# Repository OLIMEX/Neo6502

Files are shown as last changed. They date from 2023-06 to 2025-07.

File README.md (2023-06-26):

# Neo6502
Neo6502 Modern Retro Computer with W65C02S processor and RP2040 memory and peripherals emulator

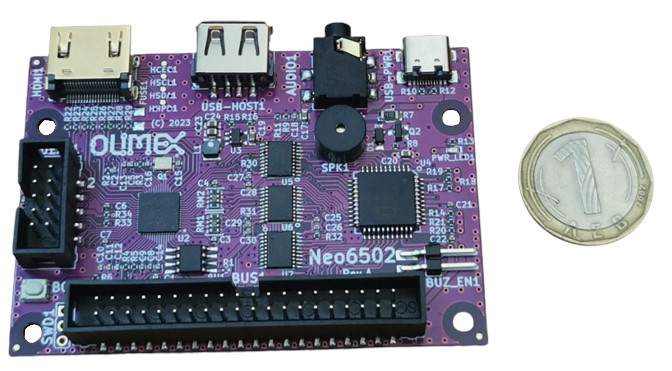
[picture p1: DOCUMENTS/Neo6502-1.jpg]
Neo6502-1


Neo6502 is small board with dimensions 80x55mm.

it consist of real W65C02S processor and RP2040 which emulates RAM memory, video, keyboard, SPI, I2C, UART, GPIOs, Sound

## Intro

W65C02S lives in The Matrix and thinks there is real RAM and other interfaces around it, but the truth is that all this is emulation of the real life. The RP2040 emulates the RAM memory, video, IO and even clock the W65C02S by PWM.

## Features

Neo6502 has these features:

* W65C02S processor
* RP2040 SOC with 2MB Flash
* DVI video on HDMI connector
* USB host for keyboard
* Audio 3.5mm output
* Speaker with enable jumper
* USB-C for power supply
* UEXT connector with I2C, UART and SPI
* 40 pin 6502 bus connector with all W65C02 signals
* Dimensions 80x55mm
* 4 mount holes

## Licenses

* Hardware is released under CERN Open Hardware Licence Version 2 - Strongly Reciprocal, all silkscreen credits to Olimex should remain;
* Software is released under GPL3 Licensee
* Documentation is released under CC BY-SA 3.0

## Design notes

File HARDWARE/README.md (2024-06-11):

Contains hardware design files for Olimex Neo6502

Board was designed with free Open Source CAD software - KiCAD, if you have trouble opening the design files use newest KiCAD version.

Folder "3D printed Case" contains STL files for multi material 3D printing of the encolosure.

STL files are designed with Fusion 360

Notable hardware revision changes:

revision B1
======
1. Added diode 1N5819/S4 on FUSE1 pads to enable 5V on HDMI (diode is used to prevent HDMI powering the board). You can try this adjustmest if you have older revision (with nothing placed over FUSE1) and problems with monitor, remember diode has direction and cathode has to be towards the HDMI connector.

revision B
======

1. Changed values P-B-V-40-LF and P-B-V-10-LF;
2. R7 set to 47R/R1206;
3. Added SWITCH1 for the speaker and signals go to the UEXT in case somebody needs them;
4. Added Neo6502 logo;
5. R1 changed NA to 10K;
6. Added attributions names and e-mail at the bottom;
7. C15 and C16 now 18pF;
8. A lot of small adjustmets to reduce soldering problems and yield.

revision A
======

Initial release.

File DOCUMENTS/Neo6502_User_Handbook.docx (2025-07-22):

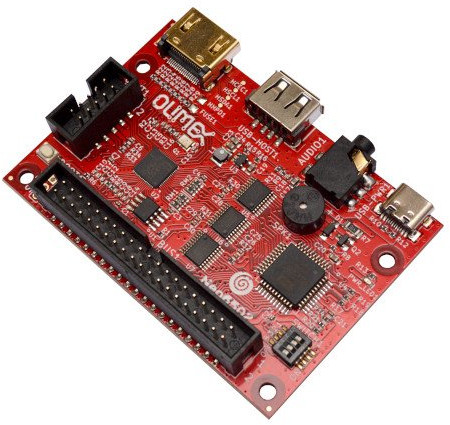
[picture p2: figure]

Neo6502 User Handbook

(Morpheus Firmware)

revision date: 20.07.2025

carefully cobbled together from various sources

slightly rearranged and moderately annotated

main sources:

- Paul Robson www.neo6502.com
- Tsvetan Usunov https://github.com/OLIMEX/Neo6502/blob/main/DOCUMENTS/Neo6502-user-manual.pdf

other sources are stated at the respective texts

all rights remain with the original authors

# 1) Introduction

The design goal of Neo6502 was to make a simple modern retro computer with 6502 processor.

A computer with a modern video interface like HDMI, USB keyboard, and USB flash drive as storage. HDMI output was chosen as everyone has a TV with HDMI input at home and USB keyboards are the mainstream device for input.

With the task to provide HDMI and USB interface we chose RP2040 which already has DVI bit bang project and USB host.

RP2040 also has enough RAM so we decided to use RP2040 to emulate also the RAM memory for 6502.

For the 6502 processor we chose W65C02 from WDC as they are still in mass production and can be purchased freely.

The Neo name was taken for two reasons, first it implies the modern design, then we liked the analogy with the movie The Matrix as W65C02 lives in a virtual world and thinks it has real memory, video, and keyboard but actually all this is virtual and emulated by the RP2040.

Neo6502 is Open Source Hardware, all CAD files, and firmware are available on github, so people can study and modify.

As the main components are a 65C02 and a Raspberry Pi Pico, the 65C02 runs the machine code (at about 6.3Mhz) and the Pico does pretty much everything else.

Most of this document describes its use for a seperate new Retrocomputer design, codenamed „Morpheus“. As such, references to files and example folders mostly apply to the contents of the Morpheus release zip file[^1].

There are other projects which use the board to emulate real machines; currently the Apple 2 and Oric are available, with Commodore 64 in development[^2].

There are other models of this board. Early adopters had a developer version which is almost identical, but Purple rather than Red, and which required a couple of wires to work properly.[^3]

There is also a 'portable' machine named the Neo6502pc, which has a LCD Screen, 4 UEXT sockets and a built in USB hub.

+ Important notice: If Neo6502 is used without a box be careful of placing it on a metal surface, also be careful of dropping metal objects on top of the PCB! This can lead to short-circuits and damage.

List of features:

- Real 65C02 Processor clocked at 6.25 Mhz executing every instruction as it was executed in early retro computers, no emulation for the processor, all timing is exact
- RP2040 with 2MB of SPI Flash, easy to load new firmware via drag and drop virtual drive
- "Clean" machine, 64k RAM available
- Storage USB Key (optionally can use SD Card)
- USB Mouse and Gamepad support
- Audio buzzer which you can enable/disable
- Audio 3.5mm connector for external audio amplifier
- Wifi support (requires additional inexpensive board)
- 6502 BUS connector with all signals
- UEXT interface to access a wide range of hardware add ons
- BASIC support for Serial, I2C and SPI hardware via UEXT Connector
- Fast structured BASIC with hardware support and inline assembler
- BASIC can be edited on screen, or using a text editor
- 320 x 240 256 colour display on HDMI/DVI with a palette
- 32k Graphics RAM for tiles and sprites
- 128 sprites up to 32x32 pixels
- Multiple tile maps (16x16 tiles, can be double sized)
- High speed drawing features
- Turtle Graphics
- Blitter for high speed graphics
- 4 channels of square wave or white noise sound
- Predefined set of sound effects.
- High Speed Integer/Floating point arithmetic
- Cross development support
- Accurate cross platform emulator for Windows/Mac/Linux, only requires SDL2
- Serial link to PC for Cross-Development
- Program in PASCAL using Mad Pascal compiler
- Program in 'C' using CC65 and LLVM
- All software and hardware is open source
- Documentation, samples, explainers and games, all open source
- Low cost purchase, sold for 30 Euros

#### Where can you buy a Neo6502?

Olimex (Europe and worldwide)

https://www.olimex.com/Products/Retro-Computers/Neo6502/open-source-hardware

The home of the Neo6502 is Plovdiv in Bulgaria, and all the hardware can be bought from Olimex, who deliver worldwide.

#### Authorised Resellers

#### Mouser (Worldwide)

https://eu.mouser.com/ProductDetail/Olimex-Ltd/Neo6502?qs=VJzv269c%252BPb5v1hcPBvA4w%3D%3D

Mouser stock Neo6502s for next day delivery.

#### The Pi Hut (UK)

https://thepihut.com/products/olimex-neo6502

For UK residents the Pi Hut is an option.

#### Agon Australia (Australia ... unsurprisingly)

https://www.tindie.com/products/agon/neo6502-rev-b-available-now/

Supporters of the truly dreadful Agon Light (note: this is not serious, it's a great piece of hardware) have come to their senses and have started stocking the Neo6502.

#### DigiKey (Worldwide)

https://www.digikey.nl/en/products/detail/olimex-ltd/NEO6502/22078296

Digikey stock Neo6502s for next day delivery

Missing suppliers who wish to be added contact me on Discord

# 2) Getting Started

Wire up the board. The board turns on as soon as power is supplied. It comes pre-flashed with an Apple 2 emulator and ProDos. For the emulator to run without major issue, leave all the dip switches in the ON position. F12 key is reset.[^4] For further information on ProDos, see: https://prodos8.com/

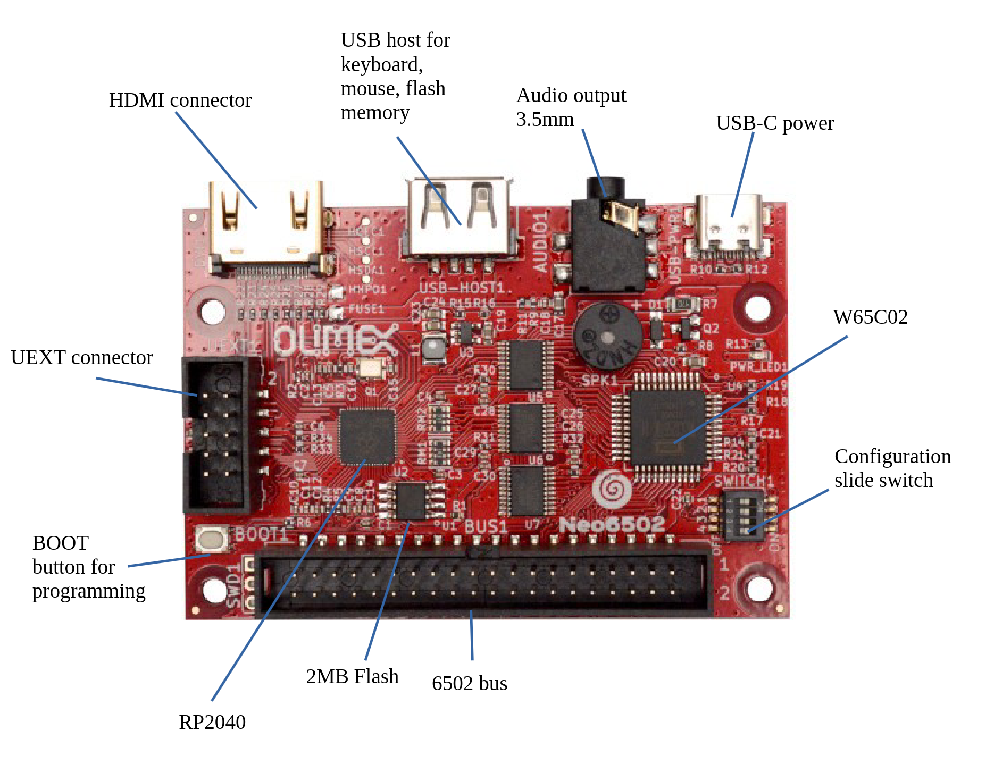
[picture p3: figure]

This next section helps you get the board up and running with the Morpheus firmware. If you want to use the Apple, Oric or C64 emulators, or any other firmware, the process is similar, but you use a different UF2 file.

#### Setting the DIP switches

There is a small configuration slide switch next to the long connector on one side of the board, marked "SWITCH1". Olimex supplies these as "all on" (as per the diagram above).

The first switch enables and disables the buzzer. Switches 2-4 connect UEXT lines to NMI, IRQ and Reset (see back side of the board) and it is strongly recommended that these are set to off.

#### USB Key

The USB key should be formatted to FAT32.

#### Wiring it up

1. Plug the HDMI Monitor into the HDMI connector using a standard HDMI cable.
2. Plug the USB hub, if you are using one, or the keyboard, into the USB host socket and plug the Gamepad, USB Key and Keyboard into the USB host
3. Plug the power cable into the USB C socket, and connect the other end to power.

As stated above, this should boot up the Apple 2 emulator, which should appear in the form of a menu of games, which you can select and run using the keyboard.

If not, try removing the USB host and just plugging the keyboard into the middle socket.

If this doesn't work, try reprogramming it with Morpheus (see below) and see what happens there.

#### Note for SD Card users

If you are using the SD card it should come with a short ribbon cable which plugs into the SDCard board and the UEXT socket on the Neo6502 board.

## Flashing the Morpheus Firmware

First you need to download the current release of the Morpheus software here:

https://github.com/paulscottrobson/neo6502-firmware

The releases are on the right of the screen. Clicking on it should show the releases page which has a link to "neo6502.zip"

Download and extract this file. You will see something like this, this is Linux, but it will be very similar on Windows or Macintosh.

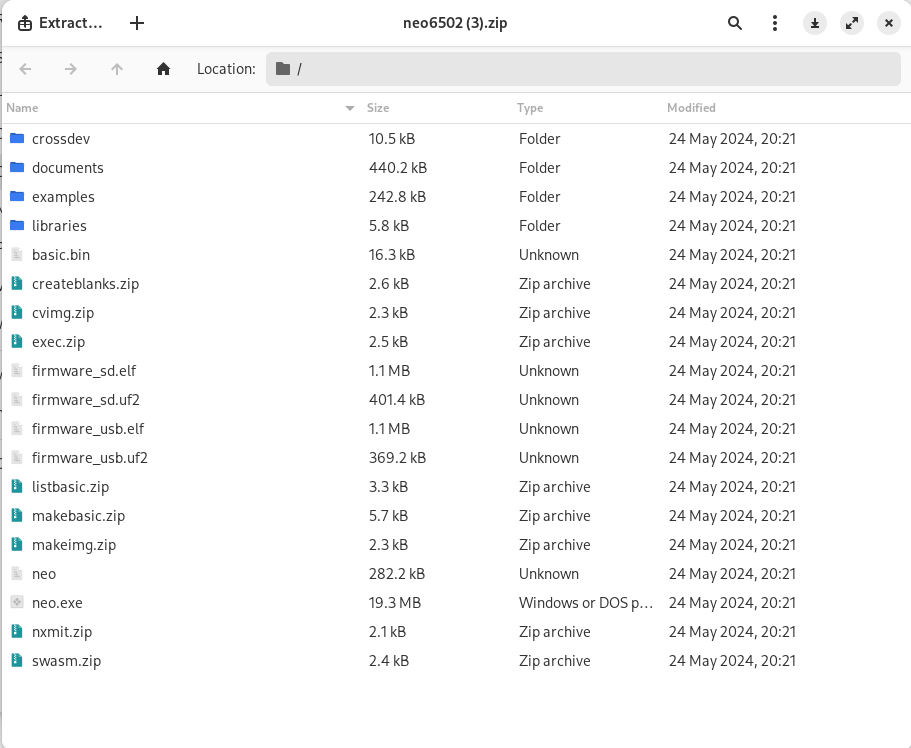
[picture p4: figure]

Initially you need one of the two files in the middle: "firmware_usb.uf2" or "firmware_sd.uf2". Most people will need the first one, the second one is if you use an SD Card for storage.

You can also copy the examples/basic files to your storage device (normally the USB key). It is recommended you create one file just for testing.

Flash the new firmware as follows:

1. Disconnect everything from the board.
2. You now need to put the board into "Upload" mode. This is a similar upload to any other Pi Pico device. Hold the boot button down (see the picture above) and connect the board to your PC via the USB-A port, then release the boot button. If you have already put the board in the case there is a hole to access the boot button which needs something thin and pointy (I use an old multimeter probe).

The board should now appear in the file system of your host computer. For example, on Linux/Gnome it is like shown below. Exactly what you see will depend on your operating system and desktop, but you should see "RPI-RP2" mounted as a drive.

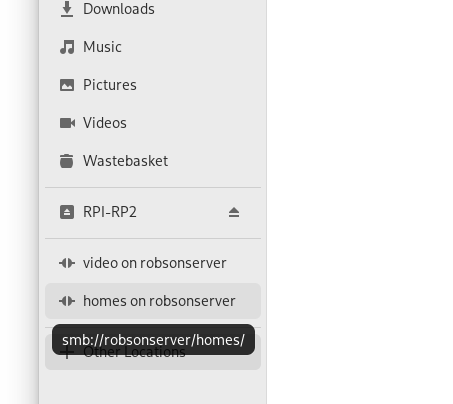
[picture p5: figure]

You now need to copy the uf2 file to this drive. This again depends on the system you are using, but drag-and-drop usually works fine.

Hopefully the board should reboot now. The machine should make it's boot sound (a low beep and a high beep - it sounds like a BBC Micro) listen here (https://www.youtube.com/watch?v=Nd9MzxIbuQI) . Disconnect the board from your PC and wire it as as discribed above. On boot it should display the Neo6502 logo, title, and Olimex title.

#### What does the boot screen mean

Below the logos, you should see:

##### Morpheus Version

The Morpheus title and version in Pink.[^5]

##### Storage Type

It should say "USB Storage" or "SD Card Storage" depending on your choice of firmware

##### USB Devices

Depending on what you connected, our USB devices should now be listed in a similar fashion to:

- No driver found for 04D9:0006
- USB Key found 0781:55a3
- Gamepad driver found 081f E401

In case not all devices are detected, this does not matter.

#### Check it works and doing a Catalogue

Below the USB list it should say "Welcome to NeoBasic" in green. You are now running a classic BASIC interpreter - so for example

print 22/7 [ENTER]

causes 3.142857 to be printed. If you type

cat

it should list all the files in the root directory of the USB key, albeit not in any particular order.

Try the following commands:

cls clears the screen

*cd (directory) change to directory

mon enters a machine code monitor

who displays the contributors list

[ESC] interrupts a BASIC program

[CTRL] + [LEFT ALT] + [RIGHT ALT (Gr)] resets the machine

Note that commands and filenames are not case-sensitive.

## Running a simple BASIC program

To get you started, and show you some of our neater features, we will write a very simple BASIC program, which many of you will have seen many times.

10 for i = 1 to 10

20 print "Hello, world !"

30 next

and type run to run it, like this:

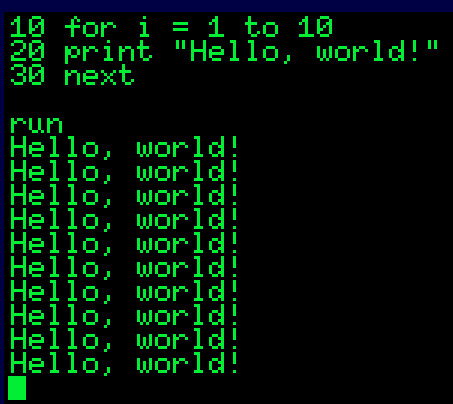
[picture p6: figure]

#### Editing, Saving, Loading and "Cat"ting

Morpheus comes with an on screen editor[^6]. You can move the arrow keys up and make the 10 at the end of line 10 to 20, press [ENTER] and run it again.

You can save your program with

save "hello.bas"

It is a convention that .bas is used for BASIC files, but it's not mandatory. You can reload it withload "hello.bas" and run it with run "hello.bas"

cat should show it stored in the directory. If you have lots of files already you can

cat "hell" which will show all files with hell in it.

## Where Next

So you now have a working Neo6502. Here are some places to explore.

#### Discord

There is an active discord where you can ask questions or whatever of the people involved in software and hardware, and ask for assistance.

There is a link to join it https://discord.gg/tTtarCcrzf

#### Facebook

There is a facebook group https://www.facebook.com/groups/745798620676673

#### Programming Languages available

C and Pascal development are currently working well (both LLVM and CC65) as well as Assembler and BASIC. Forth and a variant are currently under development. There is an early version of LLVM documentation and a more complete Pascal example on the wiki page[^7].

#### Other software

Other software is available, linked from the Wiki, now including a Tile map and Sprite editor, and a file manager, and some games.

#### Assembler, BASIC, C and Pascal examples

Under the "examples" folder are a variety of sample programs some of which are full programs, some demonstrate specific features of BASIC or the API. The .bsc files are text versions of the BASIC files.

#### The Youtube series

There is a 7 part youtube video series of about 30 minutes (https://www.youtube.com/watch?v=FbcAHRVTqpE&list=PLP0Pow806SUMAOoiHSks_xqrspu9pPwnN) which walks through programming a simple game in BASIC using cross development and external tools. Much of it is applicable to C and Pascal which uses the same API - many BASIC commands are simple wrappers round the API functions.

# 3) Software

## Starting programs at boot

On start, if there is a program called "autostart.bas" in the root directory of the storage medium, it will be run.

If this file does not exist, or the "A" key is held on power on, then this will be skipped.

This file can be created like any other BASIC file.

## Keyboard Locales

Locales are available for the following

- US (default)
- DE (Germany)
- FI (Finland)
- GB (Great Britain)
- IT (Italy)
- CH (Switzerland)
- SW (Sweden)

To create additional locale, base it on the files here (https://github.com/llvm-mos/llvm-mos-sdk/) and either create it as a pull request or send it to me personally.

The locale is set using the command: locale "abbr."

This can be included in the autostart.bas boot program, e.g.:

10 locale "GB"

Note: at present we only support ASCII characters 32-127

Example for an autostart.bas:

10 locale "GB" 'sets locale to Great Britain
20 fkey 10,chr$(12) 'maps CLS on F10
30 new 'clears autostart.bas from the BASIC interpreter

## Using MOS commands to access File functionality

The MOS interface is a way of accessing system functions such as delete, rename and so on, in one of three ways

- they can be typed in at the command line with an asterisk (e.g. *del myfile.txt)
- they can use the API function which takes a string in group 2
- they can use the BASIC command which takes a string (e.g. mos "del myfile.txt" )
- they can use the BASIC function which takes a string (e.g. print mos("del myfile.txt") )

Parameters can be delimited using spaces, single quotes or double quotes

The following commands are supported

- *. or cat , same as CAT, directory listing with mask
- *del (file) deletes a file
- *copy (file1) (file2) copies a file
- *file (file) checks a file exists
- *ren (file1) (file2) renames a file
- *md (directory) create directory
- *cd (directory) change to directory

These commands should remain unchanged but may be extended arbitrarily.

## BASIC Commands (Graphics)

The graphics commands are

- MOVE,
- PLOT (draws a pixel),
- LINE (draws a line)
- RECT (draws a rectangle)
- ELLIPSE (draws a circle or ellipse)
- IMAGE (draws a sprite or tile),
- TILEDRAW (draws a tilemap) and
- TEXT (draws text)

The keywords are followed by a sequence of modifiers and commands which do various things as listed below

Keyword | Notes
from x,y | Sets the origin position, can be repeated and optional.
to x,y | Draw the element at x,y or between the current position and x,y depending on the command. So you could have text "Hello" to 10,10 or rect 0,0 to 100,50
by x,y | Same as to but x and y are an offset from the current position
x,y | Set the current position without doing the action
ink c | Draw in solid colour c, to be placed directly after the graphics command
ink a,x | Draw by anding the colour with a, and xoring it with x.
solid | Fill in rectangles and ellipses. For images and text, forces black background.
frame | Just draw the outline of rectangles and ellipses
dim n | Set the scaling to n (for TEXT, IMAGE, TILEMAP only), so text "Hello" dim 2 to 10,10 to 10,100 will draw it twice double size. Tiles can only be 1 or 2 (when 2, tiles are drawn double size giving a 32x32 tile map)

These can be arbitrarily chained together so you can do (say) LINE 0,0 TO 100,10 TO 120,120 TO 0,0 to draw an outline triangle. You can also switch drawing type in mid command, though I probably wouldn't recommend it for clarity.
State is remember until you clear the screen so if you do INK 2 in a graphics command things will be done in colour 2 (green) until finished.
TEXT is followed by one parameter, which is the text to be printed, these too can be repeated

TEXT "Hello" TO 10,10 TEXT "Goodbye" DIM 2 TO 100,10

IMAGE is followed by two parameters, one specifies the image, the second the 'flip'. These can be repeated as for TEXT.
The image parameter is 0-127 for the first 128 tiles, 128-191 for the first 64 16x16 sprites and 192-255 for the first 64 32x32 sprites. The flip parameter, which is optional, is 0 (no flip) 1 (horizontal flip) 2 (vertical flip) 3 (both). An example would be

image 4 dim 2 to 10,10 image 192,3 dim 1 to 200,10

Note that images are $not$ sprites or tiles, they use the image to draw on the screen in the same way that LINE etc. do.

Colourcode | Colour
0 | Black/Transparent
1 | Red
2 | Green
3 | Yellow
4 | Blue
5 | Magenta
6 | Cyan
7 | White
8 | Black
9 | Dark Grey
10 | Dark Green
11 | Orange
12 | Dark Orange
13 | Brown
14 | Pink
15 | Light Grey

## Sprite Commands

Sprite commands closely resemble the graphics commands.

They begin with

- SPRITE {n} which sets the working sprite. Options include
  - IMAGE {n} which sets the image,
  - TO {x},{y} which sets the position,
  - FLIP {n} which sets the flip to a number (bit 0 is horizontal flip, bit 1 is vertical flip),
  - ANCHOR {n} which sets the anchor point and
  - BY {x},{y} which sets the position by offset.

With respect to the latter, this is the position from the TO and is used to do attached sprites e.g. you might write.

SPRITE 1 IMAGE 2 TO 200,200 SPRITE 2 IMAGE 3 BY 10,10

Which will draw Sprite 1 and 200,200 and sprite 2 offset at 210,210. It does not offset a sprite from its current position.

As with Graphics these are not all required. It only changes what you specify not all elements are required each time SPRITE 1 IMAGE 3 is fine.

SPRITE can also take the single command CLEAR ; this resets all sprites and removes them from the display

Sprite 127 is used for the turtle sprite, so if the turtle is turned on, then it will adjust its graphic, size to reflect the turtle position. If turtle graphics are not used, it can be used like any other.

Implementation notes

Up to 128 sprites are supported. However, sprite drawing is done by the Pico and is not hardware, so more sprites means the system will run slower.

Additionally, the sprites are currently done with XOR drawing, which causes effects when they overlap. This should not be relied on (it may be replaced by a clear/invalidate system at some point), but the actual implementation should not change.

This is an initial sprite implementation and is quite limited.

(The plan is to add a feature like the animation languages on STOS and AMOS which effectively run a background script on a sprite)

Sprite Support

=spritex(n) =spritey(n)

These return the x and y coordinates of the sprites draw position (currently the centre) respectively.

= hit(sprite#1,sprite#2,distance)

The hit function is designed to do sprite collision. It returns true if the pixel distance between the centre of sprite 1 and the centre of sprite 2 is less than or equal to the distance.

So if you wanted to move a sprite until it collided with another sprite, assuming both are 32x32, the collision distance would be 32 (the distance from the centre to the edge of both sprites added together), so you could write something like :

x = 0

repeat

x = x + 1: sprite 1 to x,40

until hit(1,2,32)

In my experience of this the distance needs to be checked experimentally, as it affects the 'feel' of the game ; sometimes you want near exact collision, sometimes it's about getting the correct feel. It also depends on the shape and size of the sprites, and how they move.

I think it's better than a simple box collision test, and more practical than a pixel based collision test which is very processor heavy.

## Turtle Graphics

The Neo6502 has a built in turtle graphics system. This uses sprite $7F as the turtle, which it will take over, so it cannot be used for other purposes.

The following commands are supported.

Command | Purpose
forward {n} | Move turtle forward n (pixel distance)
left {n} | Rotate turtle at current position
right {n}
penup | Does not draw as the turtle moves
pendown | Draw as the turtle moves in the current colour
pendown {n} | Draw as the turtle moves in colour {n}
turtle home | Reset turtle to home position, facing up the screen.
turtle hide | Hide the turtle
turtle show | Show the turtle
turtle fast | The turtle is deliberately slowed to give it an animated feel so you can see the drawing, this is because it's primary purpose is educational. This makes it go full speed.

There is an example in the crossdev folder which gives some idea on how to get started.

## Sound Commands

The Neo6502 has four sound channels, 0-3 which can generate a square wave or white noise sounds. The main sound command is called "sound" and has the following forms:

#### Sound clear

Resets the entire sound system, silences all channels, empties all queues

#### Sound {channel} clear

Resets a single channel ; silences it, and empties its queue

#### Sound {channel},{frequency},{time}[,{slide}]

Queues a note on the given channel of the given frequency (in Hz) and time (in centiseconds). These will be played in the background as other notes finish so you can 'queue up' an entire phrase and let it play by itself. The slide value adds that much to the frequency every centisecond allowing some additional effects (note, done in 50Hz ticks)

A mixture of the two syntaxes SOUND 0 CLEAR 440,200 is now supported. To use the white noise feature use the keyword "noise" instead of sound.

sfx plays sound effects. Sound effects are played immediately as they are usually in response to an event. It's format is: sfx {channel},{effect id}

ID | Sound
0 | positive
1 | negative
2 | error
3 | confirm
4 | reject
5 | sweep
6 | coin
7 | las70
8 | powerup
9 | victory
10 | defeat
11 | fanfare
12 | alarm 1
13 | alarm 2
14 | alarm 3
15 | ringtone 1
16 | ringtone 2
17 | ringtone 3
18 | danger
19 | expl100
20 | expl50
21 | expl20
22 | las30
23 | las10

## Using the BASIC Text Editor

The developers decided it would be better to have a proper editor. (It is possible to cross-develop in BASIC using the emulator or the serial port)

So type edit and press ENTER

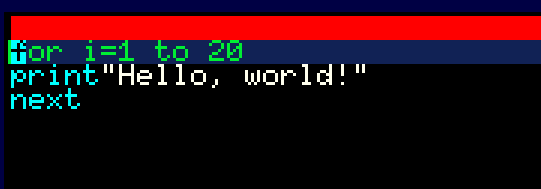
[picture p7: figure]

You can edit like on a word processor (Ctrl+P and Ctrl+Q insert/delete lines). This currently supports left, right, home, end, backspace and delete on the current line, enter, up, down, page up and page down to change lines.

Note the editor is slightly eccentric. It is not a text editor, what it is doing is editing the underlying program on the fly -- much the same as if you were typing lines in.

The editor uses its own line numbers, so is not compatible with their use in programs. Any program will be renumbered from 1 upwards in steps of 1 (except library routines).

You shouldn't be using line numbers anyway!

When you have finished press ESC to leave the editor and you can run your programm again. You can speed this up using the function keys e.g. from the BASIC command line (e.g. where you type stuff in)

fkey 1,"edit"+chr$(13)

This sets function key F1 on the keyboard to type edit and press ENTER (character code 13).

## Libraries

Libraries are part of the BASIC program, placed at the start. However, their line numbers are all set to zero. (So you cannot use GOTO or GOSUB in libraries, but you should only use them for porting old code).

NEW will not remove them, LIST does not show them (except LIST 0), You cannot edit them using the line editors.

However RUN does not skip them. This is so you can have initialisation code e.g.

{do initialisation code}

if false

proc myhw.dosomething(p1) ....

proc myhw.panic()

endif

To support this, there is a LIBRARY command. LIBRARY on its own undoes the library functionality. It renumbers the whole program from the start, starting from line number 1000.

Otherwise LIBRARY works like LIST. You can do LIBRARY {line} or LIBRARY {from},{to} and similar. Instead of listing this code, it causes them to "vanish" by setting their line numbers to zero.

They are also supported in the makebasic script. Adding the command library makes all code so far library code.

e.g.

python makebasic.zip mylib.bsc library mainprogram.bsc

## The Inline Assembler

The inline assembler works in a very similar way to that of the BBC Micro, except that it does not use the square brackets [ and ] to delimit assembler code. Assembler code is in normal BASIC programs.

A simple example shown below (and in the samples directory). It prints a row of 10 asterisks.

Most standard 65C02 syntax is supported, except currently you cannot use lsr a ; it has to be just lsr (and similarly for rol, asl, ror,inc and dec).

You can also pass A X Y as variables. So you could delete line 150 and run it with X = 12: sys start which would print 12 asterisks.

Line | Code | Notes
100 | mem = alloc(32) | Allocate 32 bytes of memory to store the program code.
110 | for i = 0 to 1 | We pass through the code twice because of forward referenced labels. This actually doesn't apply here.
120 | p = mem | P is the code pointer -- it is like $* = {xx} - it means put the code here
130 | o = i * 3 | Bit 0 is the pass (0 or 1) Bit 1 should display the code generated on pass 2 only, this is stored in 'O' for options.
140 | .start | Superfluous -- creates a label 'start' -- which contains the address here
150 | ldx #10 | Use X to count the starts
160 | .loop1 | Loop position. We can't use loop because it's a keyword
170 | lda #42 | ASCII code for asterisk
180 | jsr $fff1 | Monitor instruction to print a character
190 | dex | Classic 6502 loop
200 | bne loop1
210 | rts | Return to caller
220 | next | Do it twice and complete both passes
230 | sys mem | BASIC instruction to 'call 6502 code'. Could do sys start here.

### [ ] Operator

The [] operator is used like an array, but it is actually a syntactic equivalent of deek and doke, e.g. reading and writing 16 bytes. mem[x] means the 16 bit value in mem + x $* 2, so if mem = 813 then mem[2] = -1 writes a 16 bit word to 817 and 818, and print mem[2] reads it. The index can only be from 0..127

The purpose of this is to provide a clean readable interface to data in 65C02 and other programs running under assembly language ; often accessing elements in the 'array' as a structure.

## Further Programming

### Mad Pascal

By Tomasz Biela / Text by Wojciech Bocianski

Mad-Pascal (https://github.com/tebe6502/Mad-Pascal/releases) is a highly optimized and continuously developed cross-compiler for the Pascal language for the 6502 (https://en.wikipedia.org/wiki/MOS_Technology_6502) family of processors. Initially created for the Atari platform, it has since been adapted for several other target platforms, including neo6502.

Compilation to machine code is a two-step process. In the first step, the code is compiled to assembler source code compatible with the MADS (https://github.com/tebe6502/Mad-Assembler/releases) assembler, and then the code is assembled into an executable machine code file.

The following guide will help you set up a complete development environment, tailored for quick and convenient coding on the neo6502 on your PC. We will also write our first program together, compile it, and run it in an emulator.

#### Installing the Emulator

The first thing we will need is the latest version of the neo6502 emulator so that we can test our software on a development machine. Download it from the project's official GitHub: https://github.com/paulscottrobson/neo6502-firmware/releases

All we need for now is the emulator executable. It is located in the root directory of the downloaded archive and is simply named neo (neo.exe for Windows). Let's place it in an easily accessible directory. For the purposes of our guide, let it be the following directory:

Windows | Linux
d:/neo6502/neo.exe | ~/neo6502/neo

Note that the downloaded archive also contains a documents directory, which includes a detailed description of the API functions provided by the firmware of our device. It will certainly come in handy during our adventures with programming on the neo6502, so it's worth keeping it nearby.

#### Downloading and Compiling the Assembler and Mad-Pascal Compiler

I recommend always using the latest version of the MADS assembler and Mad-Pascal compiler, which we will compile from the sources in a moment. For this purpose, we will need the git (https://git-scm.com/downloads) tool and the free FreePascal (https://www.freepascal.org/) compiler. Both tools should be downloaded from the above links and installed.

Now, using git, we will download the latest versions of the assembler and compiler and then compile them.

#### Windows

Open a console (cmd), navigate to the directory where you want to install the compilers (in our example D:), and then execute the following commands:

git clone https://github.com/tebe6502/Mad-Assembler.git

cd Mad-Assembler

fpc -Mdelphi -vh -O3 mads.pas

cd ..

git clone https://github.com/tebe6502/Mad-Pascal.git

cd Mad-Pascal/src

fpc -Mdelphi -vh -O3 mp.pas

copy mp.exe ..

#### Linux

In the directory where you want to install the compilers (in our example in the home directory ~), enter the following console commands:

git clone https://github.com/tebe6502/Mad-Assembler.git

cd Mad-Assembler

fpc -Mdelphi -vh -O3 mads.pas

cd ..

git clone https://github.com/tebe6502/Mad-Pascal.git

cd Mad-Pascal/src

fpc -Mdelphi -vh -O3 mp.pas

cp mp ..

Be careful because the -O3 parameter is an uppercase "o", not a zero.

#### Writing Our First Program

Now let's write our first Pascal program and save it in the project directory as hello.pas:

program hello;

begin

Writeln('Hello neo6502!');

end.

Let's try to compile it manually:

Windows | Linux
D:\Mad-Pascal\mp.exe hello.pas -target:neo -code:5000 | ~\Mad-Pascal\mp hello.pas -target:neo -code:5000

The -code:5000 option will cause our program code to be compiled at address $5000 (20480). This is an example value; you can compile the code to any location, just remember not to overwrite areas used by the firmware (you can find the memory map in the emulator archive in the documents\basic.pdf directory). As a result of the compilation, an intermediate assembler file hello.a65 will be created in the project directory. In the next step, we will assemble this program into machine code, i.e., the target executable file.

Windows | Linux
D:\Mad-Assembler\mads.exe hello.a65 -x -i:D:\Mad-Pascal\base -o:hello.bin | ~\Mad-Assembler\mads hello.a65 -x -i:~\Mad-Pascal\base -o:hello.bin

The -x option causes potentially unused procedures to be removed during the assembly process, which is beneficial for us as the resulting file will be smaller. The path after the -i parameter indicates the directory with the base Mad-Pascal libraries, and the -o parameter allows you to specify the name of the output file, which should appear in the project directory after the assembly.

Let's try to run it in the emulator.

Windows | Linux
D:\neo6502\neo.exe hello.bin@5000 run@5000 | ~\neo6502\neo hello.bin@5000 run@5000

Hooray! We have successfully written our first program in Mad-Pascal for neo6502! Notice that in the emulator call, we need to specify the compilation and run address consistent with the one provided during the initial compilation.

Entering all these commands each time would be terribly inconvenient and time-consuming, so we will automate this process for our convenience and save time.

#### Preparing Batch Files for Source Compilation

In the directory of our first project, let's prepare a batch file that will do the hard work for us and carry out the process of compiling and running any Pascal file.

#### Windows

Let's create a batch file build.bat

@setlocal

@SET MPPATH=D:\Mad-Pascal

@SET MADSPATH=D:\Mad-Assembler

@SET NEOPATH=D:\neo6502

@SET ORG=5000

@SET NAME=%1

%MPPATH%\mp.exe %NAME%.pas -target:neo -code:%ORG%

@if %ERRORLEVEL% == 0 %MADSPATH%\mads.exe %NAME%.a65 -x -i:%MPPATH%\base -o:%NAME%.bin

@if %ERRORLEVEL% == 0 %NEOPATH%\neo.exe %NAME%.bin@%ORG% run@%ORG%

#### Linux

Let's create a batch file build.sh

#!/usr/bin/bash

MPPATH=~/Mad-Pascal

MADSPATH=~/Mad-Assembler

NEOPATH=~/neo6502

ORG=5000

NAME=${1}

$MPPATH/mp ${NAME}.pas -target:neo -code:${ORG} && \

$MADSPATH/mads ${NAME}.a65 -x -i:${MPPATH}/base -o:${NAME}.bin && \

$NEOPATH/neo ${NAME}.bin@${ORG} run@${ORG}

In the Linux system, the build.sh file must have execution rights:

chmod +x build.sh

Let's try to compile and run our first program using the batch file.

Windows | Linux
build.bat hello | ./build.sh hello

And if everything went well, you should see the compilation process in the console window, and then the emulator window with our first program running. If something went wrong, make sure you have the correct paths in the batch file.

Of course, you can modify and customize this batch file as you see fit, or write it completely differently. This is just an example that I hope will encourage you to experiment with Mad-Pascal.

#### Libraries for neo6502

The bare "naked" Mad-Pascal will allow us to write simple programs in text mode, but to fully exploit its capabilities on the neo6502, several additional libraries have been created. They help in communication with the device's firmware and provide full support for color graphics, sprites, tile maps, controllers, and all functions provided by the system's API.

These libraries are available to you without any additional steps as they are already part of the Mad-Pascal compiler distribution.

Library Name | Description
NEO6502 (https://bocianu.gitlab.io/neo-mplibs/neo6502.html) | Main API function library for Neo6502
NEO6502KEYS (https://bocianu.gitlab.io/neo-mplibs/neo6502keys.html) | Library for reading keyboard state using HID codes.
NEO6502MATH (https://bocianu.gitlab.io/neo-mplibs/neo6502math.html) | Library for accelerating mathematical calculations and some other operations
NEO6502UEXT (https://bocianu.gitlab.io/neo-mplibs/neo6502uext.html) | Input/output interface function library for UEXT

Link to full documentation: https://bocianu.gitlab.io/neo-mplibs/

To use these libraries, simply add their names in the uses clause.

program api;

uses neo6502, crt;

begin

ClrScr;

NeoBeep;

NeoCredits;

repeat until KeyPressed;

end.

#### Sample Programs

More sample programs utilizing specific neo6502 functions can be found in the Mad-Pascal directory in the Mad-Pascal\samples\neo6502\ subfolder. These are good examples to start with and to begin your adventure with this compiler.

And if you'd like to look at the source code of larger projects in Mad-Pascal, check out bocianu's GitLab (https://gitlab.com/bocianu), who has written several games and tools for the neo6502.

### CC65

There are two references on using CC65

Pete Gollan wrote the following, which has a sample project that can be used as a starter

https://github.com/PeteGollan/Neo6502-programs/tree/main/HelloNeo6502-CC65

Andy McCall wrote a walkthrough and example code on using a combination of LLVM-MOS and CC65 here, which is Linux / Mac centric but the basic ideas could be adapted for Windows.

https://github.com/andymccall/neo6502-development

There are some C examples in the release, but they are considerably more primitive.

### LLVM-Mos

With the new version of llvm-mos, which natively supports neo6502, you can compile your C source code (even written for the CC65 compiler) without modifying the code. Pay attention to the warnings; llvm-mos is much stricter than CC65.

Download here (https://github.com/llvm-mos/llvm-mos-sdk/): https://github.com/llvm-mos/llvm-mos-sdk/

Compile the source following the instruction inside the page

You will find useful files in the directory:

$(LLVM_MOS_SDK)/bin/mos-neo6502-clang

If you're starting from scratch, you can use the high-level functions for writing to the API mailbox. See the directory:

$(LLVM_MOS_SDK)/mos-platform/neo6502/include

Here's an example of the command to compile the code:

$(LLVM_MOS_SDK)/bin/mos-neo6502-clang main.c -o main.neo

If you use the -Os option, which allows you to have optimized code, remember that the variables with which you call the library should be of type "volatile." Don't make the same mistake as I did. If you use the LLVM_MOS high-level functions don't worry about this. And here's an example of the command to compile the optimized code:

$(LLVM_MOS_SDK)/bin/mos-neo6502-clang -Os main.c -o main.neo

If you're using VSCode to write the code, add the directory $(LLVM_MOS_SDK)/mos-platform/neo6502/include to the IncludePath variable.

In the directory, you can find an example of using the API mailbox functions:

$(LLVM_MOS_SDK)/examples/neo6502

### Assembler

Currently the best start point for assembler are the examples in the release directory.

Also, check the BASIC inline assembly examples.

Op-Codes:

https://www.pagetable.com/c64ref/6502/?cpu=65c02s&tab=0

CPU Spec-Sheet:

https://github.com/OLIMEX/Neo6502/blob/main/DOCUMENTS/w65c02s-NEW.pdf

### Tali Forth

By Scot Stevenson

https://github.com/SamCoVT/TaliForth2

https://www.olimex.com/Products/Retro-Computers/Neo6502/resources/taliforth.neo

Introduction

Tali Forth 2 is a subroutine threaded code (STC) implementation of an ANS-based Forth for the 65c02 8-bit MPU. The aim is to provide a modern Forth that is easy to get started with and can be ported to individial hardware projects, especially Single Board Computers (SBC), with little effort. It is free -- released in the public domain -- but with absolutely no warranty of any kind. Use at your own risk! (See COPYING.txt for details.) Tali Forth 2 is hosted at GitHub. You can find the most current version at https://github.com/SamCoVT/TaliForth2.

A little more detail please

Tali Forth 2 aims to be, roughly in order of priority:

- Easy to try. Download the source -- or even just the binary taliforth-py65mon.bin -- and run the emulator with py65mon -m 65c02 -r taliforth-py65mon.bin to get it running. This lets you experiment with a working 8-bit Forth for the 65c02 without any special configuration. This includes things like block wordset.
- Simple. The simple subroutine-threaded (STC) design and excessively commented source code give hobbyists the chance to study a working Forth at the lowest level. Separate documentation - including a manual with more than 100 pages - in the docs folder discusses specific topics and offers tutorials. The aim is to make it easy to port Tali Forth 2 to various 65c02 hardware projects.
- Specific. Many Forths available are "general" implementations with a small core adapted to the target processor. Tali Forth 2 was written as a "bare metal Forth" for the 65c02 8-bit MPU and that MPU only, with its strengths and limitations in mind.
- Standardized. Most Forths available for the 65c02 are based on ancient, outdated templates such as FIG Forth. Learning Forth with them is like trying to learn modern English by reading Chaucer. Tali Forth (mostly) follows the current ANS Standard, and ensures this by passing an enhanced test suite.

The functional reference for Tali is GNU Forth (Gforth, https://www.gnu.org/software/gforth/). Programs written for Tali should run on Gforth or have a very good reason not to. Also, may Gforth words were adapted for Tali, especially when they make the code simpler (like FIND-NAME or BOUNDS).

The first Tali Forth was my first Forth ever. It is hosted at https://github.com/scotws/TaliForth and is superceded by this version. The second version was strongly influenced by what I learned writing Liara Forth for the 65816. Liara and Tali 2 share large parts of their internal logic.

Seriously super lots more detail

See docs\manual.html for the Tali Forth manual, which covers the installation, setup, tutorials, and internal structure. The central discussion forum is http://forum.6502.org/viewtopic.php?f=9&t=2926 at 6502.org.

### Getting Started in Cross Development

There is a file in the release called crossdev.zip which contains a worked example of how to create both graphics and programs, with Windows and Linux support.

#### Command Line

The emulator has several options on the command line.

- "cold" boots BASIC in standard mode, avoiding the monitor
- "warm" boots BASIC in warm start mode, anything in memory will be retained.
- "exec" boots BASIC and runs the program in memory.

Program can be loaded into memory using the syntax <file>@<address in hex>. That address can be "page" which means the address BASIC expects to find the code in.

So to load and run a program use the following (adjusting for where you put the binaries) :

../bin/neo program.bas@page exec

Or in windows

..\bin\neo.exe program.bas@page exec

This performs the following 1. starts the emulator 1. loads the tokenised BASIC program to "page" (changes as BASIC grows) 1. sets it to run 'exec' mode, so it auto runs when it starts.

One can create an example BASIC program from a text equivalent (see the basic/code directory for many examples), this is done with the makebasic.zip program which requires Python 3

Something like

`python3 makebasic.zip source.txt -oprogram.bas

this converts the file "source.txt" which is a basic source file in text form, line numbers optional to a tokenised program which can be run as above.

## CP/M-65

By David Given

https://github.com/davidgiven/cpm65

https://github.com/davidgiven/cpm65/releases/download/dev/neo6502.zip

#### What?

This is a native port of Digital Research's seminal 1977 operating system CP/M to the 6502.

Unlike the original, it supports relocatable binaries, so allowing unmodified binaries to run on any system: this is necessary as 6502 systems tend to be much less standardised than 8080 and Z80 systems. (The systems above all load programs at different base addresses.)

Currently you can cross-assemble programs from a PC, as well as a working C toolchain with llvm-mos. For native development, there's a basic assembler, a couple of editors, a BASIC, and a byte-compiled Pascal subset and interpreter. You need about 20kB to run the assembler at all, and of course more memory the bigger the program.

No, it won't let you run 8080 programs on the 6502!

#### How?

You have two options:

- Download a binary release. (https://github.com/davidgiven/cpm65/releases/tag/dev) You can then copy this onto a disk for booting on a real machine, or use it in an emulator.
- or build it yourself.

#### neo6502 notes

- The neo6502 is a W65C02-based computer using emulated hardware implemented by a RP2040. This can be programmed with various different firmware packages, each emulating a different 6502-based microcomputer. This port is intended for the native firmware package for the neo6502, Morpheus (https://github.com/paulscottrobson/neo6502-firmware/wiki). (The other ports will work if you install the appropriate emulation firmware package.)
- It is ridiculously fast.
- To use, unzip the cpm65.zip file into the any directory of the USB stick or other storage card. Then enter *cd your_directory_name and then load "cpm65.neo" at the prompt. CP/M-65 will run.
- To run on the emulator, either load it as above, or boot it directly with neo CPM65.NEO@8000 run@8010. Remember that if you're running the emulator on Linux, the filesystem is CASE SENSITIVE so you need to spell CPM65.NEO using capital letters. (One CP/M-65 is running this is no longer a concern.)
- This port uses an emulated BDOS, meaning that it stores its files as FAT files on the neo6502's USB stick. Most well-behaved CP/M-65 programs will work, but anything which tries to access the raw filesystem won't; such as STAT or DINFO. Files for each drive and user are stored in separate subdirectories. All 16 drives are supported (in directories A to O).
- Drive B (i.e. /B/ on the storage device) contains some neo6502-specific utilitied. This are in no way complete, or documented.
- The console is 53x30. It has a SCREEN driver.

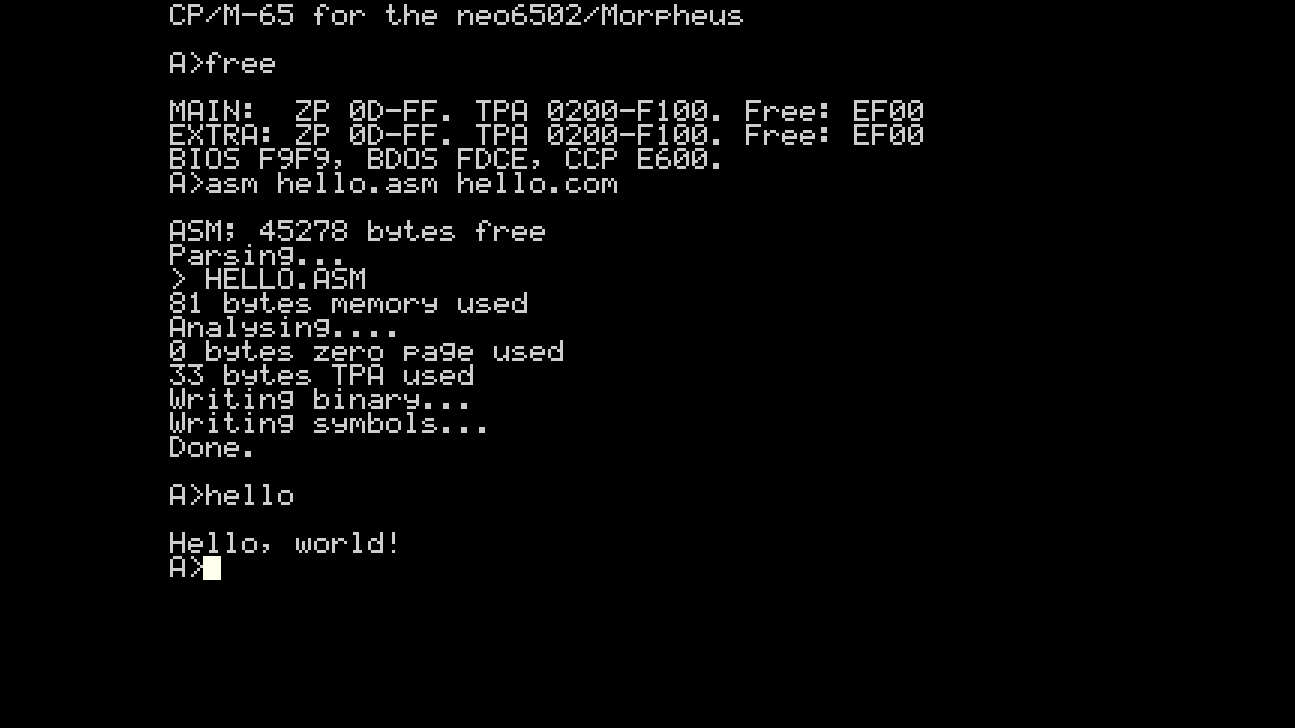
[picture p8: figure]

### Supported programs

Commands include DUMP, STAT, COPY, SUBMIT, ASM, QE and BEDIT plus some smaller utilities. I'd love more --- send me pull requests! The build system supports cc65 assembler and llvm-mos C programs. The native assembler can be used (in emulation) to cross compile programs for CP/M-65.

In the CCP, you get the usual DIR, ERA, REN, TYPE and USER. There is no SAVE as on the relocatable CP/M-65 system assembling images in memory is of questionable utility, but there's a new FREE command which shows memory usage.

You also get a port of Altirra BASIC, an open source Atari BASIC clone. This is called ATBASIC. See below for more details.

Pokey the Penguin loves to read your pull requests (https://github.com/davidgiven/cpm65/compare)!

### The assembler

The CP/M-65 assembler is extremely simple and very much customised to work for the CP/M-65 environment. It operates entirely in memory (so it should be fast) but it's written in C (so it's going to be big and slow). It's very very new and is likely to have lots of bugs. There is, at least, a port of the DUMP program to it which assembles, works, and is ready to play with.

Go read cpmfs/asm.txt (https://github.com/davidgiven/cpm65/blob/master/cpmfs/asm.txt) for the documentation.

### The BASIC

Altirra BASIC is an open source recreation of the BASIC used on the Atari 8-bit machines (on which CP/M-65 runs, coincidentally). It has been heavily modified by me to work on CP/M-65. Anything Atari-related has been removed, including graphics, sound, etc. In addition, I have extended the error reporting, added support for case-insensitive keywords (simply because Atari BASIC traditionally requires upper case but most CP/M-65 platforms don't have caps lock keys!), and fairly crudely added file I/O support. There is no screen editor. It is (should be) binary compatible with Atari BASIC, although programs using Atari features which aren't supported will of course not run.

It is currently rather fragile with a number of known (and, probably, unknown) bugs. Please file bug reports (https://github.com/davidgiven/cpm65/issues/new)!

Atari BASIC is rather different from Microsoft BASIC. Please consult the user manual (https://www.virtualdub.org/downloads/Altirra%20BASIC%20Reference%20Manual.pdf).

Important! Do not contact the author of Altirra BASIC for anything related to the CP/M-65 port! Any bugs are strictly my fault.

### The editors

BEdit is an incredibly simple line editor modelled after a basic interpreter (command entry, with LOAD, SAVE, LIST, line numbers etc). It's written in machine code and assembled with the CP/M-65 assembler; you can assemble it locally if you have a system with 30kB or more TPA. It'll run on all platforms.

Go read cpmfs/bedit.txt (https://github.com/davidgiven/cpm65/blob/master/cpmfs/bedit.txt) for the documentation.

QE is a much less simple vi-inspired screen editor, written in C. it's much more comfortable to use than BEDIT, but is about five times the size, and will only run on systems with a SCREEN driver, as noted above (you can also use the DEVICES command to see what devices your system supports).

DwarfStar is another screen editor. It has the same keybindings as WordStar, so those familiar with that will feel right at home. For a refresher, see the documentation (https://github.com/davidgiven/cpm65/blob/master/third_party/dwarfstar/ds.txt), which was written in DS itself and is also available within CP/M-65 on the systems that have DS.COM installed.

### The Pascal

Pascal-M is a Pascal subset intended for use on very small machines. It compiles to bytecode, M-code, which is then run with an interpreter. The compiler is itself written in Pascal-M and is capable of compiling itself (very slowly). There is a basic port to CP/M-65.

To use it, you need to use the interpreter, PINT, to run the compiler to compile your program into an OBP file. This is then translated into an OBB file by PLOAD (not written in Pascal!). You can then run the resulting OBB file with PINT. For example:

A> PINT PASC.OBB HELLO.PAS HELLO.OBP

A> PLOAD HELLO.OBP HELLO.OBB

A> PINT HELLO.OBB

The compiler will also generate a PROGRAM.ERR file containing a copy of any error messages that result from the compilation process.

Sadly, you need at least 36kB of free RAM to run the compiler, and also the disk images for various systems are full, so it's only included for a few platforms.

Pascal-M is considerably simplified from the full Pascal language, with support for only 16-bit integers, but it does support records, sets, enumerations, pointers, nested functions and procedures, etc. Performance isn't brilliant but it does work. CP/M-65 is very basic, consisting of support for text files using the traditional assign/reset/rewrite/close API. You can have as many open at once as you like but you can't seek inside a file. In addition, while new is supported, there is no dispose.

For more information on Pascal-M, see Hans Otten's website (http://pascal.hansotten.com/px-descendants/pascal-m/pascal-m-2k1/). However, do not report bugs on the CP/M-65 port to him --- file bug reports here (https://github.com/davidgiven/cpm65/issues/new) instead.

### Utilities

bin/cpmemu contains a basic CP/M-65 user mode emulator and debugger. It'll run programs on the host environment with an emulated disk, which is very useful for testing and development. To use:

./bin/cpmemu .obj/dump.com diskdefs

Add -d at the front of the command line to drop into the debugger --- use ? for basic help. It can only access 8.3-format all-lowercase filenames in the current directory, but you can also map drives. Use -h for help.

#### Who?

You may contact me at dg@cowlark.com, or visit my website at http://www.cowlark.com. There may or may not be anything interesting there. The CP/M-65 project was designed and written by me, David Given.

#### License

Everything here so far except the contents of the third_party directory is © 2022-2023 David Given, and is licensed under the two-clause BSD open source license. Please see LICENSE (https://github.com/davidgiven/cpm65/blob/master/LICENSE) for the full text. The tl;dr is: you can do what you like with it provided you don't claim you wrote it.

The exceptions are the contents of the third_party directory, which were written by other people and are not covered by this license. This directory as a whole contains GPL software, which means that if you redistribute the entire directory, you must conform to the terms of the GPL.

third_party/lib6502 contains a hacked copy of the lib6502 library, which is © 2005 Ian Plumarta and is available under the terms of the MIT license. See third_party/lib6502/COPYING.lib6502 for the full text.

third_party/tomsfonts contains a copy of the atari-small font, which is © 1999 Thomas A. Fine and is available under the terms of a minimal free license. See third_party/tomsfonts/LICENSE for the full text.

third_party/altirrabasic contains a hacked copy of Altirra Basic, which is © 2014 Avery Lee and is available under the terms of a minimal free license. See third_party/altirrabasic/LICENSE.md for the full text.

third_party/mads contains a copy of Mad Assembler, which is © 2018-2023 Tomasz Biela and is available under the terms of the MIT license. See third_party/mads/LICENSE for the full text.

third_party/pascal-m contains a extremely hacked up copy of the Pascal-M bytecode compiler and interpreter, which is © 1978-2021 Niklaus Wirth, Mark Rustad and Hans Otten and is available under the terms of the MIT license. See third_party/pascal-m/LICENSE for the full text.

third_party/dwarfstar contains DwarfStar, which is © 2024 by Ivo van Poorten and is available under the terms of the BSD 2-Clause License. See third_party/dwarfstar/LICENSE for the full text.

third_party/zmalloc contains a copy of zmalloc, which is © 2024 by Ivo van Poorten and is available under the terms of the 0BSD License. See third_party/zmalloc/LICENSE for the full text.

## List of Software for the Neo6502

(non-conclusive)

Eliza by Erland Nagel (https://github.com/erlendnagel/Neo6502-Eliza) An implementation of the 1960s faux psychiatrist program.

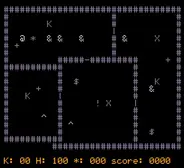
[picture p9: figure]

Dungeon Crawler by Chris Garrett (https://github.com/omiq/neo6502-c/) A classic dungeon crawler with ASCII graphics.

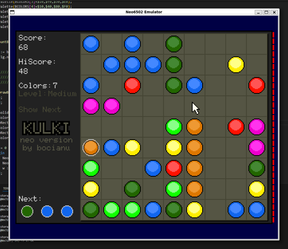
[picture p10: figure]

Kulki by Wojciech Bocianski (https://gitlab.com/bocianu/neo-kulki) Kulki is a puzzle game where you have to place marbles in a row

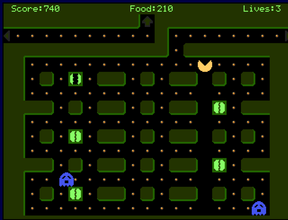
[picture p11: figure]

PacMad by Wojciech Bocianski (https://gitlab.com/bocianu/neo-pacmad) A scrolling Pacman game, in Pascal.

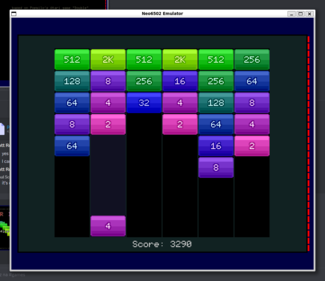
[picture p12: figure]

Power Bricks game by Wojciech Bocianski (https://gitlab.com/bocianu/neo-power-bricks) A 1024 puzzle game.
Robotron 2084 by Paul Robson (https://github.com/paulscottrobson/neo-robotron) A version of the Williams Arcade classic.

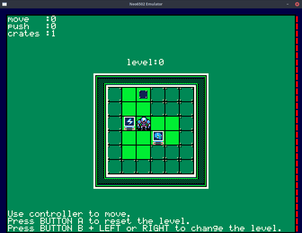
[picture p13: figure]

Sokoban by zbyti (https://github.com/zbyti/pikoban) The classic puzzle game

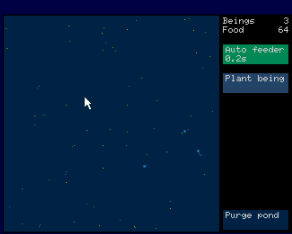
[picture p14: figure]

Swimo by Wojciech Bocianski (https://gitlab.com/bocianu/neo-swimo) A cellular automata type simulator.

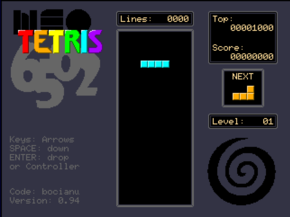
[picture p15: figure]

Tetris by Wojciech Bocianski (https://gitlab.com/bocianu/neo-tetris) Tetris :)
Solitaire Suite by Wojciech Bocianksi (https://gitlab.com/bocianu/neo-solsuite) A suite of Solitaire games

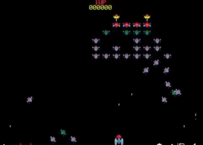
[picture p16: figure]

Neo 6502 BASIC Demo Games repository (Squash, Space Invaders, Galaxians, Frogger, Asteroids) (https://github.com/paulscottrobson/neo6502-games) Some versions of original classics written to test the capabilities of the machine. These are all in BASIC, except for Asteroids which is partially assembler.

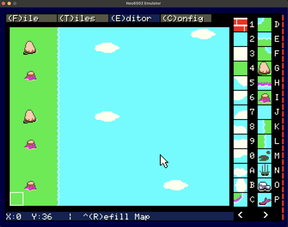
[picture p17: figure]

Mapper by Giovanni Pozzobon (https://github.com/giovannipozzobon/mapper) A tilemap editor which can output files in Neo6502's tile format.

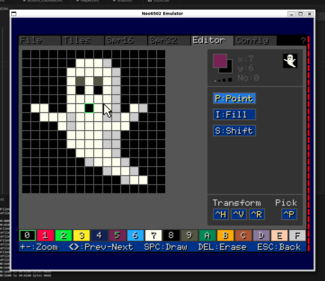
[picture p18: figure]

Spoon - neo6502 sprite editor by Wojciech Bocianski (https://gitlab.com/bocianu/neo-spoon) A sprite editor for use with Neo6502 games.

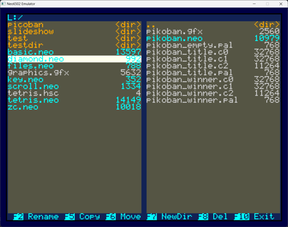
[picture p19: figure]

Zion Commander File Manager by Wojciech Bocianski (https://gitlab.com/bocianu/zion-commander) A file management by mouse click program.
Your software here

# 4) Hardware

## USB Hub issues

The Raspberry Pi PICO has a technical problem when used in conjunction with the tinyUSB library. Not all USB hubs work with it. If you want to use the Apple, Oric, or C64 emulators you may not need a USB hub, but "Morpheus" does for accessing a USB key to save data. Following some investigation, it was discovered that only certain chipsets worked, so Olimex produced a small USB hub using that chipset.

Buying this is well worth considering as it is not expensive (currently 8 Euros). If you have a USB hub, it may be worth trying. The Raspberry Pi hubs built into the keyboard appear to work correctly. But this cannot be guaranteed as the chips used may change.

This has been reported as a fault, investigated, and it seems at present it is not fixable. It is possible this hub may be integrated onto later versions of the board.

NB: It might also be beneficial to use a powered USB hub, as the Pi Pico does not supply that much power.

## HDMI display issues

The output is DVI through a HDMI connector. There is currently a discussion about whether it should be powered or not, currently it is not. It does not seem to work well with adaptors and some displays, notably LG.

Q: I have LG monitor and there is no picture on the HDMI. I did everything correctly. My board is hardware revision B. Is my board broken?

A: Try all steps again. If problem remains and if you have revision A or B board you might try to close FUSE pads to enable 5V on the HDMI connector. If you have B1 or newer revision FUSE should have a diode component already placed.

To perform the fix look under the HDMI connector, there are two pads that should be empty that have word "FUSE" nearby. Connect the pads together soldering a small wire between them or 0R resistor (the best idea is to solder diode 1N5819/S4 but it has direction so be careful, cathode should be towards HDMI connector, diode would prevent HDMI monitor powering the board). Testing with a wire is fine if you don't have such diode, but if it works in future you might want to buy such diode and solder there (just make sure about the direction).

#### NB: This seems to be fixed in Rev. B1, see Appendix.

### Red horizontal lines

Randomly appearing, often at boot or on key stroke. These seem to originate from the interaction between tinyUSB and picoDVI. When using SDCards via UEXT, the problem shouldn't be that bad.

For an in depth discussion, see:

https://github.com/paulscottrobson/neo6502-firmware/issues/115

## Peripheral Hardware

#### Optional Gamepad

Gamepads are easy to acquire. A copy of a Super Nintendo controller with a USB connector can be acquired from several sources. One of the issues with USB Game controllers is that there seems to be no standard (if you look at the Linux source there is a list of driver options for all sorts of keyboards). Currently we only support certain types of keyboards. Again, this is obtainable from Olimex and it will be the 'correct model'. The author has similar looking gamepads not acquired from Olimex, and they seem to work (it depends on the USB ID) but they may not. There is support for some other gamepads included.

It's not a requirement. The "Operating System" of Morpheus uses keyboard keys if no gamepad is present.

#### A-A USB cable or Programmer

To program the Pico, a USB A to USB A cable is required. It is also possible to use a Programmer and the 'openocd' software as developers for the Pico do. The Neo6502 usually comes programmed with an Apple 2 emulator and Morpheus is still updated for bug fixes and occasional enhancements. It is not required for day to day use of the machine.

#### Case

This is completely optional ; it is a small box which the Neo6502 board fits into, all the main sockets and connectors are exposed. For P&P reasons , if you want it, it probably makes sense to order it at the same time as the board. It is available in blue or red lettering.

#### UEXT Devices

Olimex produced UEXT modules which are listed here (https://www.olimex.com/Products/Modules/), for the same reasons if you want one in particular it is worth ordering it at the same time. The majority of these devices are economically priced. The Basic and API have simple commands for interfacing with SPI, I2C and Serial Devices.

#### Keyboard

A standard USB keyboard is used, these seem to work almost 100%.

#### USB Key

If you want to save programs then a USB key is required. For similar reasons to the USB Hub we believe, it requires a fast key. Initially I used "Amazon Cheapies" and none of them worked properly. I replaced this with a Sandisk USB 3.0 key which was about £10 and it works fine.

#### SD Card (as an option)

The system does support the use of SD Cards. This requires the Olimex UEXT SD Card adaptor.

#### Power Cable

Power is supplied through a USB C type cable of the type that are commonly available.

#### Sound Device

Sound is provided on board by a simple buzzer. This is perfectly okay for beeps and squawks, and fairly audible. It is possible to plug a sound device in which has a 3.5mm Jack plug.

## Getting Online

By Wojciech Bocianski

You can now get online, with the help of Olimex's ESP8266 based Wifi-board. This costs (at the time of writing) under 4 Euros.

At present we have a program repository, but now we have a solid Wifi connection we should see growth in this in the future.

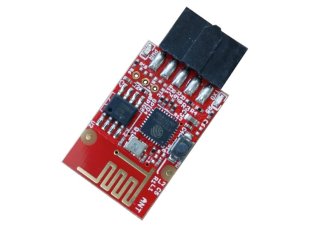
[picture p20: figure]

The board can be acquired from here and other Olimex suppliers (https://www.olimex.com/Products/IoT/ESP8266/MOD-WIFI-ESP8266/open-source-hardware)

(https://gitlab.com/bocianu/neo-networking)

### How to Connect Your Neo6502 to the Internet

https://gitlab.com/bocianu/neo-networking

#### 1. Configure Your Device Settings

Ensure that your device is in Station Mode (1).
In netconfig, navigate to "Advanced Wi-Fi Settings" and set the Wi-Fi mode to 1 - Station.
Alternatively, you can use netconsole and enter the following command:

AT+CWMODE=1

#### 2. Connect to a Local Network

In netconfig, select "Connect to Wi-Fi Network" -> "Show Available Networks" and wait for the scanning process to complete. From the displayed list, choose one of the networks and enter the password if required.

If your network is not visible, you can manually enter the network identifier (SSID) by selecting the appropriate option in the Connect menu.

At this point, you should have internet access. You can verify this by selecting "Show Current Connection Details" from the main menu.

#### 3. Adjust Additional Advanced Settings if Needed

If your network does not provide DHCP, you can manually set your IP address in "Advanced Wi-Fi Settings." You can also configure a custom DNS server here.

#### 4. Update Your Device Firmware

It is recommended to keep your device firmware updated. Once you have internet access, you can update your device using the "Over-the-Air" update feature. In netconfig, select "Get Over-the-Air Firmware Update" and wait about 30 seconds for your device to be automatically updated.

#### 5. I’m Online, What Can I Do Now?

Download the Prophet Client (https://gitlab.com/bocianu/neo-prophet) to gain access to a remote repository containing a wide range of software for your Neo6502.

Check out this website (https://www.makerhacks.com/neo6502-serial-wifi/) to discover what you can do with networking using Neo's built-in BASIC interpreter!

### How to access the Prophet Server

https://gitlab.com/bocianu/neo-prophet

Neo Prophet is a command-line interface (CLI) tool designed for interacting with the Prophet server (https://gitlab.com/bocianu/prophet-server). It allows you to browse, search, and download software available on the server. This tool is specifically tailored for use with the Neo6502 (https://www.neo6502.com/) computer.

#### Running the Program

To start the program, execute the prophet.neo file:

Upon starting, the program will automatically attempt to connect to the server. It will display a headline showing the version number and the current server address. If the connection fails, you will receive an error message and instructions on how to configure the server settings.

Currently, the only working public server is located at mimuma.pl:8998.

#### Commands

Within the Prophet cli command prompt, you can use the following commands:

- cat or c: Displays available software categories.
- list <name|all> or l <name|all>: Lists software in the specified category or all categories.
- search <key> or s <key>: Searches for software based on a keyword.
- info <app_id> or i <app_id>: Displays detailed information about a specified application.
- get <app_id> or g <app_id>: Downloads the specified application.
- config: Shows the current configuration settings.
- set server <address>: Sets the server address.
- set port <port number>: Sets the port number.
- set path <absolute path>: Sets the download path.
- connect: Connects to the server and displays server information.
- help: Displays help information and available commands.
- quit or q: Exits the application.

#### Example Usage

- To display software categories:

cat

- To list software in the "games" category:

list games

- To search for software by keyword:

search tetris

- To see detailed information about a package:

info tetris

- To download an application:

get tetris

- To set a new server address:

set server new.server.address

#### Notes

- Automatic Connection: Upon startup, the program will automatically attempt to connect to the server and display a headline with the version number and current server address. If the connection fails, an error message will be shown. Use the set commands to configure the server address, port number, or download path as needed.
- Debugging and Logs: Check for error messages in the terminal if you encounter any issues.
- Customization: Adjust settings and commands using the set commands within the application to fit your needs.

## Further Hardware Ideas

Check out the Makerhacks-Blog: https://www.makerhacks.com/tag/neo6502/

## Neo6502 Serial Interface

#### Introduction

Neo6502 supports a serial interface as a back door to the machine. It allows the direct injection of code and data into program or graphic memory and the arbitrary insertion of keys into the keyboard buffer.

The original method of doing this in the keyboard input did not work on some machines. This has now been moved out. It can be started either by typing a / RETURN at the command line, or programmatically (see API pdf).

So you could, for example, have a program loaded and run, and when you exit it switch back to 'upload' mode.

#### Connections

The easiest way to connect is via the UEXT port as per the Neo6502 manual, connecting the ground line to pin 2 and TXD and RXD to pins 3 and 4 (though at present the receive is not used). It currently operates at 460kbps which is pretty quick.

If anyone has problems please let me know and we can try a reduced speed version.

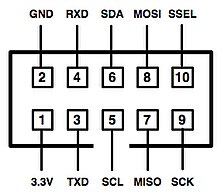
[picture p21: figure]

#### Software

The Python script nxmit.zip allows transmission of tokenised BASIC, arbitrary data and graphic data.

python nxmit.zip <port> <cmd list>

<port> is COM1 or /dev/ttyUSB0 or similar.

Commands supported are :

b:<file> loads <file> as BASIC

g:<file> loads <file> into Graphic Memory

f:<file>@<hex> Loads <file> into CPU Memory at address <hex>

k:<text> Push text into keyboard buffer. Use ! for return

A typical command would be python nxmit.zip /dev/ttyUSB0 B:mycode.bas G:mygraphics.gfx K:RUN!

Additionally it can be used as a library, which allows you to write Python scripts to do things automatically - if you unzip nxmit.zip it is one file called main.py, which can be renamed, or the original is in the repository.

### UEXT connector

UEXT connector stands for Universal EXTension connector and contains +3.3V, GND, I2C, SPI, UART signals.

There are different types of UEXT connectors, but layout is usually the same.

The original UEXT connector is 0.1” 2.54mm step boxed plastic connector. All signals are at 3.3V levels.

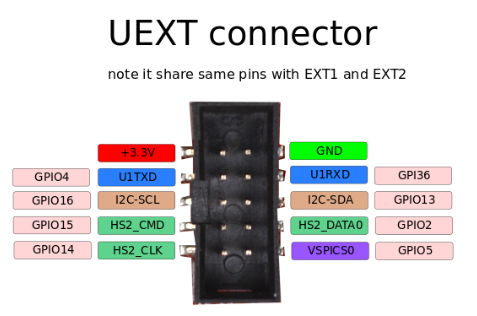
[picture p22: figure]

Olimex has developed number of MODULES (https://www.olimex.com/Products/Modules/) with this connector. There are temperature, humidity, pressure, magnetic field, light sensors. Modules with LCDs, LED matrix, relays, Bluetooth, ZigBee, WiFi, GSM, GPS, RFID, RTC, EKG, sensors and etc.

Neo6502 UEXT connector is wired to RP2040 GPIOs as follows:

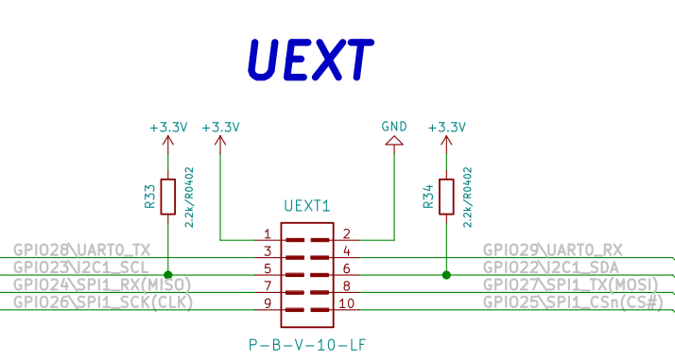
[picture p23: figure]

Slide configuration switch can enable/disable the buzzer, also can connect or disconnect RESB, NMIB and IRQB to RP2040 UEXT signals.

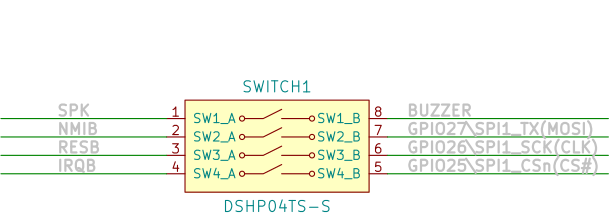
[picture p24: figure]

By default Neo6502 is shipped with all sections connected on the switch i.e. buzzer is enabled and all signals are wired to RP2040. This means you can’t use SPI on UEXT connector if you do not disconnect these signals.

## 6502 bus connector

All 6502 signals are available on BUS1 connector for attaching external hardware on it.

+5V, 3.3V, GND

D0-D7, A0-A15, PHI2, R/W, RESB, SOB, MLB, VPB, SYNC, NMIB, IRQB

Two SWD signals (SWDIO, SWCLK) for RP2040 debugging are also present, these should be left free (if not used for debugging), on the external 6502 peripheral boards.

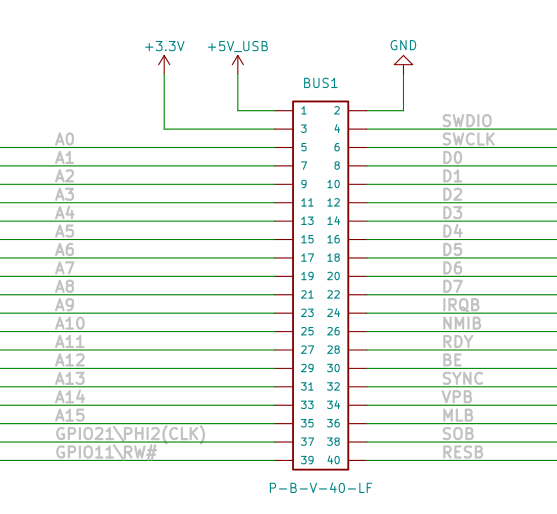
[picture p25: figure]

# 5) Appendix

## A) Neo6502 Messaging API

The Neo6502 API is a messaging system. There are no methods to access the hardware directly. Messages are passed via the block of memory from $FF00 to $FF0F, as specified in the "API Messaging Addresses" table on the following page.

The kernel include file documents/release/neo6502.inc specifies the beginning of this address range as the identifier ControlPort, along with the addresses of WaitMessage and SendMessage (described later), various related kernel jump vectors, and some helper functions.

The application include files examples/assembly/neo6502.asm.inc and examples/C/neo6502.h also specify the beginning of this address range as the identifier ControlPort. The assembly include also specifies ControlPort and the other controls as API_COMMAND, API_FUNCTION, API_ERROR, API_STATUS, and API_PARAMETERS. The C header also specifies ControlPort and the other controls as API_COMMAND_ADDR, API_FUNCTION_ADDR, API_ERROR_ADDR, API_STATUS_ADDR, and API_PARAMETERS_ADDR.

API Commands/Functions are grouped by functionality. For example, Group 1 are system-related, and Group 2 are console-I/O-related.

Command/Function Parameters are notated in this document as Params[0] through Params[7], or as a list or range (eg: Params[1,2], Params[0..7]). Note that these are referring to a mapping to memory locations. The numbers represent offsets from the Parameters base address $FF04. Ie: the actual bytes are not necessarily all distinct "parameters" in the conventional sense. Depending on the routine, a logical parameter may be an individual byte, one or more bits of a byte interpreted as a composite or bit-field, or multiple adjacent bytes interpreted as 16 or 32 bit values. For example, the list Params[0,1] would indicate a single logical parameter, comprised of the two adjacent bytes $FF04 and $FF05. The range Params[4..7] would indicate a single logical parameter, spanning consecutive bytes between $FF08 and $FF0B.

Note that strings referenced by Parameters are not ASCIIZ, but are length-prefixed.

The first byte represents the length of the string (not counting itself). The string begins at the second byte. Consequently, strings must be 255 bytes or less (not counting the length header).

### API Messaging Addresses

Address | Type | Notes
FF00 | Group | Group selector and status. Writing a non-zero value to this location triggers the routine specified in $FF01. The system will respond by setting the 'Error', 'Information', and 'Parameters' values appropriately. Upon completion, this memory location will be will cleared.
FF01 | Function | A command or function within the selected Group. For example, Group 1 Function 0 writes a value to the console; and Group 1 Function 1 reads the keyboard.
FF02 | Error | Return any error values, 0 = no error.
FF03:7 | Status | Set (1) if the ESCape key has been pressed. This is not automatically reset.
FF03:6 | unused
FF03:5 | unused
FF03:4 | unused
FF03:3 | unused
FF03:2 | unused
FF03:1 | unused
FF03:0 | unused
FF04.. | Parameters | This memory block is notated in this document as Params[0] through Params[7], or as a composite list or range (eg: Params[1,2], Params[0..7]). Some Functions require Parameters in these locations and some return values in these locations; yet others do neither.

### API Interfacing Protocol

Neo6502 application programmers should interact with the API per the following algorithm:

1. Wait for any pending command to complete. There is a subroutine WaitMessage which does this for the developer.
2. Setup the Function code at $FF01; and any Parameters across $FF04..$FF0B. To print a character for example, set $FF01 to $06 and set $FF04 to the character's ASCII value. To draw a line, set $FF01 to $02 and set $FF04..$FF0B as four 16-bit pixel coordinates:
3. Setup the command code at $FF00. This triggers the routine; so mind that the Function code and Parameters are setup sanely prior. On a technical point, both implementations process the message immediately on write.
4. Optionally, wait for completion. Most commands (eg: writing to the console) do not require waiting, as any subsequent command will wait/queue as per step 1. Query commands (e.g. reading from the keyboard queue), return a value in a parameter. Programs must wait until the control address $FF00 has been cleared before reading the result of a query.

There is a support function SendMessage, which in-lines the command and function. E.g.: this code from the Kernel:

jsr KSendMessage ; send message for command 2,1 (read keyboard)

.byte 2,1

jsr KWaitMessage ; wait to receive the result message

lda DParameters ; read result

The instructions above are equivalent to the following explicit steps:

lda #1

sta DFunction

lda #2

sta DCommand ; trigger API function 2,1 (read keyboard)

Loop:

lda DCommand ; load the result - non-zero until the routine's completion

bne Loop ; wait for API routine to complete

lda DParameters ; read result (a key-code)

### Mathematical Interface

The mathematical interface of the API functions largely as a helper system for the BASIC interpreted, but it is open to any developer who wishes to avail themselves of the functionality. It is strongly advised that function 32 of Group 4 (NumberToDecimal) is not used as this is extremely specific and as such is not documented.

The interface is used in a stack environment, but is designed so it could be used in either a stack environment or a fixed location environment. The Neo6502 BASIC stack is also 'split', so elements are not consecutive, though they can be.

Parameter 0 and 1 specify the address of the registers 1 and 2. Register 1 starts at this address, Register 2 starts at the next address. Parameter 2 specifies the step to the next register. Therefore they are interleaved by default at present.

So if Parameters 0 and 1 are 8100 and Parameter 2 is 4, the 5 byte registers are

- Register 1: 8100,8104,8108,810C,8110
- Register 2: 8101,8105,8109,810D,8111

Bytes 1-4 of the 'register' are the number, which can be either an integer (32 bit signed) or a standard 'C' float (e.g. the IEEE Single Precision Float format). Bit 0 is the type byte, and the relevant bit is bit 6, which is set to indicate bytes 1-4 are a float value, and is set on return.

Binary functions that use int and float combined (one is int and one is float) normally return a float.

### Console Codes

The following are console key codes. They can be printed in BASIC programs using chr$(n), and are also related to the character keys returned by inkey$(). The key() function uses physical key numbers. Some control codes do not have corresponding keyboard keys; and some console outputs are not yet implemented.

Backspace (8), Tab (9), Enter/CR (13), Escape (27), and the printable characters (32..127) are the standard ASCII set. Other typical control keys (eg: Home and arrows) are mapped into the 0..31 range.

#### Console Key Codes - Non-Printable

Code | Ctrl | Key | Function
1 | A | Left Arrow | Cursor Left
4 | D | Right Arrow | Cursor Right
5 | E | Insert | Insertion Mode
6 | F | Page Down | Cursor Page Down
7 | G | End | Cursor Line End
8 | H | Backspace | Delete Character Left
9 | I | Tab | Tab Character
10 | J | | Line Feed
12 | L | | Clear Screen
13 | M | Enter | Carriage Return (Accept Line)
18 | R | Page Up | Cursor Page Up
19 | S | Down | Cursor Down
20 | T | Home | Cursor Line Begin
22 | V | | Cursor Down (8 Lines)
23 | W | Up | Cursor Up
24 | X | | Cursor Color Inverse
26 | Z | Delete | Delete Character Right
27 | [ | Escape | Exit

#### Console Key Codes - Printable

Code | Type | Notes
20-7F | ASCII Set | Standard ASCII Characters
80-8F | | Set Foreground Color
90-9F | | Set Background Color
C0-FF | | User-definable Characters

### Graphics

#### Graphics Settings

Function 5,1 configures the global graphics system settings. Not all Parameters are relevant for all graphics commands; but all Parameters will be set by this command. So mind their values.

The actual color of each drawn pixel will be computed at runtime by AND'ing the existing pixel color with the value specified in Params[0], then XOR'ing the result with the value specified in Params[1].

The value in Params[2] is a flag which determines the paint fill mode for the Draw Rectangle and Draw Ellipse commands: reset (0) for outline, set (1) for solid fill.

The value in Params[3] is the draw extent (window) for the Draw Image command.

The value in Params[4] is a bit-field of flags for the Draw Image command, which determine if the image will be inverted (flipped) horizontally or vertically: bit-0 for horizontal, bit-1 for vertical, reset (0) for normal, set (1) for inverted.

For the "Draw Rectangle" and "Draw Ellipse" commands, the given order and position of the coordinates are not significant. To be precise, one is "a corner" and the other is "the opposite corner". For the "Draw Ellipse" command, these corners are referring to the bounding-box. The coordinates for an ellipse will lie outside of the ellipse itself.

#### Graphics Data

Graphics data files are conventionally named ending in the .gfx suffix; though this is not mandatory. The format is quite simple.

#### Graphics Data Format

Offset | Data | Notes
0 | 1 | Graphics Data Format ID
1 | Count | Number of 16x16 tiles in use
2 | Count | Number of 16x16 sprites in use
3 | Count | Number of 32x32 sprites in use
4..255 | | Reserved
256 | Raw | Sprites graphics data

The layout of sprites graphics data is all of the 16x16 tiles, followed by all the 16x16 sprites, followed by all the 32x32 sprites, all in their respective orders. As there is currently only about 20kB of Graphics Memory, these should be used somewhat sparingly.

Each byte specifies 2 pixels. The upper 4 bits represent the first pixel colour; and the lower 4 bits represent the second pixel colour. So tiles and 16x16 sprites occupy 16x16/2 bytes (128 bytes) each. Each 32x32 sprite occupies 32x32/2 bytes (512 bytes). Colour 0 is transparent for sprites (colour 9 should be used for a black pixel).

The release package includes Python scripts for creating graphics files, which allow you to design graphics using your preferred editing tools (eg: Gimp, Inkscape, Krita, etc). There is an example in the crossdev directory, which demonstrates how to get started importing graphics into the Neo6502.

### Sprites

The Neo6502 graphics system has one sprite layer (z-plane) in the conventional sense. Technically, there is no "sprite layer", per-se. The system uses palette manipulation to create, what is in practice, a pair of 4-bit bit-planes. The sprite graphics are in the upper nibble, the background is in the lower nibble, and the background is drawn only if the sprite graphic layer is zero. It's this top nibble which is read by Function 5,36 "Read Sprite Pixel".

Function 6,2 sets or updates a sprite. These parameters (eg: the X and Y coordinates) cannot be set independently. To retain/reuse the current value of a parameter for a subsequent call, set each of the associated byte(s) to $80 (eg: $80,$80,$80,$80 for coordinates).

The 'Sprite' Parameter Params[0] specifies the index of the sprite in the graphics system. Sprite 0 is the turtle sprite.

Params[1,2],Params[3,4] specifies the X and Y screen coordinates.

Bits 0-5 of the 'Image' Parameter Params[5] specify the index of a specific graphic within the sprites data. Bit 6 of the 'Image' Parameter specifies the sprite dimensions: reset (0) for 16x16, set (1) for 32x32. In practice, the index is the same as the sprite number ($80-$BF for 16x16 sprites, $C0-$FF for 32x32 sprites), but without bit-7 set.

The value in Params[6] specifies a bit-field of flags, which determines if the graphic will be inverted (flipped) horizontally or vertically: bit-0 for horizontal, bit-1 for vertical, reset (0) for normal, set (1) for inverted.

Params[7] specifies the anchor alignment.

#### Sprite Anchors

The table below shows the valid anchor alignments for a sprite. The anchor position is the origin of the relative coordinate given. That is, coordinates 0,0 of the sprite will coincide with one of the positions shown in the table below. The default anchor alignment is zero (middle-center).

7 | 8 | 9
4 | 0/5 | 6
1 | 2 | 3

To the right are two examples. Assume this is a 32x32 sprite. In the upper example, the anchor point is at 8, the top-center. Considering the origin at the bottom-left, this sprite is drawn at 16,32, the midpoint of the top of the square.

In the lower example, the anchor point is at 0; and this sprite is drawn at 16,16 (the middle of the square). The anchor point should be something like the centre point. So for a walking character, this might be anchor point 2 (the bottom-center).

### Sound

Function 8,4 queues a sound. Queued sounds are played sequentially, each after the previous has completed, such that sounds within a channel queue will not conflict, interrupt, or overlap.

Frequency is in units of Hertz. Duration is in units of 100ths of a second. Slide is a gradual linear change in frequency, in units of Hz per 100th of a second. Sound target type 0 is the beeper. Currently, the beeper is the only available sound target.

Queue Sound Parameters

FF04 | FF05 | FF06 | FF07 | FF08 | FF09 | FF0A | FF0B
Channel | Freq Low | Freq High | Length Low | Length High | Slide Low | Slide High | Target

Function 8,7 is an extended version of this ; function 8.4 still works, but 8,7 allows access to the extended multi channel sound functionality. Sound types are, at the time of writing, 0 (square wave) and 1 (random noise). There are four channels minimum, but the function 8,8 allows you to read the number of supported channels.

FF04 | FF05 | FF06 | FF07 | FF08 | FF09 | FF0A | FF0B | FF0C
Channel | Freq Low | Freq High | Length Low | Length High | Slide Low | Slide High | Sound Type | Sound Volume

#### Sound Effects

Function 8,5 plays a sound effect immediately. These will be synthesised to the best ability of the available hardware, so the actual sound may vary slightly.

ID | Sound
0 | positive
1 | negative
2 | error
3 | confirm
4 | reject
5 | sweep
6 | coin
7 | las70
8 | powerup
9 | victory
10 | defeat
11 | fanfare
12 | alarm 1
13 | alarm 2
14 | alarm 3
15 | ringtone 1
16 | ringtone 2
17 | ringtone 3
18 | danger
19 | expl100
20 | expl50
21 | expl20
22 | las30
23 | las10

### Filing system

The Neo6502 supports the FAT32 file system on a USB mass storage device or SD card. Only the first partition is supported, and filenames must be in the standard DOS 8.3 format.

There is a fairly standard set of functions for loading and saving files, manipulating files and directories, and performing random-access file operations.

#### File attributes

Files may have any combination of the following bits set.

Name | Value | Meaning
FIOATTR_DIR | 0x01 | This is a directory (may not be modified)
FIOATTR_SYSTEM | 0x02 | This is a system file and will be hidden from directory listings
FIOATTR_ARCHIVE | 0x04 | File is archived; automatically cleared when the file is modified
FIOATTR_READONLY | 0x08 | File is read only and may not be overwritten or modified
FIOATTR_HIDDEN | 0x10 | This will be hidden from directory listings

#### Error codes

Most of the functions in group 3 will return an error/status code to indicate whether the operation succeeded or not. This will be a value from the following enumeration.

Values here are grouped by their top four bits; applications will typically only need to check the group value unless they are interested in the specific error.

Group 0; miscellaneous

Name | Value | Meaning
FIOERROR_OK | 0x00 | Operation succeeded (not an error)
FIOERROR_UNKNOWN | 0x01 | Something went wrong, but we don't know what
FIOERROR_EOF | 0x02 | A read or directory enumeration operation reached the end of the file
FIOERROR_UNIMPLEMENTED | 0x03 | Operation is not implemented

Group 1: path errors

Name | Value | Meaning
FIOERROR_NO_FILE | 0x11 | Could not find the file
FIOERROR_NO_PATH | 0x12 | Could not find the path
FIOERROR_INVALID_DRIVE | 0x13 | The logical drive number is invalid
FIOERROR_INVALID_NAME | 0x14 | The path name format is invalid
FIOERROR_INVALID_PARAMETER | 0x15 | Given parameter is invalid

Group 2: access errors

Name | Value | Meaning
FIOERROR_DENIED | 0x21 | Access denied due to prohibited access or disk or directory full
FIOERROR_EXIST | 0x22 | Access denied due to prohibited access
FIOERROR_INVALID_OBJECT | 0x23 | The file/directory object is invalid
FIOERROR_WRITE_PROTECTED | 0x24 | The physical drive is write protected
FIOERROR_LOCKED | 0x25 | File is in use

Group 3: media errors

Name | Value | Meaning
FIOERROR_DISK_ERR | 0x31 | A hard error occurred in the low level disk I/O layer
FIOERROR_INT_ERR | 0x32 | Assertion failed
FIOERROR_NOT_READY | 0x33 | The physical drive cannot work
FIOERROR_NOT_ENABLED | 0x34 | The volume has no work area
FIOERROR_NO_FILESYSTEM | 0x35 | The filesystem is invalid

Group 4: internal errors

These indicate an internal error with the Morpheus firmware and should never happen.

Name | Value | Meaning
FIOERROR_MKFS_ABORTED | 0x41 | The f_mkfs() aborted due to any problem
FIOERROR_TIMEOUT | 0x42 | Could not get a grant to access the volume within defined period
FIOERROR_NOT_ENOUGH_CORE | 0x43 | LFN working buffer could not be allocated
FIOERROR_TOO_MANY_OPEN_FILES | 0x44 | fatfs has seen too many open files

## B) API Functions

The following tables are a comprehensive list of all supported API functions.

For the convenience of application programmers, the application include files examples/C/neo6502.h and examples/assembly/neo6502.asm.inc define macros for these groups, their functions, and common parameters (colors, musical notes, etc).

### Group 1 : System

Function 0 : DSP Reset

Resets the messaging system and component systems. Normally, should not be used.

Function 1 : Timer

Deposit the value (32-bits) of the 100Hz system timer into Parameters:0..3.

Function 2 : Key Status

Deposits the state of the specified keyboard key into Parameter:0.

State of keyboard modifiers (Shift/Ctrl/Alt/Meta) is returned in Parameter:1.

The key which to query is specified in Parameter:0.

Function 3 : Basic

Loads and allows the execution of BASIC via a indirect jump through address zero.

Function 4 : Credits

Print the Neo6502 project contributors (stored in flash memory).

Function 5 : Serial Status

Check the serial port to see if there is a data transmission.

Function 6 : Locale

Set the locale code specified in Parameters:0,1 as upper-case ASCII letters.

Parameter:0 takes the first letter and Parameter:1 takes the second letter.

For example: French (FR) would require Parametr 0 being $46 and Parameter 1 being $52

Function 7 : System Reset

System Reset. This is a full hardware reset. It resets the RP2040 using the Watchdog timer, and this also resets the 65C02.

Function 8 : MOS

Do a MOS command (a '* command') these are specified in the Wiki as they will be steadily expanded.

Function 10 : Write character to debug

Writes a single character to the debug port (the UART on the Pico, or stderr on the emulator). This allows maximum flexibility.

Function 11 : Return Version Information

Reads the current version Major.Minor.Patch into Parameters:0..2 These values are guaranteed to be in the range 0.255

### Group 2 : Console

Function 0 : Write Character

Console out (duplicate of Function 6 for backward compatibility).

Function 1 : Read Character

Read and remove a key press from the keyboard queue into Parameter:0. This is the ASCII value of the keystroke.

If there are no key presses in the queue, Parameter:0 will be zero.

Note that this Function is best for text input, but not for games. Function 7,1 is more optimal for games, as this only detects key presses, you cannot check whether the key is currently down or not.

Function 2 : Console Status

Check to see if the keyboard queue is empty. If it is, Parameter:0 will be $FF, otherwise it will be $00

Function 3 : Read Line

Input the current line below the cursor into Parameters:0,1 as a length-prefixed string; and move the cursor to the line below. Handles multiple-line input.

Function 4 : Define Hotkey

Define the function key F1..F10 specified in Parameter:0 as 1..10 to emit the length-prefixed string stored at the memory location specified in Parameters:2,3.

F11 and F12 cannot currently be defined.

Function 5 : Define Character

Define a font character specified in Parameter:0 within the range of 192..255.

Fill bits 0..5 (columns) of Parameters:1..7 (rows) with the character bitmap.

Function 6 : Write Character

Write the character specified in Parameter:0 to the console at the cursor position.

Refer to Section "Console Codes" for details.

Function 7 : Set Cursor Pos

Move the cursor to the screen character cell Parameter:0 (X), Parameter:1 (Y).

Function 8 : List Hotkeys

Display the current function key definitions.

Function 9 : Screen Size

Returns the console size in characters, in Parameter:0 (height) and Parameter:1 (width).

Function 10 : Insert Line

This is a support function which inserts a blank line in the console and should not be used.

Function 11 : Delete Line

This is a support function which deletes a line in the console and should not be used.

Function 12 : Clear Screen

Clears the screen.

Function 13 : Cursor Position

Returns the current screen character cell of the cursor in Parameter:0 (X), Parameter:1 (Y).

Function 14 : Clear Region

Erase all characters within the rectangular region specified in Parameters:0,1 (begin X,Y) and Parameters:2,3 (end X,Y).

Function 15 : Set Text Color

Sets the foreground colour to Parameter:0 and the background colour to Parameter:1.

Function 16 : Cursor Inverse

Toggles the cursor colour between normal and inverse (ie: swaps FG and BG colors). This should not be used.

Function 17 : Tab() implementation

Internal helper.

Function 18 : Read Ink/Paper Colours

Read the ink/paper colours into Param[0] and Param[1]

Function 19 : Show/Hide Cursor Reversing

Set the cursor visibility to Param[0]. This is reset by clearing the screen.

### Group 3 : File I/O

Function 1 : List Directory

Display the file listing of the present directory.

Function 2 : Load File

Load a file by name into memory. On input:

Parameters:0,1 points to the length-prefixed filename string;

Parameters:2,3 contains the location to write the data to. If the address is $FFFF, the file will instead be loaded into the graphics working memory, used for sprites, tiles, images.

On output:

Error location contains an error/status code.

Function 3 : Store File

Saves data in memory to a file. On input:

Parameters:0,1 points to the length-prefixed filename string;

Parameters:2,3 contains the location to read data from;

Parameters:4,5 specified the number of bytes to store.

On output:

Error location contains an error/status code.

Function 4 : File Open

Opens a file into a specific channel. On input:

Parameter:0 contains the file channel to open;

Parameters:1,2 points to the length-prefixed filename string;

Parameter:3 contains the open mode. See below.

Valid open modes are:

0 opens the file for read-only access;

1 opens the file for write-only access;

2 opens the file for read-write access;

3 creates the file if it doesn't already exist, truncates it if it does, and opens the file for read-write access.

Modes 0 to 2 will fail if the file does not already exist. If the channel is already open, the call fails. Opening the same file more than once on different channels has undefined behaviour, and is not recommended.

Function 5 : File Close

Closes a particular channel. On input:

Parameter:0 contains the file channel to close. If this is $FF this closes all open files.

Function 6 : File Seek

Seeks the file opened on a particular channel to a location. On input:

Parameter:0 contains the file channel to operate on;

Parameters:1..4 contains the file location.

You can seek beyond the end of a file to extend the file. However, whether the file size changes when the seek happens, or when you perform the write is undefined behavior.

Function 7 : File Tell

Returns the current seek location for the file opened on a particular channel. On input:

Parameter:0 contains the file channel to operate on.

On output:

Parameters:1..4 contains the seek location within the file.

Function 8 : File Read

Reads data from an opened file. On input:

Parameter:0 contains the file channel to operate on.

Parameters:1,2 points to the destination in memory,

or $FFFF to read into graphics memory.

Parameters:3,4 contains the amount of data to read.

On output:

Parameters:3,4 is updated to contain the amount of data actually read.

Data is read from the current seek position, which is advanced after the read.

Function 9 : File Write

Writes data to an opened file. On input:

Parameter:0 contains the file channel to operate on;

Parameters:1,2 points to the data in memory;

Parameters:3,4 contains the amount of data to write.

On output:

Parameters:3,4 is updated to contain the amount of data actually written.

Data is written to the current seek position, which is advanced after the write.

Function 10 : File Size

Returns the current size of an opened file. On input:

Parameter:0 contains the file channel to operate on.

On output:

Parameters:1..4 contains the size of the file.

This call should be used on open files, and takes into account any buffered data which has not yet been written to disk. Consequently, this may return a different size than Function 3,16 "File Stat".

Function 11 : File Set Size

Extends or truncates an opened file to a particular size. On input:

Parameter:0 contains the file channel to operate on;

Parameters:1..4 contains the new size of the file.

Function 12 : File Rename

Renames a file. On input:

Parameters:0,1 points to the length-prefixed string for the old name;

Parameters:2,3 points to the length-prefixed string for the new name.

Files may be renamed across directories.

Function 13 : File Delete

Deletes a file or directory. On input:

Parameters:0,1 points to the length-prefixed filename string.

Deleting a file which is open has undefined behaviour. Directories may

only be deleted if they are empty.

Function 14 : Create Directory

Creates a new directory. On input:

Parameters:0,1 points to the length-prefixed filename string.

Function 15 : Change Directory

Changes the current working directory. On input:

Parameters:0,1 points to the length-prefixed path string.

Function 16 : File Stat

Retrieves information about a file by name. On input:

Parameters:0,1 points to the length-prefixed filename string.

Parameters:0..3 contains the length of the file;

Parameter:4 contains the attributes bit-field of the file.

If the file is open for writing, this may not return the correct size due to buffered data not having been flushed to disk.

File attributes are a bitfield as follows: 0,0,0,Hidden, Read Only, Archive, System, Directory.

Function 17 : Open Directory

Opens a directory for enumeration. On input:

Parameters:0,1 points to the length-prefixed filename string.

Only one directory at a time may be opened. If a directory is already open when this call is made, it is automatically closed. However, an open directory may make it impossible to delete the directory; so closing the directory after use is good practice.

Function 18 : Read Directory

Reads an item from the currently open directory. On input:

Parameters:0,1 points to a length-prefixed buffer for returning the filename.

Parameters:0,1 is unchanged, but the buffer is updated to contain the

length-prefixed filename (without any leading path);

Parameters:2..5 contains the length of the file;

Parameter:6 contains the file attributes, as described by Function 3,16 "File Stat".

If there are no more items to read, this call fails and an error is flagged.

Function 19 : Close Directory

Closes any directory opened previously by Function 3,17 "Open Directory".

Function 20 : Copy File

Copies a file. On input:

Parameters:0,1 points to the length-prefixed old filename;

Parameters:2,3 points to the length-prefixed new filename.

Only single files may be copied, not directories.

Function 21 : Set file attributes

Sets the attributes for a file. On input:

Parameters:0,1 points to the length-prefixed filename;

Parameter:2 is the attribute bitfield. (See Stat File for details.)

The directory bit cannot be changed. Obviously.

Function 22 : Check End of File.

Returns the end of file status of an opened file. On input:

Parameter:0 contains the file channel to operate on.

On output:

Parameter:0 is non-zero if the file is at the end of the file.

This call should be used on open files and may return an error if the file is closed.

Function 23 : Get Current Working Directory.

Copies the current working directory into the String at address Parameters:0,1. which is of maximum length Parameters:2

Function 32 : List Filtered

Prints a filtered file listing of the current directory to the console. On input:

Parameters:0,1 points to the filename search string.

Files will only be shown if the name contains the search string (ie: a substring match).
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

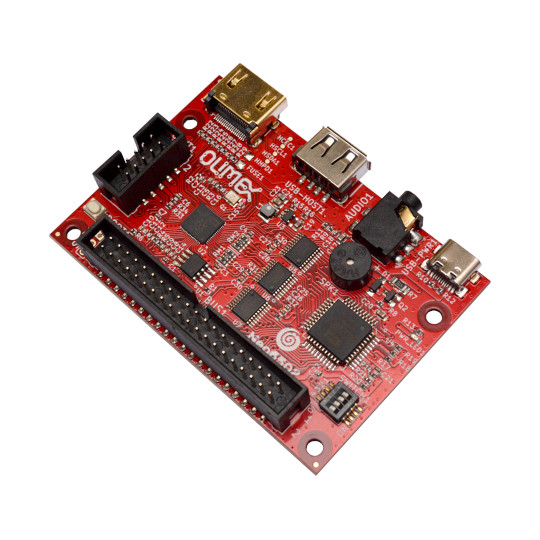
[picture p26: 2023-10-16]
DOCUMENTS/Neo6502-a.jpg

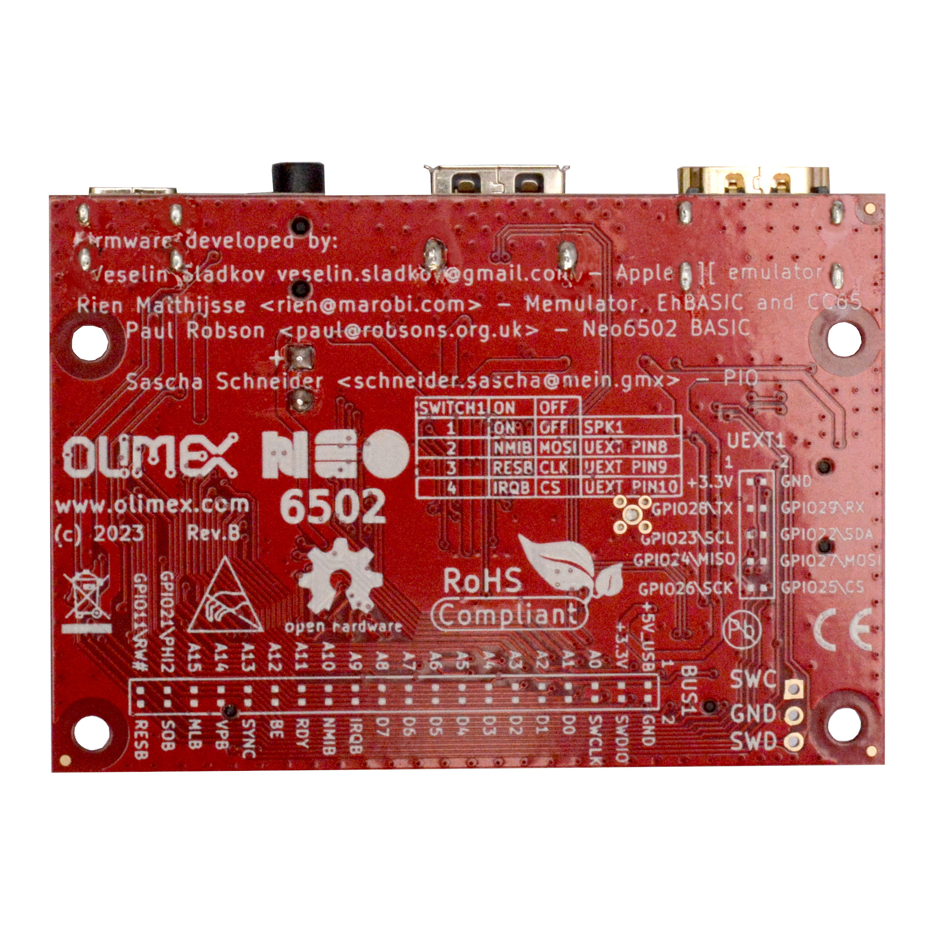
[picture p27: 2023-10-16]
DOCUMENTS/Neo6502-c.jpg

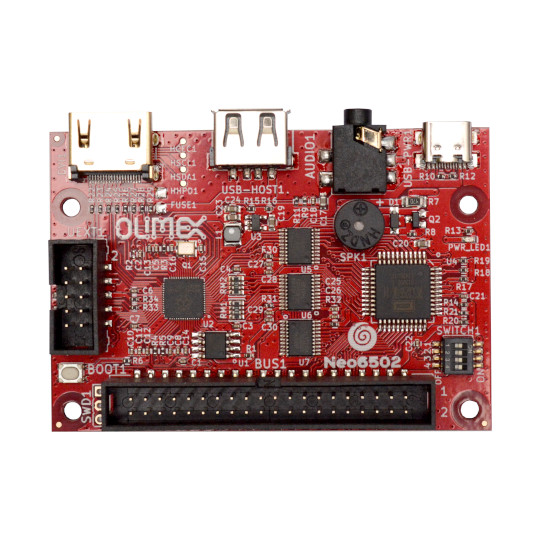
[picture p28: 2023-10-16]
DOCUMENTS/Neo6502-b.jpg

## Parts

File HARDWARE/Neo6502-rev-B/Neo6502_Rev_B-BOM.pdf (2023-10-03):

Neo6502_Rev_B_BOM | 08/30/2023
Qty | Designation | Package | Designator
2 | 100R/R0402 | R_0402_5MIL_DWS | R3,R6
2 | 27R/R0402 | R_0402_5MIL_DWS | R4,R5
1 | 47R/R1206 | R_1206_5MIL_DWS | R7
1 | 150R/R0402 | R_0402_5MIL_DWS | R9
9 | 270R/R0402 | R_0402_5MIL_DWS | R11,R22,R23,R24,R25,R26, R27,R28,R29
4 | 2.2k/R0402 | R_0402_5MIL_DWS | R8,R13,R33,R34
2 | 5.1k/1%/R0402 | R_0402_5MIL_DWS | R10,R12
10 | 10k/R0402 | R_0402_5MIL_DWS | R1,R14,R17,R18,R19,R20, R21,R30,R31,R32
1 | 49.9k/1%/R0402 | R_0402_5MIL_DWS | R16
1 | 220k/R0402 | R_0402_5MIL_DWS | R15
2 | RA1206_(4x0603)_4B8_330R | RA1206_(4X0603)_4B8_xx | RM1,RM2
2 | 27pF/50V/5%/C0G/C0402 | C_0402_5MIL_DWS | C15,C16
18 | 100nF/10V/20%/X5R/C0402 | C_0402_5MIL_DWS | C1,C2,C3,C4,C5,C6,C7,C8, C9,C10,C13,C14,C18,C21, C22,C26,C27,C29
5 | 2.2uF/6.3V/20%/X5R/C0402 | C_0402_5MIL_DWS | C11,C12,C25,C28,C30
5 | 22uF/6.3V/20%/X5R/C0603 | C_0603_5MIL_DWS | C17,C19,C20,C23,C24
1 | 1N4148W/SOD123 | SOD-123_1C-2A_KA | D1
1 | LED/RED/0603 | LED_0603_KA | PWR_LED1
1 | 2.2uH/NRS3015T2R2MNGH | CD32 | L1
1 | BC817-40(SOT23) | SOT23 | Q2
1 | Q12MHz/20pF/10ppm/4P/3.2x2.5mm | TSX-3.2x2.5mm_GND(3) | Q1
1 | ZD25Q16BTIGT(SOIC-8_208mils) | SO-8_208mil | U1
1 | RP2040(QFN-56_7x7mm_P0.4mm) | QFN56_7x7_Pitch_0.4mm | U2
1 | SY8089AAAC(SOT23-5) | SOT-23-5 | U3
3 | 74LVC245APW(TSSOP20) | TSSOP20_Pitch-0.65mm_6.6x4.5x1.2mm | U5,U6,U7
1 | W65C02S6TQTG-14(TQFP44) | TQFP44_NEO6502 | U4
1 | USB-A-SMT-6.3H | USB-A-SMT-6.3H_HOST_Female | USB-HOST1
1 | HDMI-SWM-19 | HDMI-SWM-19_Paste | DVI1
1 | P-B-V-40-LF | GBH-254-SMT-40 | BUS1
1 | P-B-V-10-LF | GBH-254-SMT-10 | UEXT1
1 | PJ-3.5-365-5P | SCJ325P00XG0B02G | AUDIO1
1 | USB-C-16P-F(A40-00119-A52-12) | USB2.0_TYPE-C(A40-00119-A52-12)_Paste | USB-PWR1
1 | Speaker_QMB-09B-03(1.5-5.0V_ 2.7kHz_F9.0mm*H5.5mm) | Speaker_QMB-09B-03_1-Plus_2-Minus | SPK1
1 | YTS-A016-X | YTS-A016-X | BOOT1
1 | DSHP04TS-S | DSHP04TS-S-1.27mm_Half_4_Slide | SWITCH1
1 | NA(FSMD035-1206) | FUSE-1206 | FUSE1
1 | NA(10k/R0402) | R_0402_5MIL_DWS | R2
1 | NA(HN1x3) | HN1x3 | SWD1

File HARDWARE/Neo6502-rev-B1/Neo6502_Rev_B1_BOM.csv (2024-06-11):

Id | Designator | Package | Quantity | Designation | Supplier and ref
1 | USB-PWR1 | USB2.0_TYPE-C(A40-00119-A52-12)_Paste | 1 | USB-C-16P-F(A40-00119-A52-12)
2 | NEO6502_NEW | Neo6502_Sign_Small_NEW2 | 1 | LOGO
3 | NEO_LOGO_SMALL* | Neo6502_Sign_Small | 1 | LOGO
4 | USB-HOST1 | USB-A-SMT-6.3H_HOST_Female | 1 | USB-A-SMT-6.3H
5 | DVI1 | HDMI-SWM-19_Paste | 1 | HDMI-SWM-19
6 | BUS1 | GBH-254-SMT-40 | 1 | P-B-V-40-LF
7 | UEXT1 | GBH-254-SMT-10 | 1 | P-B-V-10-LF
8 | Sign_RoHS | Sign_RoHS_1 | 1 | Sign_RoHS
9 | Sign_RecycleBin | Sign_RecycleBin_1 | 1 | Sign_RecycleBin
10 | Sign_PB-Free | Sign_PB-Free | 1 | Sign_PB-Free
11 | Sign_OSHW_8x8 | Sign_OSHW_8x8 | 1 | Sign_OSHW_8x8
12 | Sign_Antistatic | Sign_Antistatic | 1 | Sign_Antistatic
13 | Logo_OLIMEX_TB-Bottom,Logo_OLIMEX_TB-Top | Logo_OLIMEX_TB | 2 | Logo_OLIMEX_TB
14 | Sign_CE | CE_Sign | 1 | CE_Sign
15 | AUDIO1 | SCJ325P00XG0B02G | 1 | PJ-3.5-365-5P
16 | C22,C18,C1,C2,C3,C4,C5,C6,C7,C8,C9,C10,C13,C14,C21,C26,C27,C29 | C_0402_5MIL_DWS | 18 | 100nF/10V/20%/X5R/C0402
17 | FID2,FID3,FID5,FID6,FID4 | Fiducial1x3 | 5 | Fiducial
18 | MH1,MH2,MH3,MH4 | Mounting_Hole_Drill-3.3mm_Clerance-7mm | 4 | Mounting_Hole_NPTH
19 | PWR_LED1 | LED_0603_KA | 1 | LED/RED/0603
20 | R13,R33,R34,R8 | R_0402_5MIL_DWS | 4 | 2.2k/R0402
21 | R30,R1,R14,R17,R18,R19,R20,R21,R31,R32 | R_0402_5MIL_DWS | 10 | 10k/R0402
22 | R9 | R_0402_5MIL_DWS | 1 | 150R/R0402
23 | R11,R22,R23,R24,R25,R26,R27,R28,R29 | R_0402_5MIL_DWS | 9 | 270R/R0402
24 | C20,C17,C19,C23,C24 | C_0603_5MIL_DWS | 5 | 22uF/6.3V/20%/X5R/C0603
25 | D1 | SOD-123_1C-2A_KA | 1 | 1N4148W/SOD123
26 | Q2 | SOT23 | 1 | BC817-40(SOT23)
27 | BOOT1 | YTS-A016-X | 1 | YTS-A016-X
28 | C11,C12,C25,C28,C30 | C_0402_5MIL_DWS | 5 | 2.2uF/6.3V/20%/X5R/C0402
29 | C15,C16 | C_0402_5MIL_DWS | 2 | 18pF/50V/5%/C0G/C0402
30 | HCEC1,HHPD1,HSCL1,HSDA1 | TESTPAD_40-ROUND | 4 | TESTPAD
31 | FUSE1 | FUSE-1206 | 1 | 1N5819S4(SOD-123)
32 | L1 | CD32 | 1 | 2.2uH/1.5A/DCR=58mR/20%/3.00x3.00x1.50mm/CD32(NRS3015T2R2MNGH)
33 | Q1 | TSX-3.2x2.5mm_GND(3) | 1 | Q12MHz/20pF/10ppm/4P/3.2x2.5mm
34 | R2 | R_0402_5MIL_DWS | 1 | NA(10k/R0402)
35 | R3,R6 | R_0402_5MIL_DWS | 2 | 100R/R0402
36 | R4,R5 | R_0402_5MIL_DWS | 2 | 27R/R0402
37 | R10,R12 | R_0402_5MIL_DWS | 2 | 5.1k/1%/R0402
38 | R15 | R_0402_5MIL_DWS | 1 | 220k/R0402
39 | R16 | R_0402_5MIL_DWS | 1 | 49.9k/1%/R0402
40 | RM1,RM2 | RA1206_(4X0603)_4B8_xx | 2 | RA1206_(4x0603)_4B8_330R
41 | SWD1 | HN1x3 | 1 | NA(HN1x3)
42 | U1 | SO-8_208mil | 1 | ZD25Q16BTIGT(SOIC-8_208mils)
43 | U2 | QFN56_7x7_Pitch_0.4mm | 1 | RP2040(QFN-56_7x7mm_P0.4mm)
44 | U3 | SOT-23-5 | 1 | SY8089AAAC(SOT23-5)
45 | U5,U6,U7 | TSSOP20_Pitch-0.65mm_6.6x4.5x1.2mm | 3 | 74LVC245APW(TSSOP20)
46 | SPK1 | Speaker_QMB-09B-03_1-Plus_2-Minus | 1 | Speaker_QMB-09B-03(1.5-5.0V_2.7kHz_F9.0mm*H5.5mm)
47 | R7 | R_1206_5MIL_DWS | 1 | 47R/R1206
48 | FID1 | Fiducial1x3_Past | 1 | Fiducial
49 | U4 | TQFP44_NEO6502 | 1 | W65C02S6TQTG-14(TQFP44)
50 | SWITCH1 | DSHP04TS-S-1.27mm_Half_4_Slide | 1 | DSHP04TS-S

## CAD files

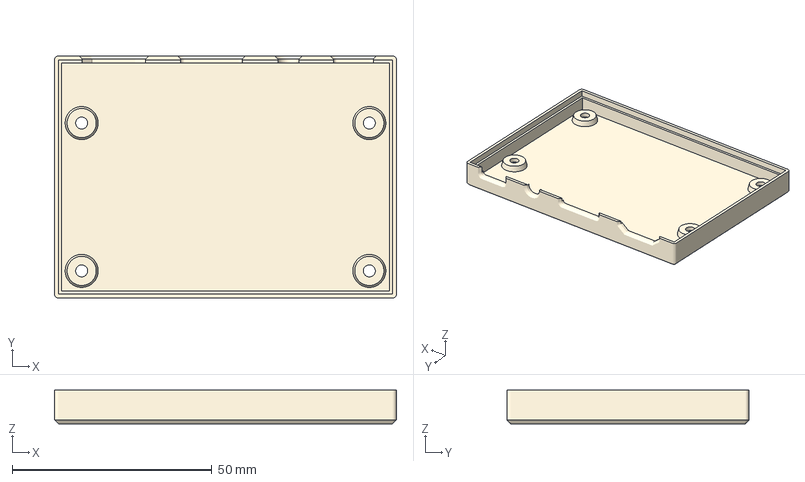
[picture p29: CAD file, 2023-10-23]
HARDWARE/3D printed Case/Neo6502_Rev_B v10-bottom.3mf
85.6 x 60.6 x 8.50 mm

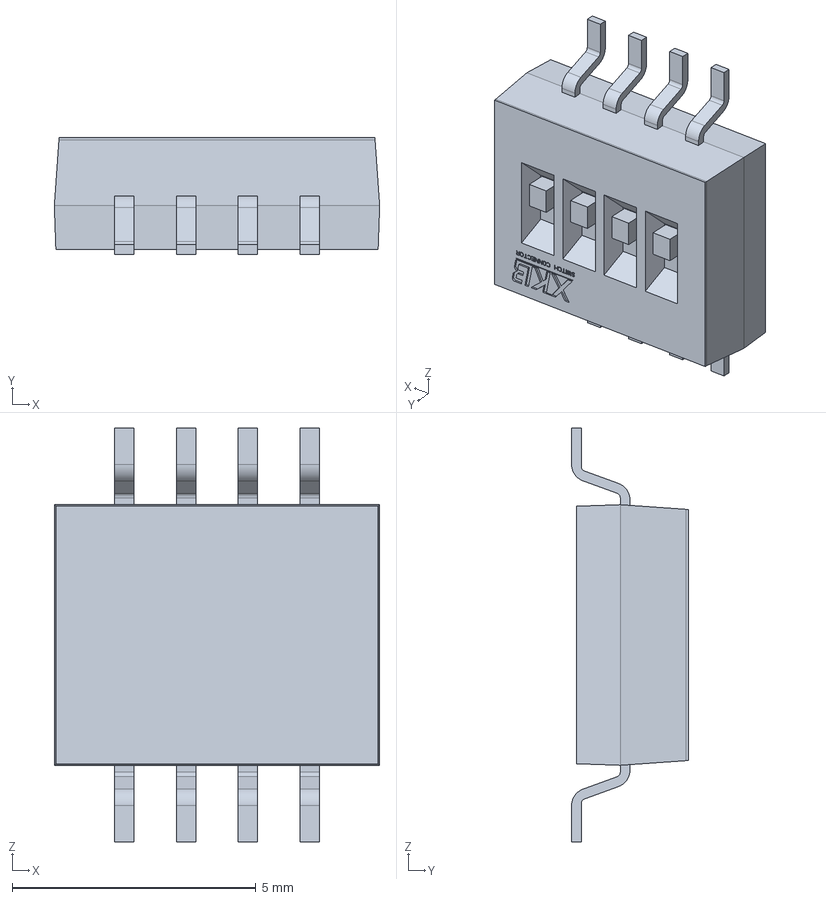
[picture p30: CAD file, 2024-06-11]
HARDWARE/Neo6502-rev-B1/3d/dshp04ts-s.stp
6.68 x 2.40 x 8.50 mm

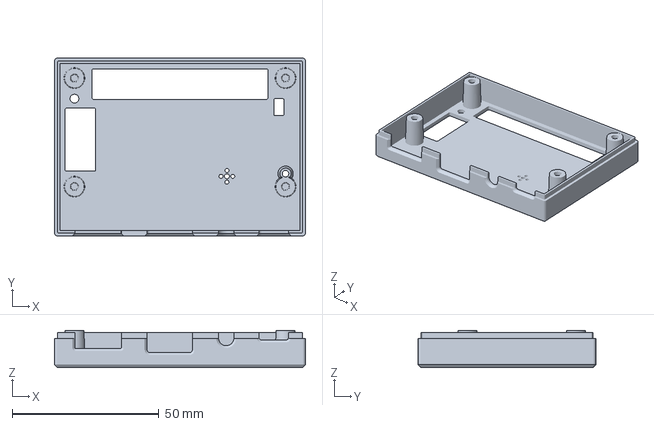
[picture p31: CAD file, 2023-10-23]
HARDWARE/3D printed Case/Neo6502_Rev_B v10-top-MMU.3mf
85.6 x 60.6 x 12.7 mm

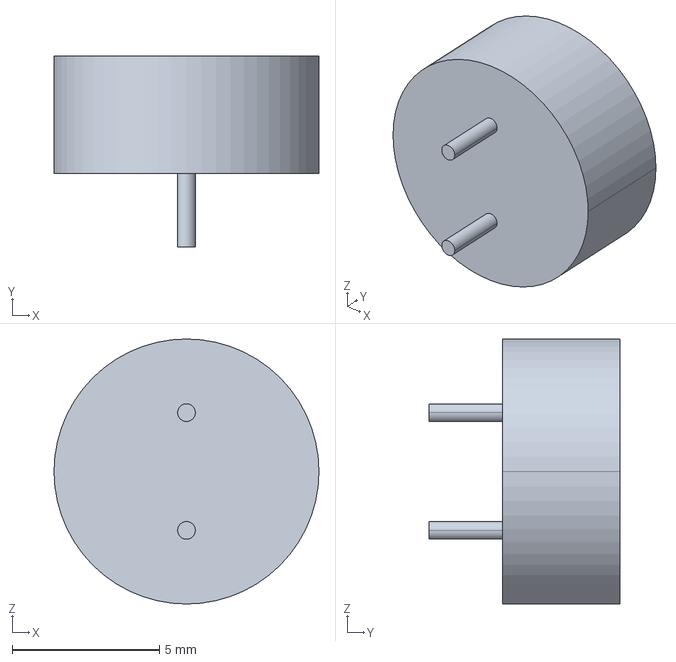
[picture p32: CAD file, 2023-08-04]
HARDWARE/Neo6502-rev-B1/3d/Speaker_QMB-09B-03(KSTG931APL-H2).STEP
9.00 x 6.50 x 9.00 mm

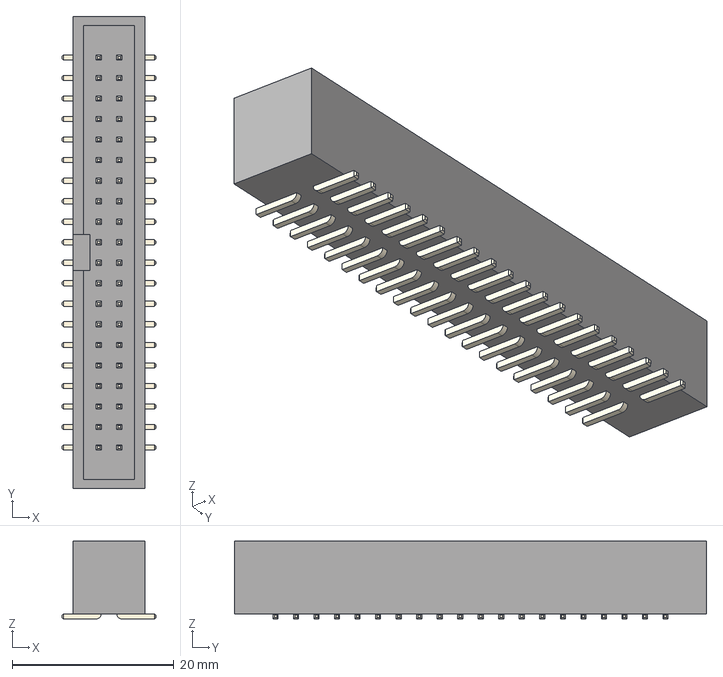
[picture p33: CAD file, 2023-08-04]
HARDWARE/Neo6502-rev-B1/3d/GBH254SMT-40(B-V-40-LF)(IDC-Header_2x20_P2.54mm_Vertical_SMD).step
11.6 x 58.4 x 9.64 mm

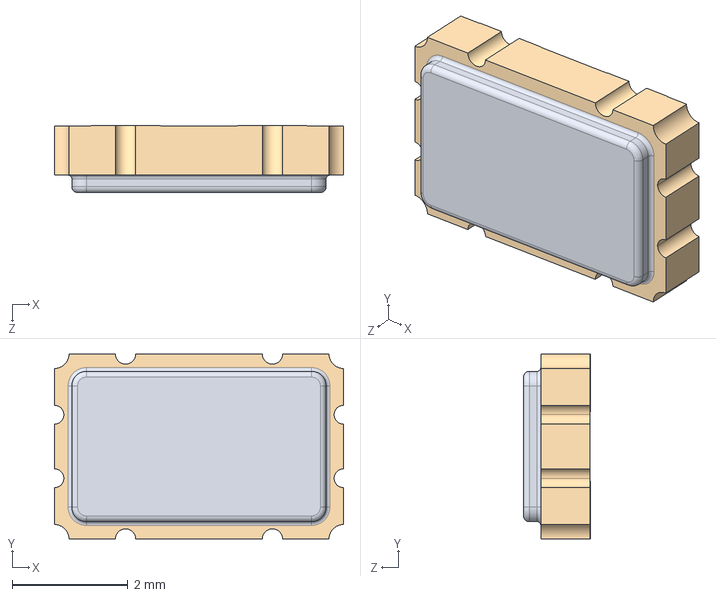
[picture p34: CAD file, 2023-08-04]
HARDWARE/Neo6502-rev-B1/3d/QSG5032.step
5.00 x 3.20 x 1.16 mm

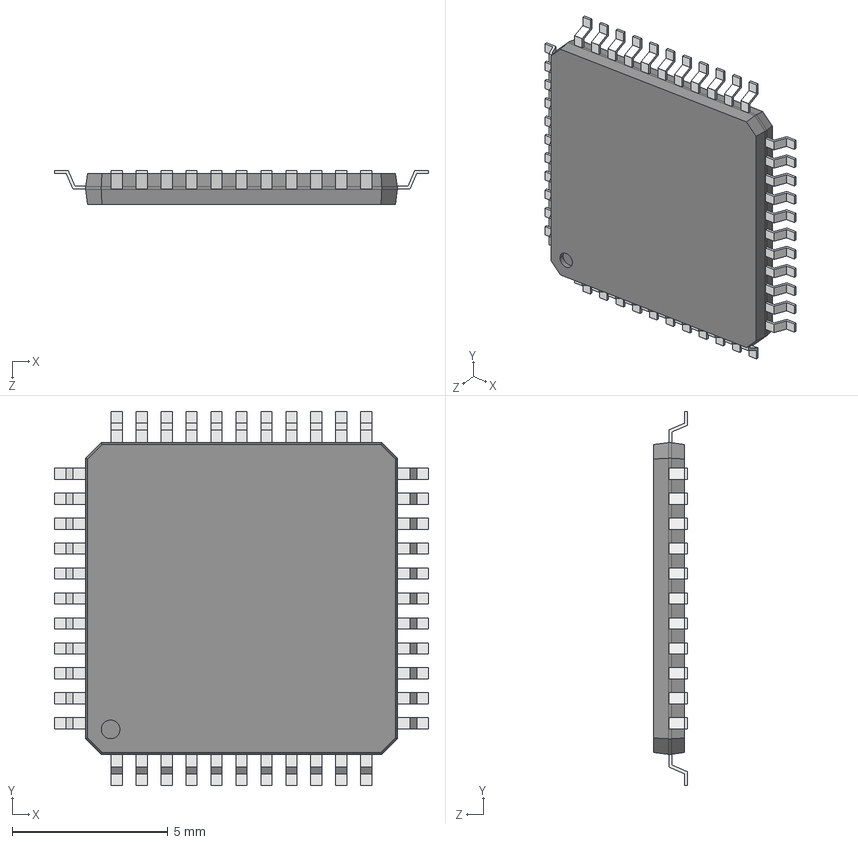
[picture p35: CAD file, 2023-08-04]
HARDWARE/Neo6502-rev-B1/3d/TQFP-44-10x10x1mm_Step-0.80mm.STEP
12.0 x 12.0 x 1.10 mm
pin001
pin021
pin022
pin020
pin019
pin018
pin017
pin024
pin023
pin007
pin003
pin015
pin014
pin013
pin012
pin011
pin010
pin009
pin008
pin006
pin005
pin004
pin002
pin016
pin027
pin037
pin025
pin026
pin036
pin035
pin034
pin033
pin032
pin031
pin030
pin029
pin028
pin038
pin044
pin043
pin042
pin041
pin040
pin039

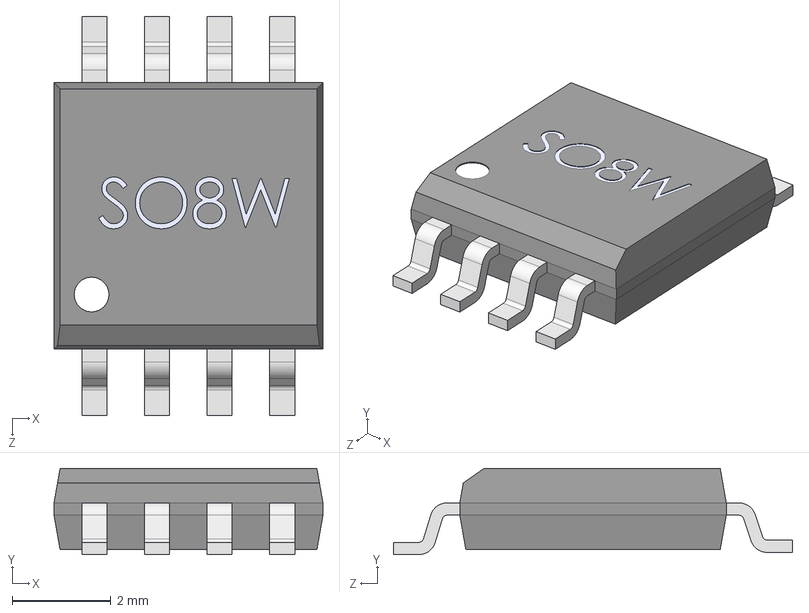
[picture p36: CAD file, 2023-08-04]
HARDWARE/Neo6502-rev-B1/3d/SO-8_208mil---SOIC8_Wide_5mmx5mm.step
5.46 x 1.75 x 8.10 mm

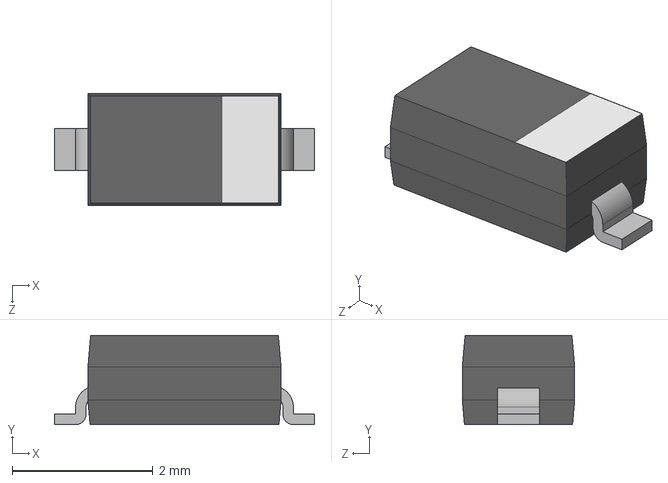
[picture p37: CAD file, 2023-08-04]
HARDWARE/Neo6502-rev-B1/3d/SOD123.step
3.70 x 1.27 x 1.60 mm

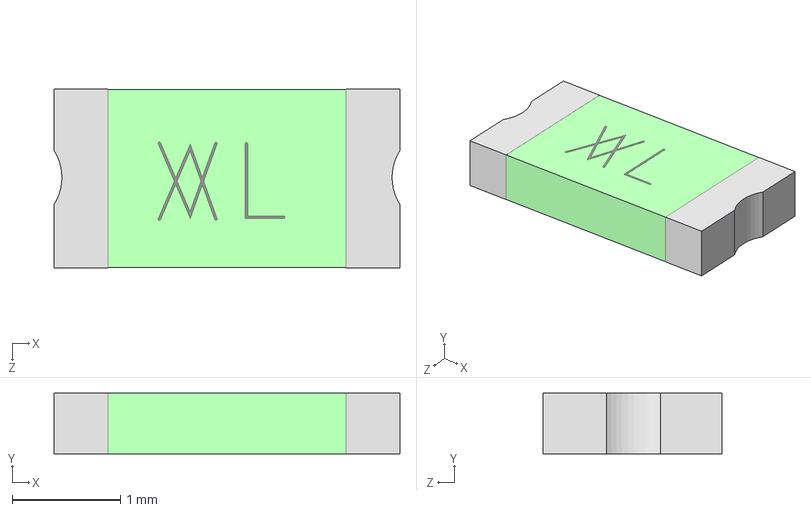
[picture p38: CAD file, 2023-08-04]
HARDWARE/Neo6502-rev-B1/3d/SMD075F.step
3.20 x 0.562 x 1.65 mm

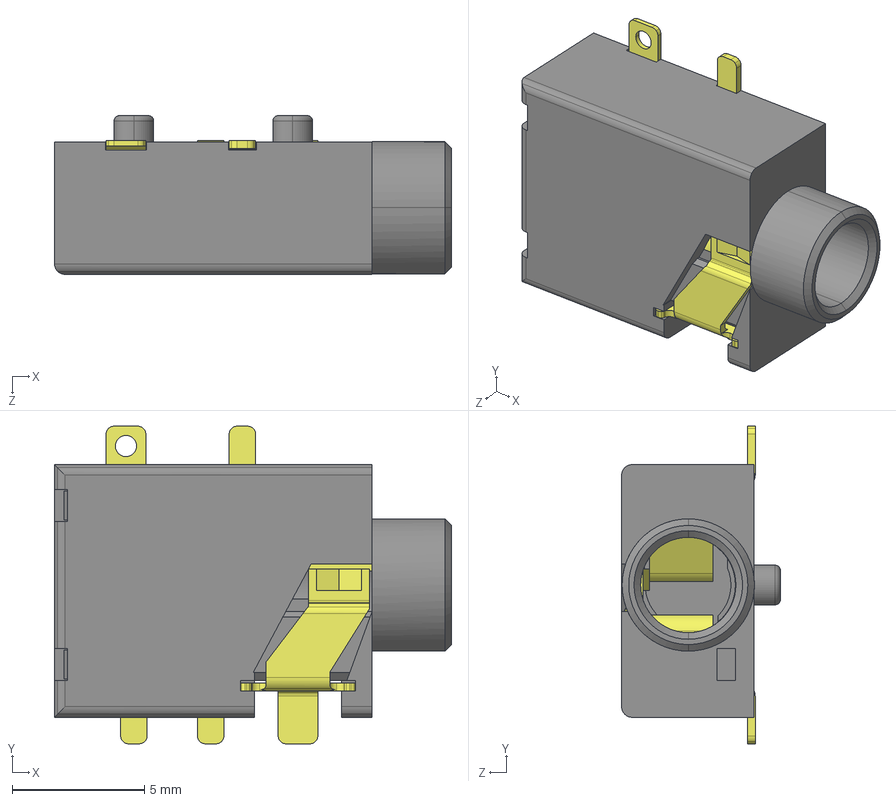
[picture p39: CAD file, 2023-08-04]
HARDWARE/Neo6502-rev-B1/3d/Audio_Jack-3.5mm---CUI_SJ1-3515-SMT-TR.step
15.0 x 12.0 x 6.00 mm

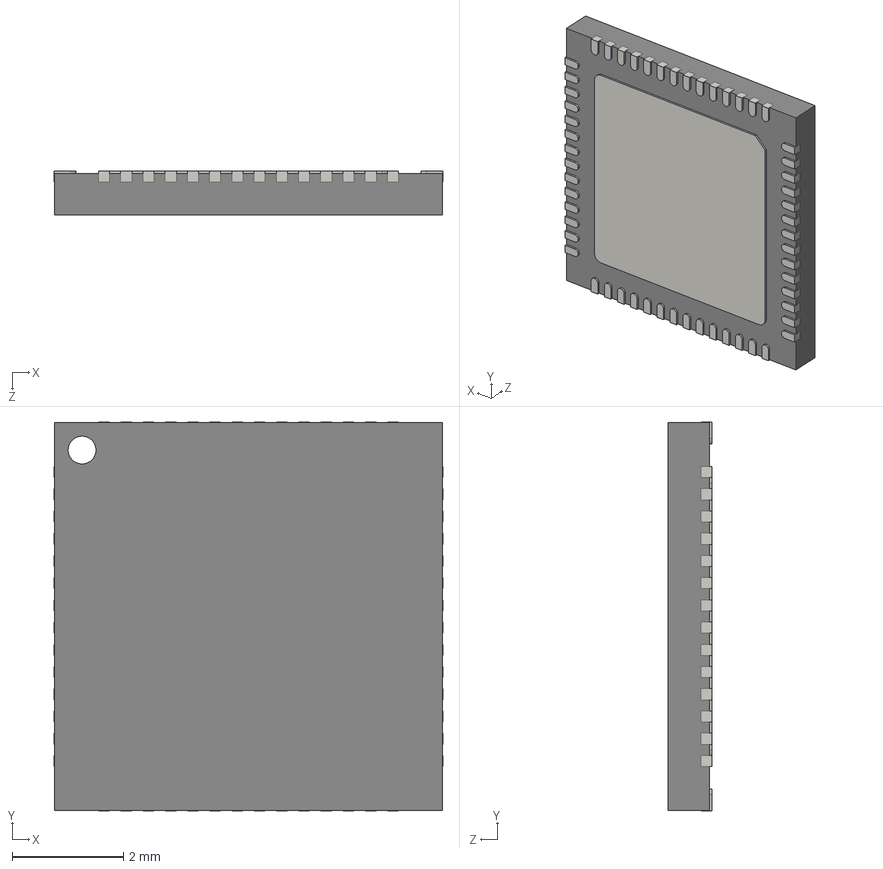
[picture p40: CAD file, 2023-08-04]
HARDWARE/Neo6502-rev-B1/3d/QFN56_0_4.step
7.00 x 7.00 x 0.8 mm

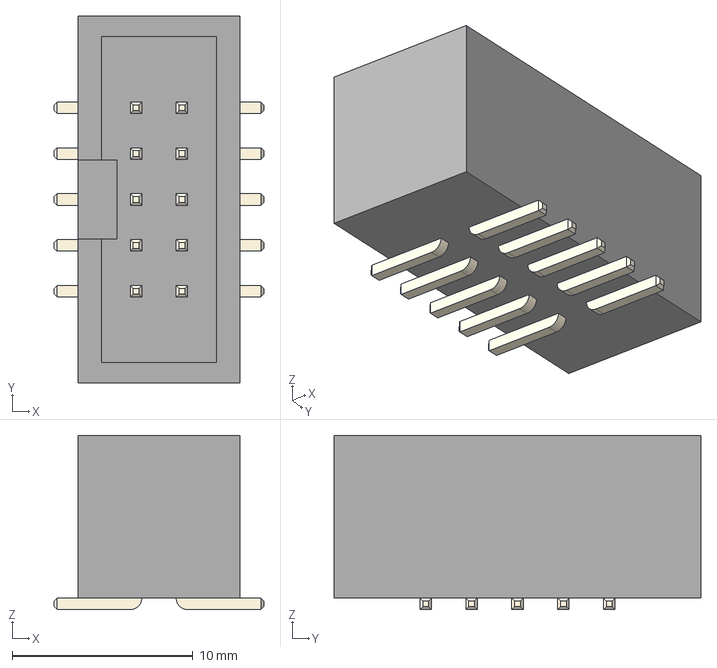
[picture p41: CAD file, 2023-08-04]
HARDWARE/Neo6502-rev-B1/3d/GBH254SMT-10(B-V-10-LF)(IDC-Header_2x05_P2.54mm_Vertical_SMD).step
11.6 x 20.3 x 9.64 mm

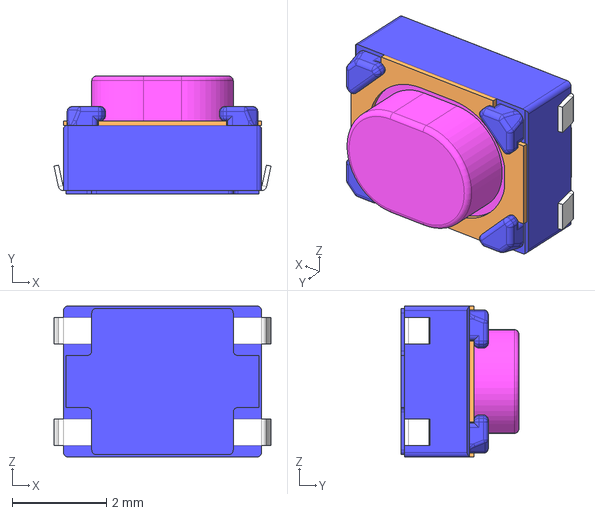
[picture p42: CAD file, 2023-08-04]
HARDWARE/Neo6502-rev-B1/3d/YTS-A016-X(SKRPABE010).stp
4.60 x 2.50 x 3.20 mm

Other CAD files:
HARDWARE/Neo6502-rev-B1/3d/USB-A-SMT-6.3H_HOST_Female(87583-2010RLF).STEP
HARDWARE/Neo6502-rev-B1/3d/USB-A-SMT-6.3H_HOST_Female(USB1046-GF-0190-L-B-A).STEP
HARDWARE/Neo6502-rev-B1/3d/SOT-23-5.step
HARDWARE/Neo6502-rev-B1/3d/HDMI_19POS_SMD_Wurth_Electronic-685119134923.stp
HARDWARE/3D printed Case/Neo6502_Rev_B v10-bottom.stl
HARDWARE/Neo6502-rev-B/3d/Audio_Jack-3.5mm---CUI_SJ1-3515-SMT-TR.step
HARDWARE/Neo6502-rev-B/3d/HDMI_19POS_SMD_Wurth_Electronic-685119134923.stp
HARDWARE/Neo6502-rev-B/3d/L-CD32_shielded.step
HARDWARE/Neo6502-rev-B/3d/QFN56_0_4.step
HARDWARE/Neo6502-rev-B/3d/QSG5032.step
HARDWARE/Neo6502-rev-B/3d/SMD075F.step
HARDWARE/Neo6502-rev-B/3d/SO-8_208mil---SOIC8_Wide_5mmx5mm.step
HARDWARE/Neo6502-rev-B/3d/SOD123.step
HARDWARE/Neo6502-rev-B/3d/SOT-23-5.step
HARDWARE/Neo6502-rev-B/3d/SOT-23.step
HARDWARE/Neo6502-rev-B/3d/Speaker_QMB-09B-03(KSTG931APL-H2).STEP
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

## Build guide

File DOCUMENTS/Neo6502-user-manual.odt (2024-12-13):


Neo6502

User Manual

Document revision 3.0, December 2024 | www.olimex.com

(http://www.olimex.com/)

# Introduction to Neo6502

The design goal of Neo6502 was to make simple modern retro computer with 6502 processor.

A computer with a modern video interface like HDMI, USB keyboard, and USB flash drive as storage. HDMI output was chosen as everyone has a TV with HDMI input at home and USB keyboards are the mainstream device for input.

With the task to provide HDMI and USB interface we choose RP2040 which already has DVI bit bang project and USB host.

RP2040 also has enough RAM so we decided to use RP2040 to emulate also the RAM memory for 6502.

For the 6502 processor we choose W65C02 from WDC as they are still in mass production and can be purchased freely.

The Neo name was taken for two reasons, first it implies the modern design, then we liked the analogy with the movie The Matrix as W65C02 lives in a virtual world and thinks it has real memory, video, and keyboard but actually all this is virtual and emulated by the RP2040.

Neo6502 is Open Source Hardware, all CAD files, and firmware are available, so people can study and modify.

The features of Neo6502 are:

- real W65C02 processor executing every instruction as it was executed in early retro computers, no emulation for the processor, all timing is exact;
- RP2040 with 2MB of SPI Flash, east to load new firmware via drag and drop virtual drive;
- HDMI output;
- USB host which can be used for programming and to connection to keyboard, mouse, USB flash etc;
- Audio buzzer which you can enable/disable;
- Audio 3.5mm connector for external audio amplifier;
- USB-C connector for power supply;
- 6502 BUS connector with all signals;
- UEXT connector with I2C, UART and SPI for connecting to external boards
- 4 position slide switch which allows buzzer enable and connection of RESB, NMIB and IRQB to UEXT GPIO signals if needed;
- RP2040 programming bootloader button;
- Four mounting holes 3.3mm diameter;
- Dimensions: (80 x 55)mm.

+ Important notice: If Neo6502 is used without a box be careful of placing it on a metal surface, also be careful of dropping metal objects on top of the PCB! This can lead to short-circuits and damage.

## Order codes for RP2040-PICO30 and accessories:

Neo6502 (https://www.olimex.com/Products/Retro-Computers/Neo6502/open-source-hardware) Industrial-grade modern retro computer

Box-Neo6502-B (https://www.olimex.com/Products/Retro-Computers/BOX-Neo6502-B/open-source-hardware) Plastic box with blue logo

Box-Neo6502-R (https://www.olimex.com/Products/Retro-Computers/BOX-Neo6502-R/open-source-hardware) Plastic box with red logo

USB-CABLE-AM-AM-1-8M (https://www.olimex.com/Products/Components/Cables/USB-CABLE-AM-AM-1-8M/) USB-A to A cable necessary for programming RP2040 firmware

CABLE-USB-A-C-1M (https://www.olimex.com/Products/Components/Cables/CABLE-USB-A-C-1M/) USB-C cable for power supply

CABLE-HDMI-50CM (https://www.olimex.com/Products/Components/Cables/CABLE-HDMI-50CM/) HDMI cable

USB-FLASH-8GB (https://www.olimex.com/Products/Components/Storage/USB-FLASH-8GB-THN-U202W0080E4/) USB flash drive (required for Apple emulator)

UEXT modules (https://www.olimex.com/Products/Modules/) UEXT expansion modules for Neo6502 UEXT connector

# HARDWARE

## Neo6502 schematics:

Neo6502 latest schematic at time of writing is available at GitHub – Neo6502_Rev_B1.pdf (https://github.com/OLIMEX/Neo6502/blob/main/HARDWARE/Neo6502-rev-B1/Neo6502_Rev_B1.pdf)

All schematics can be found in this repo:

https://github.com/OLIMEX/Neo6502/tree/main/HARDWARE

Hardware revision changes here:

https://github.com/OLIMEX/Neo6502/blob/main/HARDWARE/README.md

## Neo6502 layout:


USB host for keyboard, mouse, flash memory

HDMI connector

Audio output 3.5mm

USB-C power

W65C02

UEXT connector

Configuration slide switch

BOOT button for programming

6502 bus

2MB Flash

RP2040

## Neo6502 6502 bus connector:

All 6502 signals are available on BUS1 connector for attaching external hardware on it.

+5V, 3.3V, GND

D0-D7, A0-A15, PHI2, R/W, RESB, SOB, MLB, VPB, SYNC, NMIB, IRQB

Two SWD signals (SWDIO, SWCLK) for RP2040 debugging are also present, these should be left free (if not used for debugging), on the external 6502 peripheral boards.


## UEXT connector:

UEXT connector stands for Universal EXTension connector and contains +3.3V, GND, I2C, SPI, UART signals.

There are different types of UEXT connectors, but layout is usually the same.

The original UEXT connector is 0.1” 2.54mm step boxed plastic connector. All signals are at 3.3V levels.


Olimex has developed number of MODULES (https://www.olimex.com/Products/Modules/) with this connector. There are temperature, humidity, pressure, magnetic field, light sensors. Modules with LCDs, LED matrix, relays, Bluetooth, ZigBee, WiFi, GSM, GPS, RFID, RTC, EKG, sensors and etc.

Neo6502 UEXT connector is wired to RP2040 GPIOs as follows:


Slide configuration switch can enable/disable the buzzer, also can connect or disconnect RESB, NMIB and IRQB to RP2040 UEXT signals.


By default Neo6502 is shipped with all sections connected on the switch i.e. buzzer is enabled and all signals are wired to RP2040. This means you can’t use SPI on UEXT connector if you do not disconnect these signals.

# SOFTWARE:

Neo6502 is open flexible system as everything is virtual and depend on RP2040 firmware, this allow you to emulate old architectures like Apple ][ and Oric Atmos, or to make your own completely new architecture.

Veselin Sladkov (veselin.sladkov@gmail.com) did amazing work for Neo6502 and created Apple ][, Oric Atmos and Apple Iic emulation with Reload emulator (https://github.com/vsladkov/reload-emulator).

The reload emulator require some ROMs and disks which are hosted on olimex’s ftp (https://ftp.olimex.com/Neo6502/).

Rien Matthijsse (rien@marobi.com) made several versions of RP2040 emulator and Basic port working on Neo6502 in his GitHub repository (https://github.com/marobi).

Paul Robson (paul@robsons.org.uk ) made special version of Neo6502 Basic on GitHub (https://github.com/paulscottrobson/neo6502) and web browser emulator (http://www.robsons.org.uk/neo6502/neo.html).

## DEFAULT FIRMWARE

The board arrives programmed with Apple II emulator. To use the board you also need to prepare a USB flash drive with “Total Replay v5.1.hdv”. Download resources from here:

https://ftp.olimex.com/Neo6502/

If you don’t have a flash drive, maybe change the software to the NeoBasic.

## Programming RP2040

The RP2040 firmware is UF2 file. You can get pre-build firmware of reload emulator on olimex’s ftp.

We recommend you for Apple ][ to use:

https://ftp.olimex.com/Neo6502/apple2e-5.uf2

or older version:

https://ftp.olimex.com/Neo6502/old-uf2/apple2_800x600_400MHz.uf2

This firmware have latest PRODOS and several games on it ready to play.

For Oric Atmos we recommend you to use:

https://ftp.olimex.com/Neo6502/old-uf2/oric_960x540_372MHz.uf2

To program the .uf2 files you need USB A to A cable.

You disconnect the power supply UEB-C cable, then press the BOOT button and plug the USB-A cable to USB host connector. Your computer will show a new drive. Once this new drive shows copy the .uf2 file to it. Once the firmware is programmed the drive will disappear. This means the RP2040 now has the new firmware loaded.

You need to disconnect the USB-A cable and to attach the USB-C power supply cable, in the USB host you should now plug the keyboard and start working with the emulator.

# FAQ

Q: I have LG monitor and there is no picture on the HDMI. I did everything correctly. My board is hardware revision B. Is my board broken?

A: Try all steps again. If problem remains and if you have revision A or B board you might try to close FUSE pads to enable 5V on the HDMI connector. If you have B1 or newer revision FUSE should have a diode component already placed.

To perform the fix look under the HDMI connector, there are two pads that should be empty that have word "FUSE" nearby. Connect the pads together soldering a small wire between them or 0R resistor (the best idea is to solder diode 1N5819/S4 but it has direction so be careful, cathode should be towards HDMI connector, diode would prevent HDMI monitor powering the board). Testing with a wire is fine if you don't have such diode, but if it works in future you might want to buy such diode and solder there (just make sure about the direction).

# Document revision history

Revision 1.0 October 2023

Revision 2.0 June 2024

- Formatting and spelling improvements.

Revision 3.0 December 2024

- Fixed links.

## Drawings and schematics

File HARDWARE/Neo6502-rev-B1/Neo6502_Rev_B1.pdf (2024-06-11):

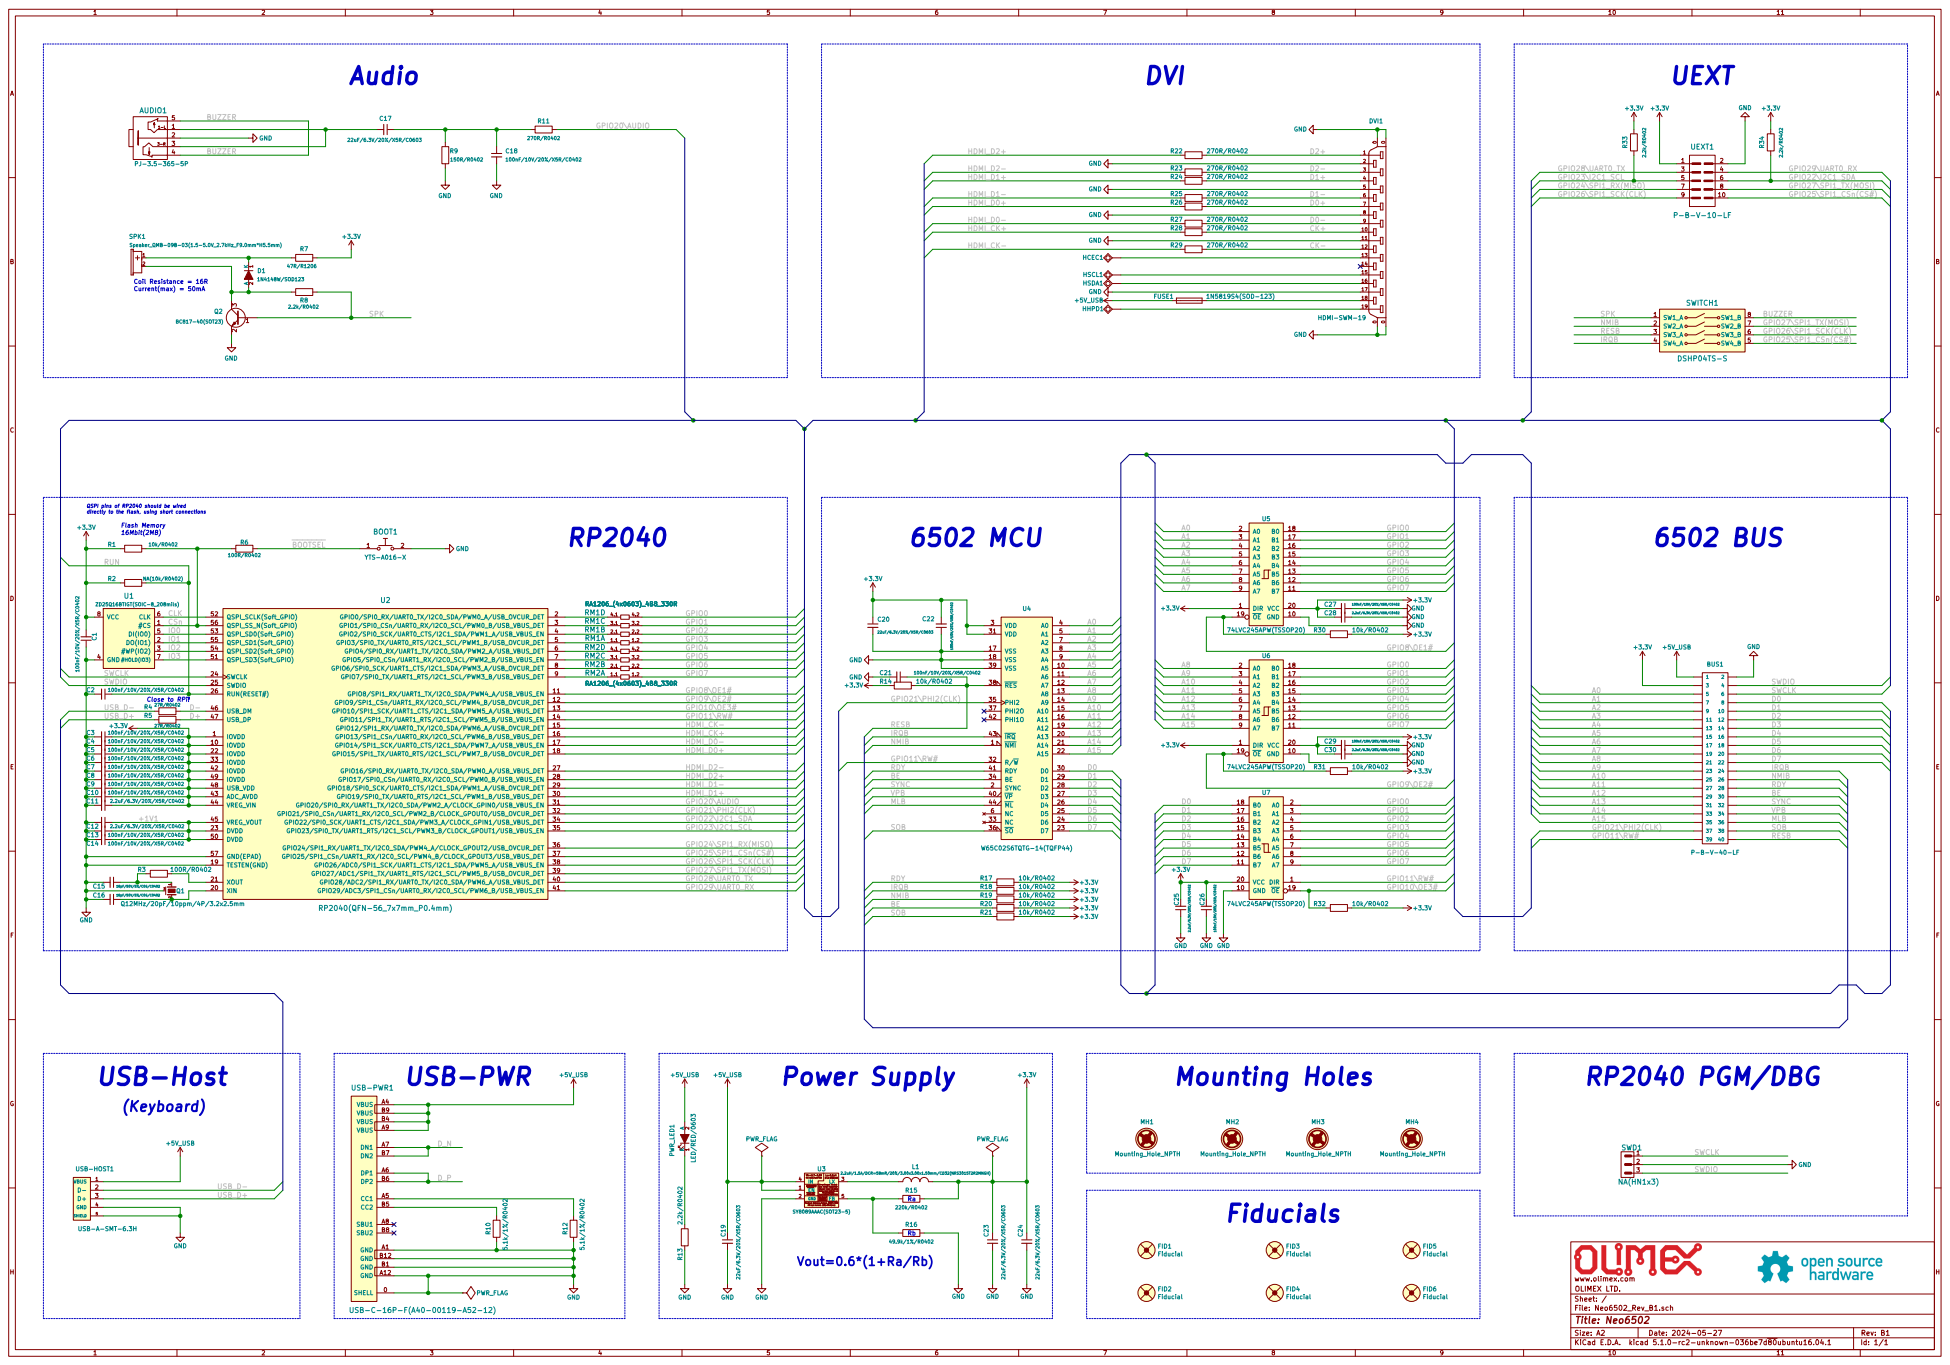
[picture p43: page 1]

load current capability! Lx=2.2uH

Do not float. Enable control. FB Input Current, I(FB)=50nA(max) Feedback Reference Voltage, V(REF)=0.6V

File: Neo6502_Rev_B1.sch Sheet: / OLIMEX LTD. www.olimex.com

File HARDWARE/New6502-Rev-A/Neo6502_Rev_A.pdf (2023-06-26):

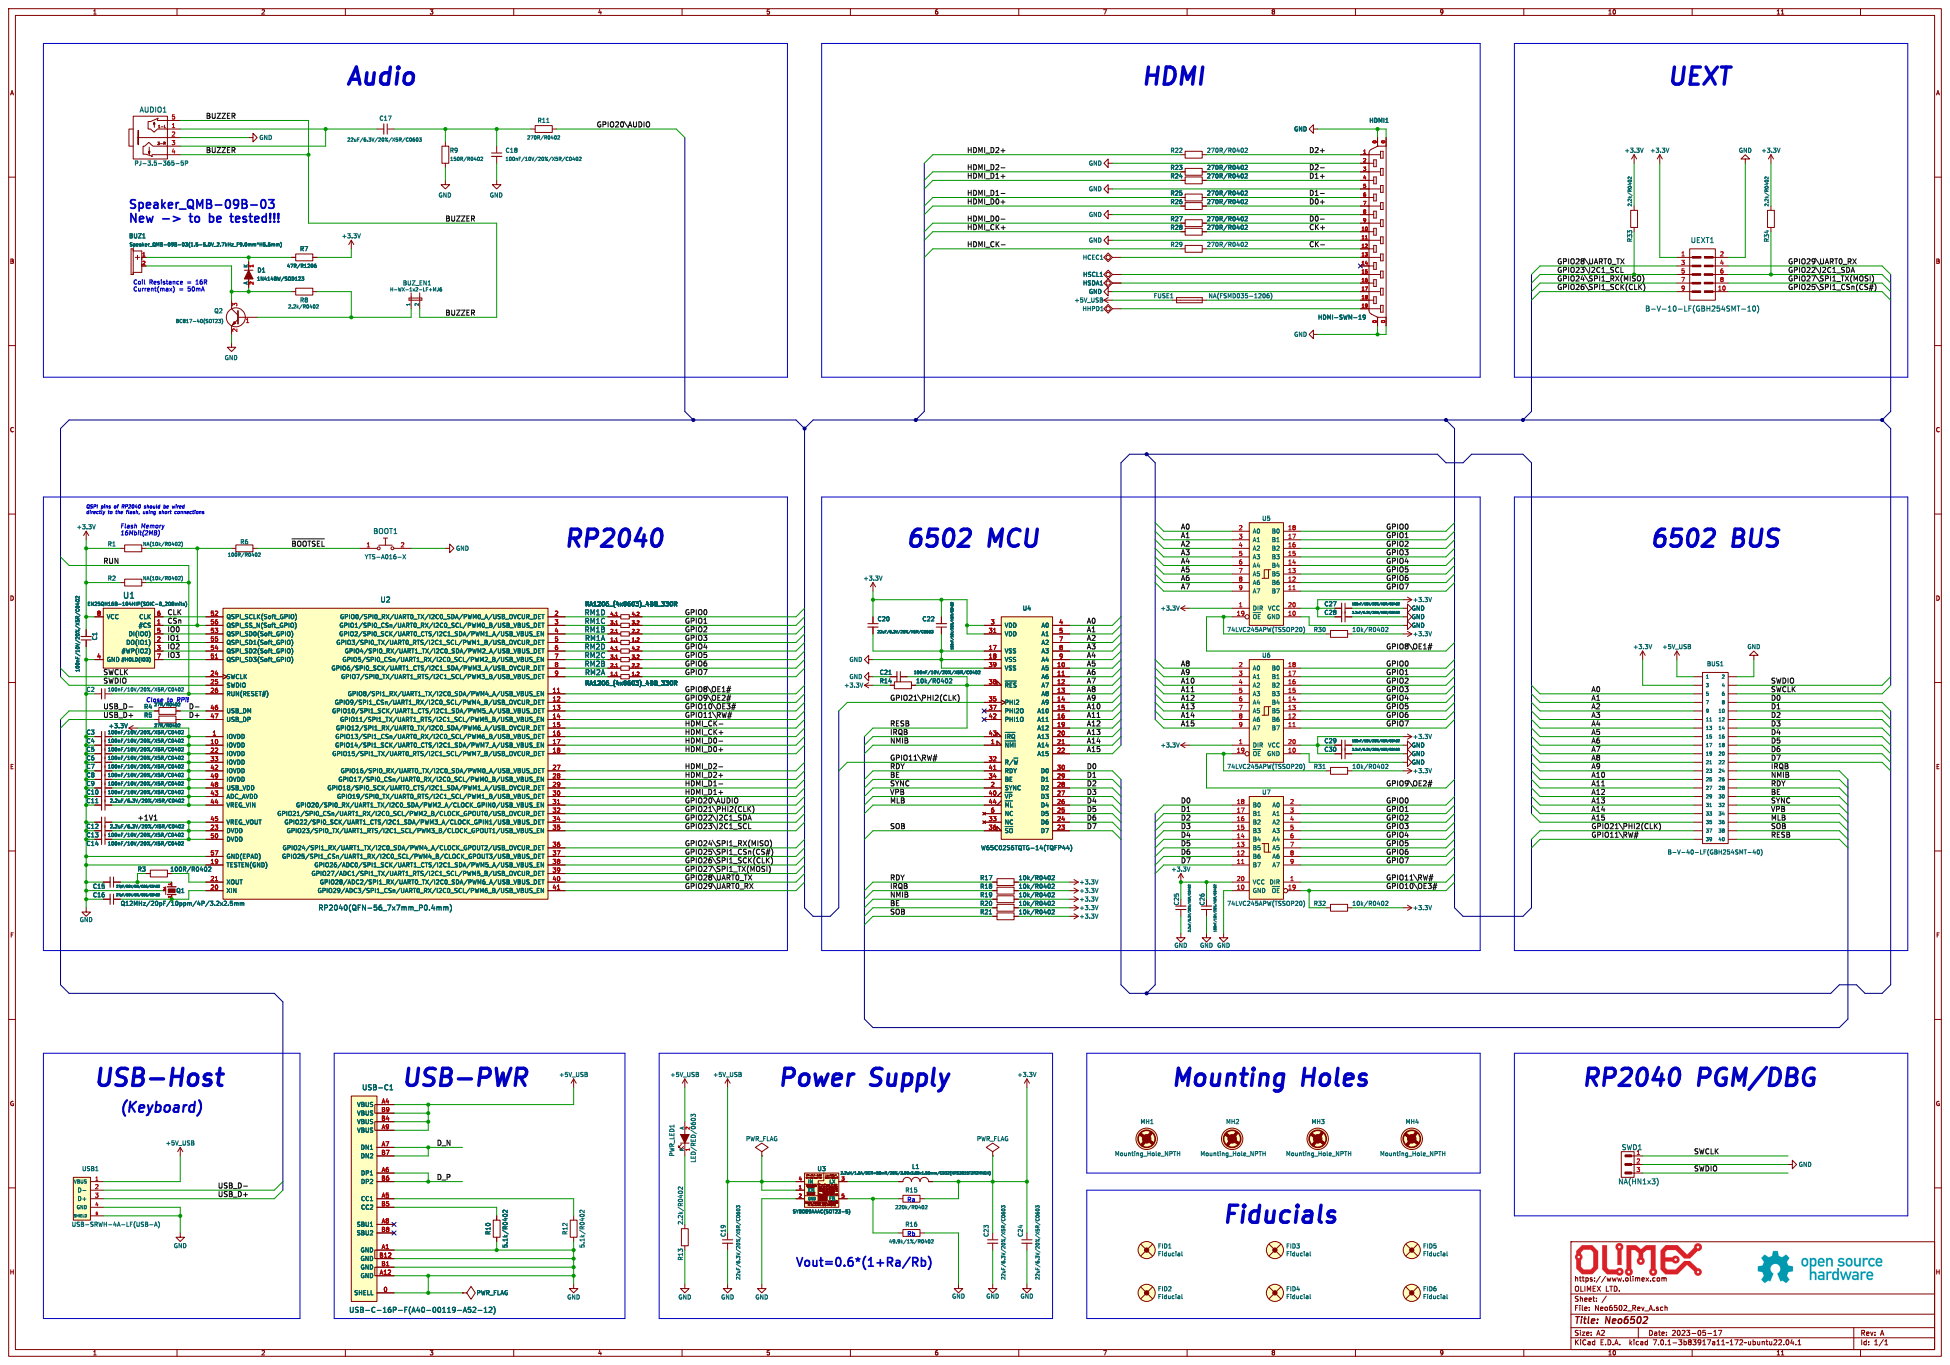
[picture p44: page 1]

QSPI pins of RP2040 should be wired
directly to the flash, using short connections Flash Memory

Close to RPi! (Keyboard)
A9 A10 USB_D-

5 USB1 USB-SRWH-4A-LF(USB-A)

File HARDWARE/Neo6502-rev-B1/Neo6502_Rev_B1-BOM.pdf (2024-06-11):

Neo6502_Rev_B1_BOM | 05/28/2024

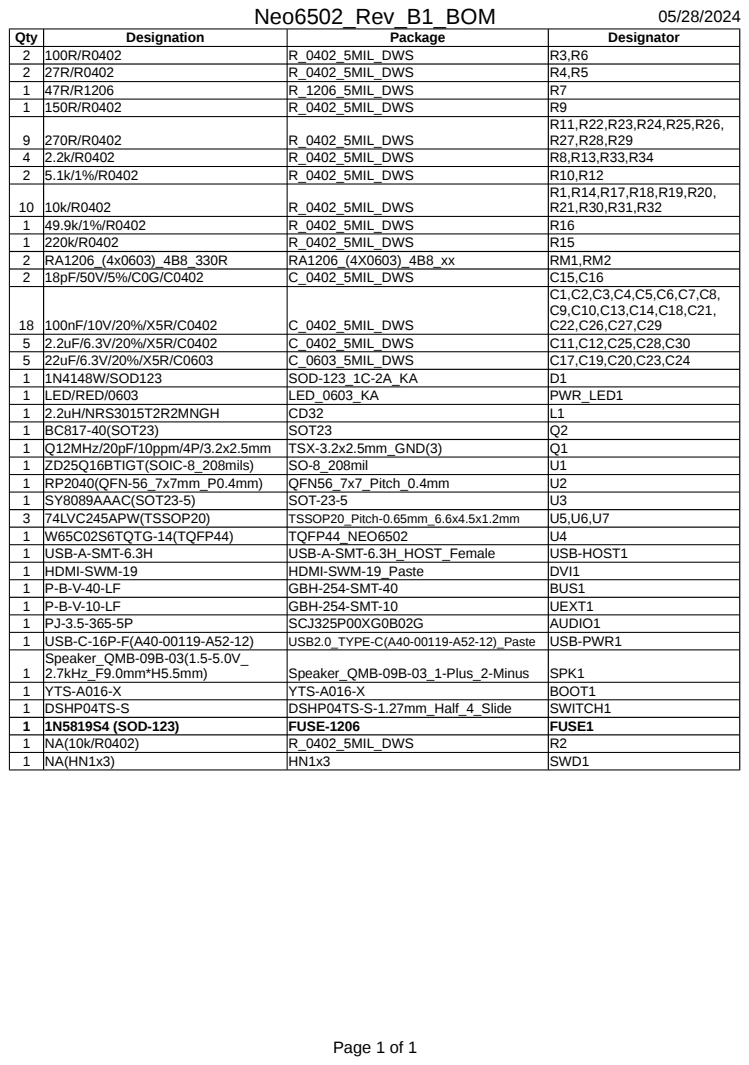
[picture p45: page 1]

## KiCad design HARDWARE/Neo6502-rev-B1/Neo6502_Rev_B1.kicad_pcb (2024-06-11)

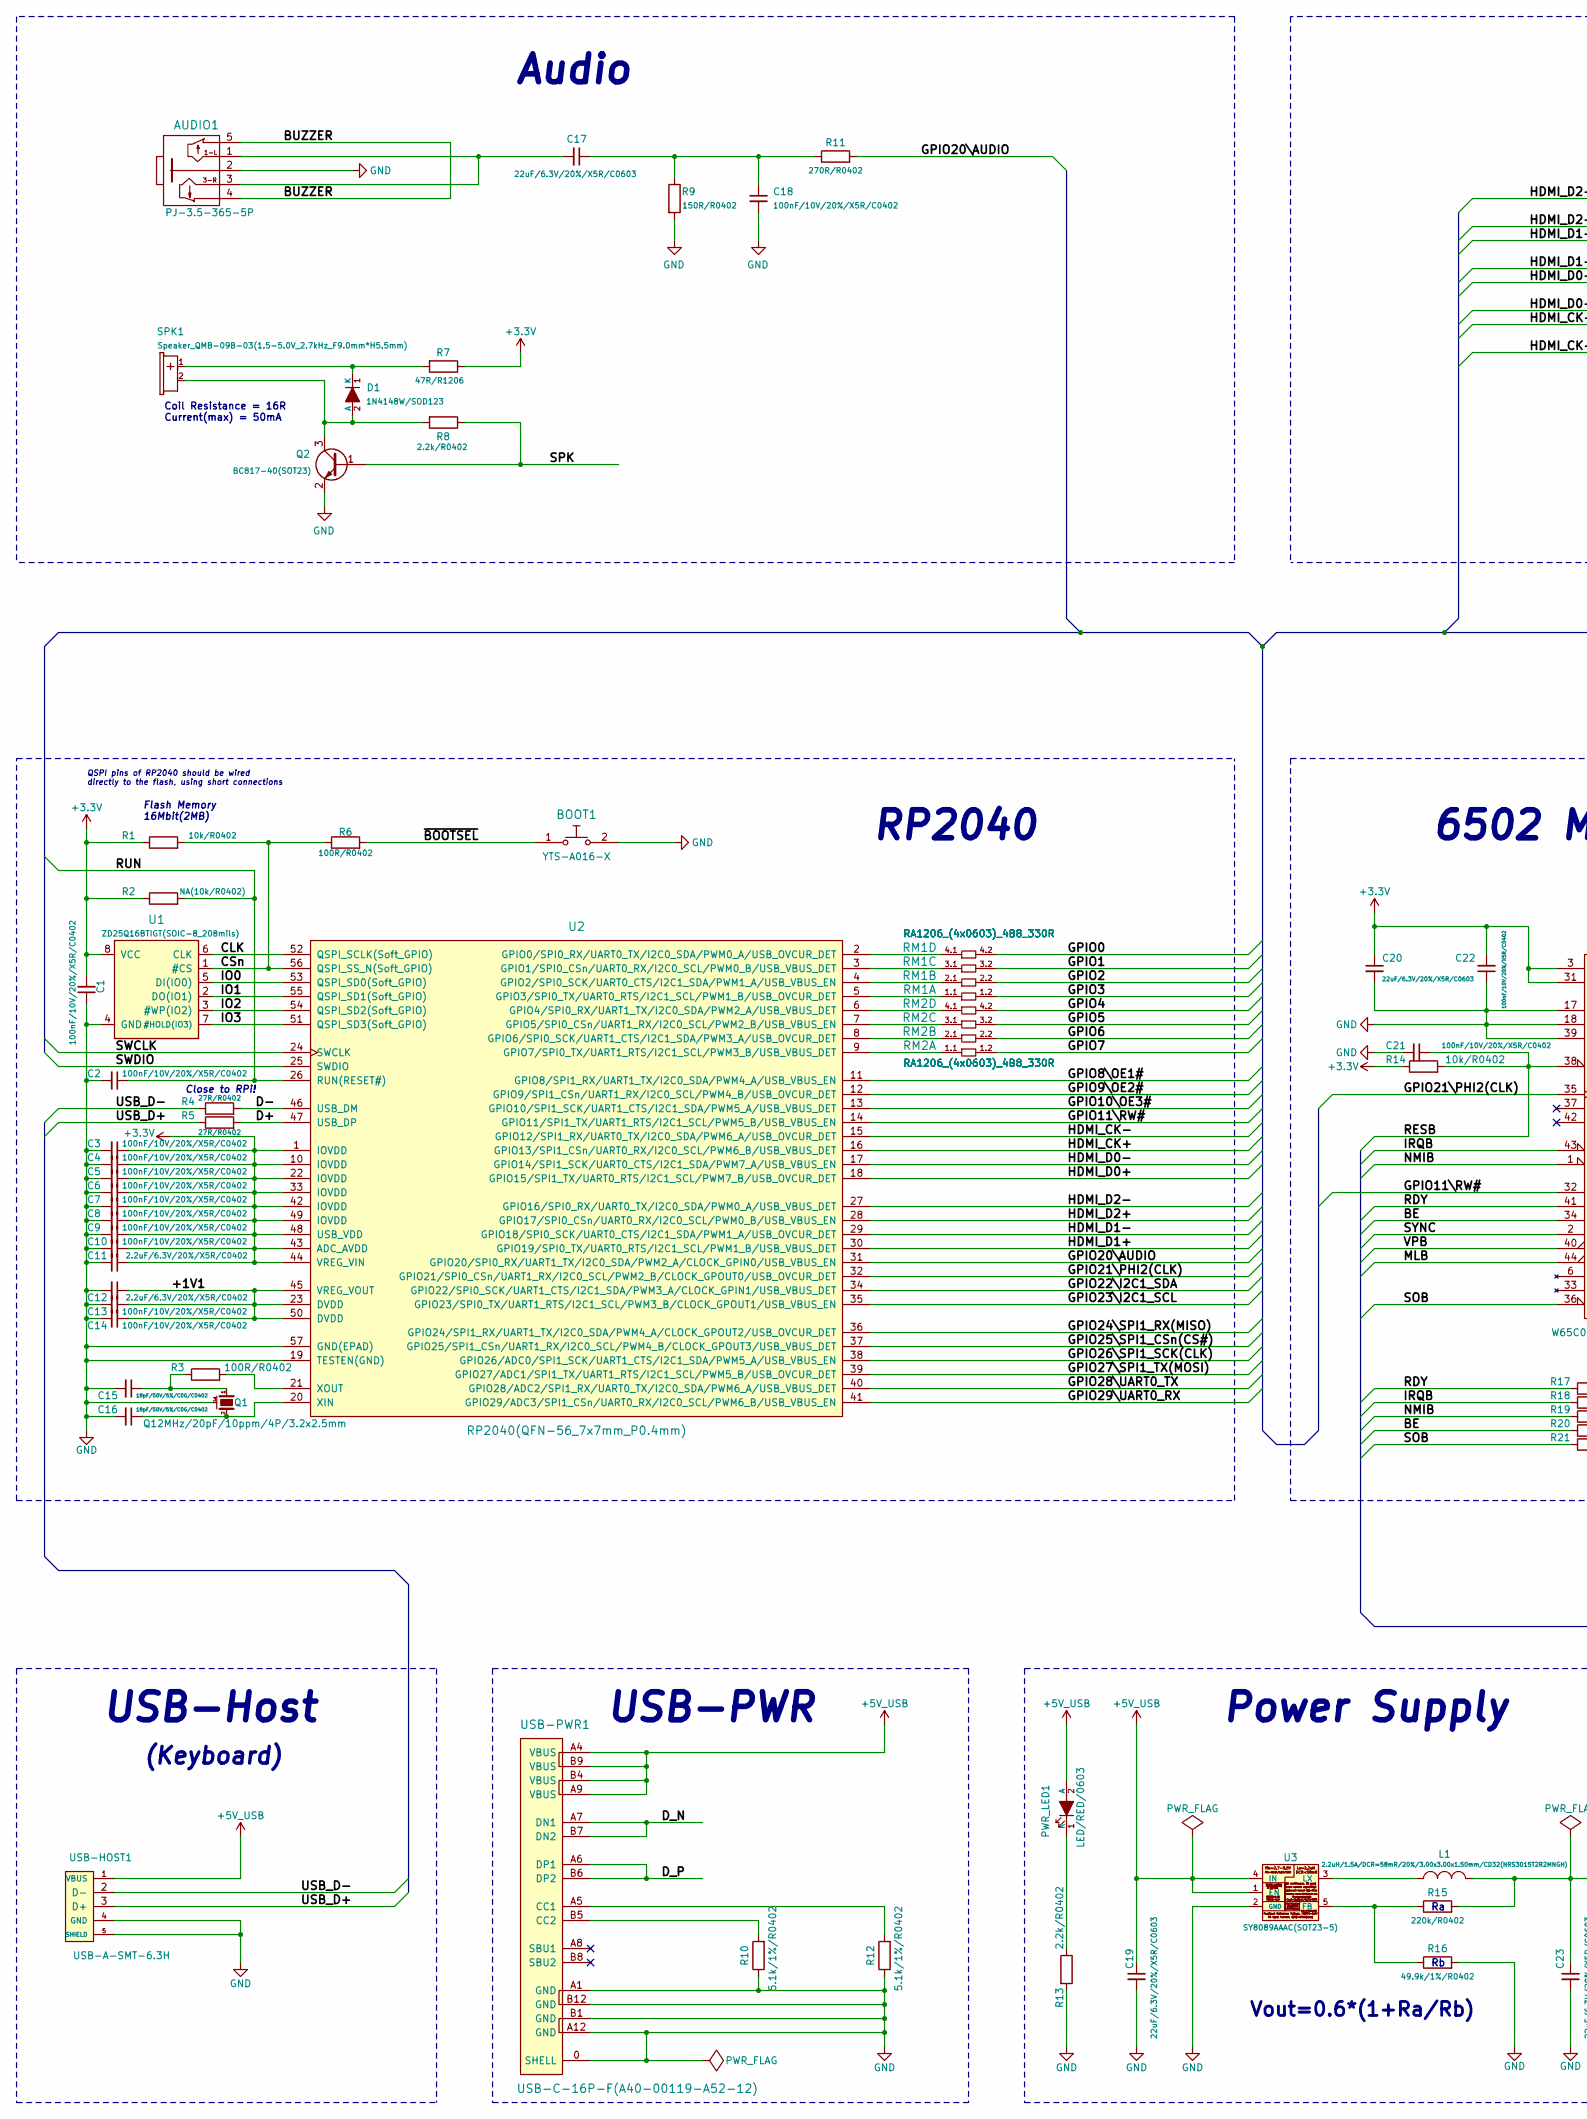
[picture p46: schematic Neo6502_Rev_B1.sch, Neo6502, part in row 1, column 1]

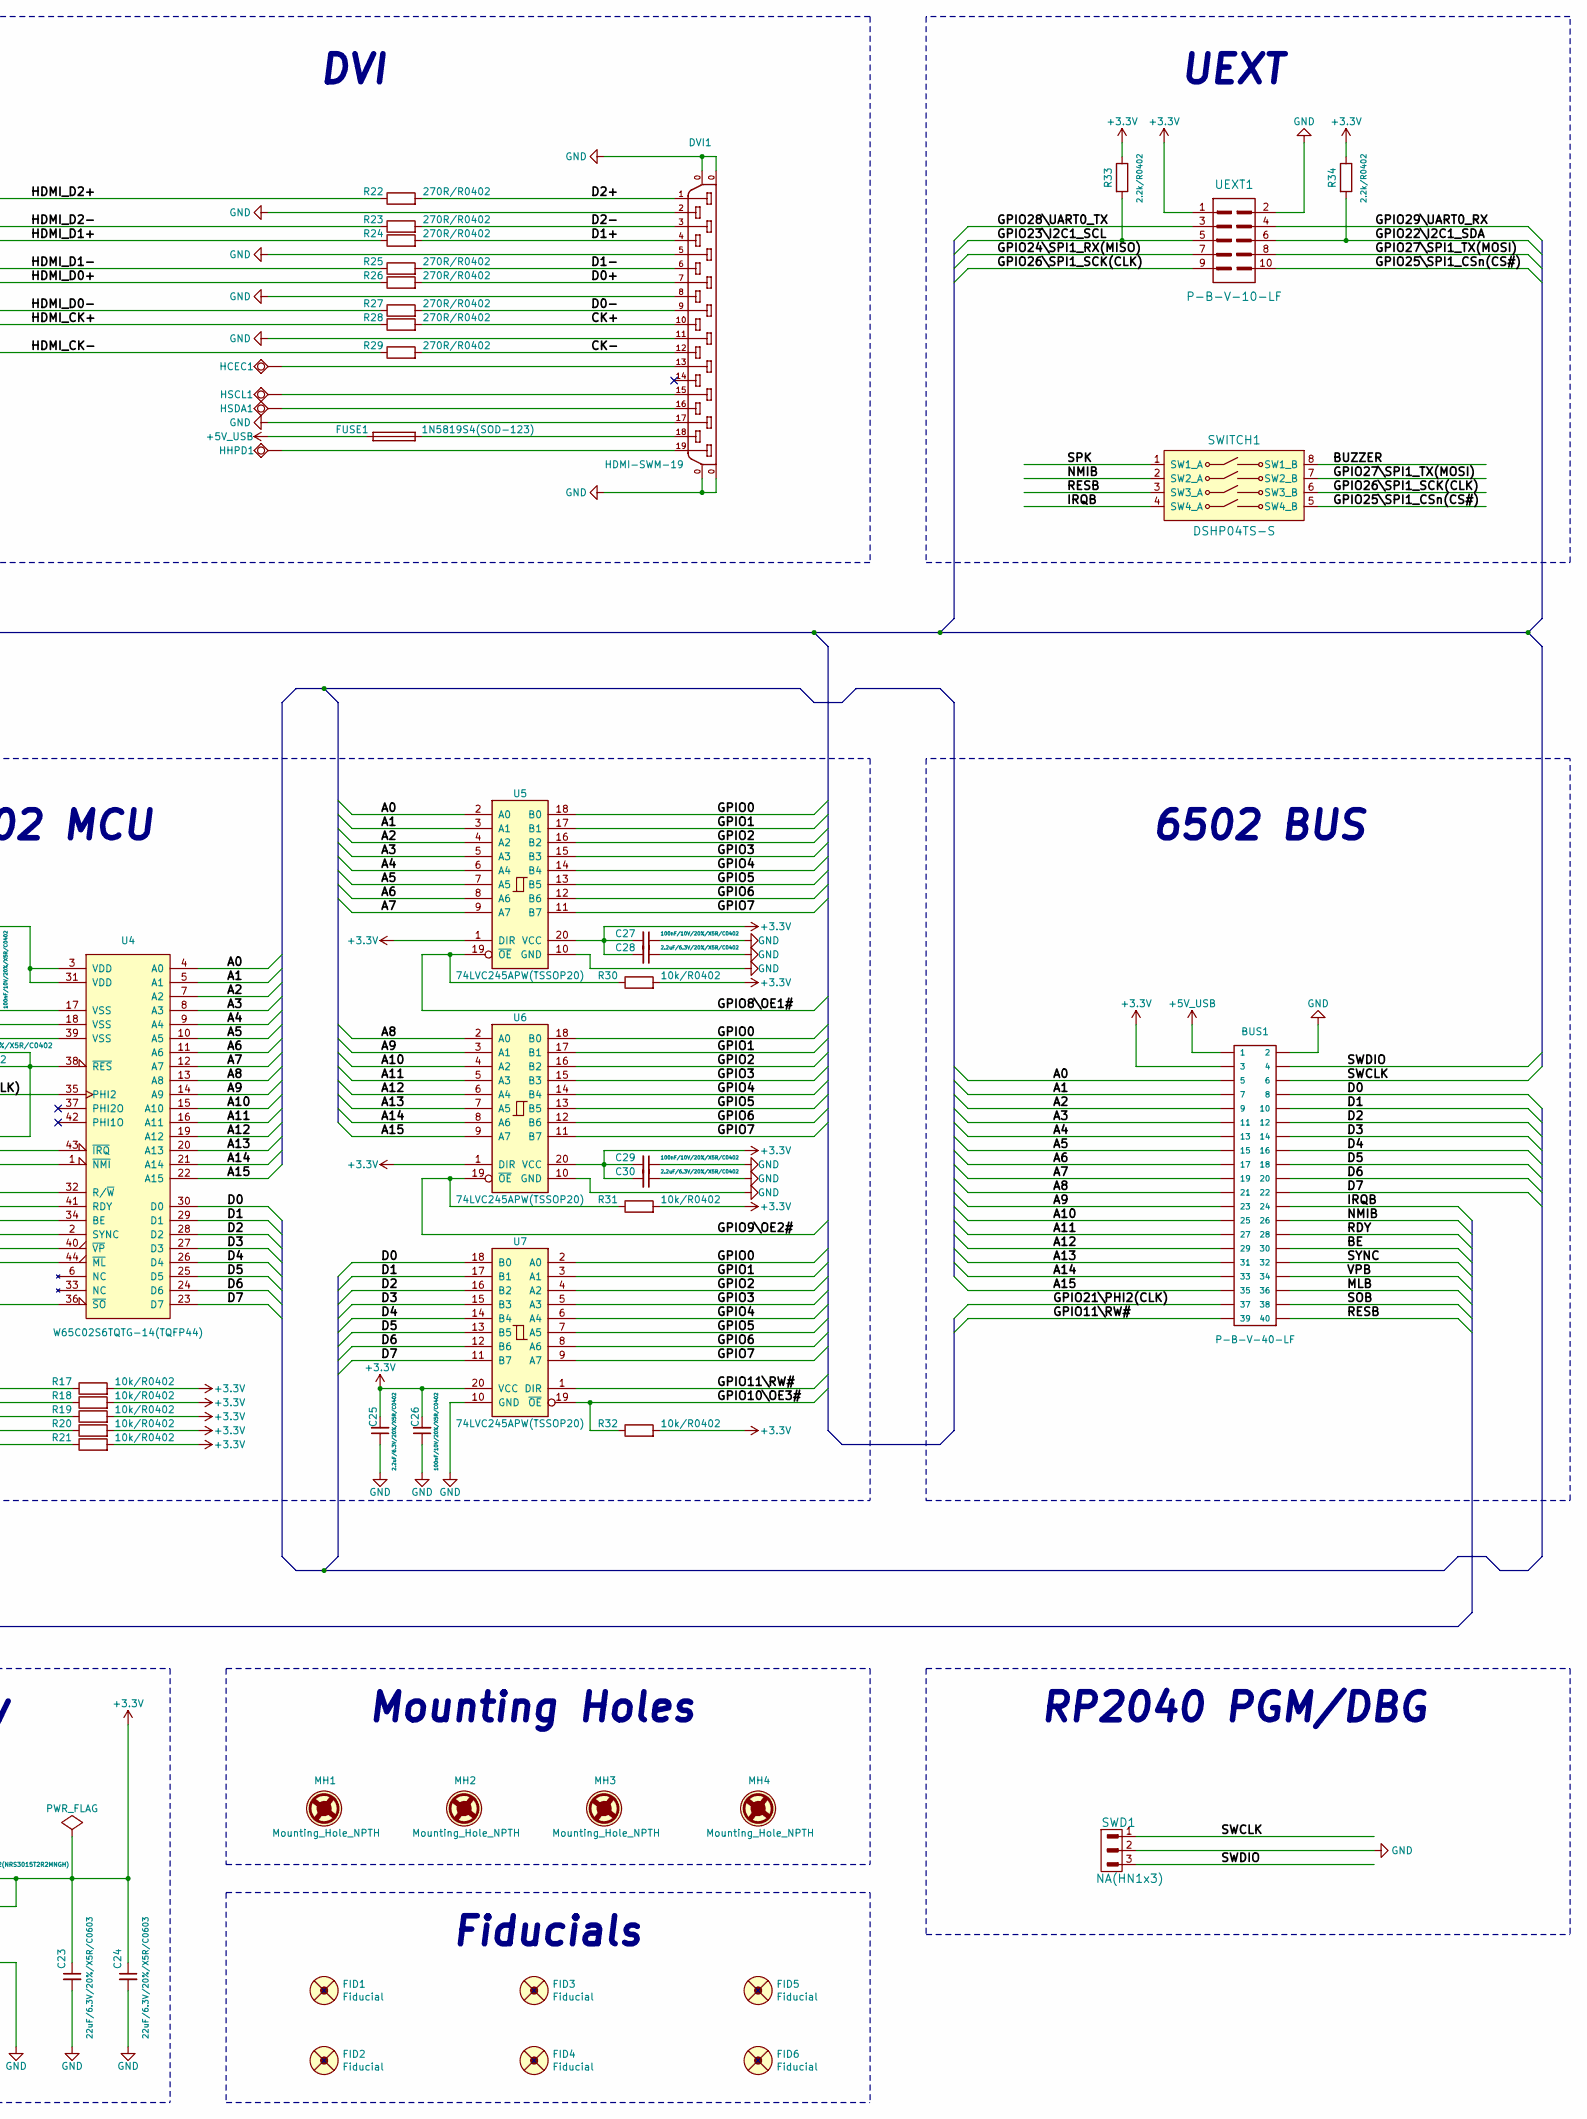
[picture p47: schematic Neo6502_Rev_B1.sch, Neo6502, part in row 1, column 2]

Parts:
AUDIO1: PJ-3.5-365-5P; SCJ325P00XG0B02G
BOOT1: YTS-A016-X
BUS1: P-B-V-40-LF; GBH-254-SMT-40
C1, C2, C3, C4, C5, C6, C7, C8, C9, C10, C13, C14, C18, C21, C22, C26, C27, C29: 100nF/10V/20%/X5R/C0402; C_0402_5MIL_DWS
C11, C12, C25, C28, C30: 2.2uF/6.3V/20%/X5R/C0402; C_0402_5MIL_DWS
C15, C16: 18pF/50V/5%/C0G/C0402; C_0402_5MIL_DWS
C17, C19, C20, C23, C24: 22uF/6.3V/20%/X5R/C0603; C_0603_5MIL_DWS
D1: 1N4148W/SOD123; SOD-123_1C-2A_KA
DVI1: HDMI-SWM-19; HDMI-SWM-19_Paste
FID1: Fiducial; Fiducial1x3_Past
FID2, FID3, FID4, FID5, FID6: Fiducial; Fiducial1x3
FUSE1: 1N5819S4(SOD-123); FUSE-1206
HCEC1: TESTPAD; TESTPAD_40-ROUND
HHPD1: TESTPAD; TESTPAD_40-ROUND
HSCL1: TESTPAD; TESTPAD_40-ROUND
HSDA1: TESTPAD; TESTPAD_40-ROUND
L1: 2.2uH/1.5A/DCR=58mR/20%/3.00x3.00x1.50mm/CD32(NRS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; CD32
MH1, MH2, MH3, MH4: Mounting_Hole_NPTH; Mounting_Hole_Drill-3.3mm_Clerance-7mm
PWR_LED1: LED/RED/0603; LED_0603_KA
Q1: Q12MHz/20pF/10ppm/4P/3.2x2.5mm; TSX-3.2x2.5mm_GND(3)
Q2: BC817-40(SOT23); SOT23
R1, R14, R17, R18, R19, R20, R21, R30, R31, R32: 10k/R0402; R_0402_5MIL_DWS
R2: NA(10k/R0402); R_0402_5MIL_DWS
R3, R6: 100R/R0402; R_0402_5MIL_DWS
R4, R5: 27R/R0402; R_0402_5MIL_DWS
R7: 47R/R1206; R_1206_5MIL_DWS
R8, R13, R33, R34: 2.2k/R0402; R_0402_5MIL_DWS
R9: 150R/R0402; R_0402_5MIL_DWS
R10, R12: 5.1k/1%/R0402; R_0402_5MIL_DWS
R11, R22, R23, R24, R25, R26, R27, R28, R29: 270R/R0402; R_0402_5MIL_DWS
R15: 220k/R0402; R_0402_5MIL_DWS
R16: 49.9k/1%/R0402; R_0402_5MIL_DWS
RM1, RM2: RA1206_(4x0603)_4B8_330R; RA1206_(4X0603)_4B8_xx
SPK1: Speaker_QMB-09B-03(1.5-5.0V_2.7kHz_F9.0mm*H5.5mm); Speaker_QMB-09B-03_1-Plus_2-Minus
SWD1: NA(HN1x3); HN1x3
SWITCH1: DSHP04TS-S; DSHP04TS-S-1.27mm_Half_4_Slide
U1: ZD25Q16BTIGT(SOIC-8_208mils); SO-8_208mil
U2: RP2040(QFN-56_7x7mm_P0.4mm); QFN56_7x7_Pitch_0.4mm
U3: SY8089AAAC(SOT23-5); SOT-23-5
U4: W65C02S6TQTG-14(TQFP44); TQFP44_NEO6502
U5, U6, U7: 74LVC245APW(TSSOP20); TSSOP20_Pitch-0.65mm_6.6x4.5x1.2mm
UEXT1: P-B-V-10-LF; GBH-254-SMT-10
USB-HOST1: USB-A-SMT-6.3H; USB-A-SMT-6.3H_HOST_Female
USB-PWR1: USB-C-16P-F(A40-00119-A52-12); USB2.0_TYPE-C(A40-00119-A52-12)_Paste

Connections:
+3.3V: BUS1.3, C1.2, C3.1, C4.1, C5.1, C6.1, C7.1, C8.1, C9.1, C10.1, C11.1, C20.1, C22.2, C23.1, C24.1, C25.2, C26.2, C27.2, C28.2, C29.2, C30.2, L1.2, R1.1, R2.1, R7.1, R14.1, R15.2, R17.2, R18.2, R19.2, R20.2, R21.2, R30.2, R31.2, R32.2, R33.1, R34.1, U1.8 (VCC), U2.1 (IOVDD), U2.10 (IOVDD), U2.22 (IOVDD), U2.33 (IOVDD), U2.42 (IOVDD), U2.43 (ADC_AVDD), U2.44 (VREG_VIN), U2.48 (USB_VDD), U2.49 (IOVDD), U4.3 (VDD), U4.31 (VDD), U5.1 (DIR), U5.20 (VCC), U6.1 (DIR), U6.20 (VCC), U7.20 (VCC), UEXT1.1
+5V_USB: BUS1.1, C19.1, FUSE1.1, PWR_LED1.2 (A), U3.1 (EN), U3.4 (IN), USB-HOST1.1 (VBUS), USB-PWR1.A4 (VBUS), USB-PWR1.A9 (VBUS), USB-PWR1.B4 (VBUS), USB-PWR1.B9 (VBUS)
/+1V1: C12.1, C13.1, C14.1, U2.23 (DVDD), U2.45 (VREG_VOUT), U2.50 (DVDD)
/A0: BUS1.5, U4.4 (A0), U5.2 (A0)
/A1: BUS1.7, U4.5 (A1), U5.3 (A1)
/A2: BUS1.9, U4.7 (A2), U5.4 (A2)
/A3: BUS1.11, U4.8 (A3), U5.5 (A3)
/A4: BUS1.13, U4.9 (A4), U5.6 (A4)
/A5: BUS1.15, U4.10 (A5), U5.7 (A5)
/A6: BUS1.17, U4.11 (A6), U5.8 (A6)
/A7: BUS1.19, U4.12 (A7), U5.9 (A7)
/A8: BUS1.21, U4.13 (A8), U6.2 (A0)
/A9: BUS1.23, U4.14 (A9), U6.3 (A1)
/A10: BUS1.25, U4.15 (A10), U6.4 (A2)
/A11: BUS1.27, U4.16 (A11), U6.5 (A3)
/A12: BUS1.29, U4.19 (A12), U6.6 (A4)
/A13: BUS1.31, U4.20 (A13), U6.7 (A5)
/A14: BUS1.33, U4.21 (A14), U6.8 (A6)
/A15: BUS1.35, U4.22 (A15), U6.9 (A7)
/BE: BUS1.30, R20.1, U4.34 (BE)
/BUZZER: AUDIO1.4, AUDIO1.5, SWITCH1.8 (SW1_B)
/CK+: DVI1.10, R28.2
/CK-: DVI1.12, R29.2
/CLK: U1.6 (CLK), U2.52 (QSPI_SCLK(Soft_GPIO))
/CSn: R1.2, R6.1, U1.1 (#CS), U2.56 (QSPI_SS_N(Soft_GPIO))
/D0: BUS1.8, U4.30 (D0), U7.18 (B0)
/D0+: DVI1.7, R26.2
/D0-: DVI1.9, R27.2
/D1: BUS1.10, U4.29 (D1), U7.17 (B1)
/D1+: DVI1.4, R24.2
/D1-: DVI1.6, R25.2
/D2: BUS1.12, U4.28 (D2), U7.16 (B2)
/D2+: DVI1.1, R22.2
/D2-: DVI1.3, R23.2
/D3: BUS1.14, U4.27 (D3), U7.15 (B3)
/D4: BUS1.16, U4.26 (D4), U7.14 (B4)
/D5: BUS1.18, U4.25 (D5), U7.13 (B5)
/D6: BUS1.20, U4.24 (D6), U7.12 (B6)
/D7: BUS1.22, U4.23 (D7), U7.11 (B7)
/D+: R5.2, U2.47 (USB_DP)
/D-: R4.2, U2.46 (USB_DM)
/D_N: USB-PWR1.A7 (DN1), USB-PWR1.B7 (DN2)
/D_P: USB-PWR1.A6 (DP1), USB-PWR1.B6 (DP2)
/GPIO0: RM1.4.2, U5.18 (B0), U6.18 (B0), U7.2 (A0)
/GPIO1: RM1.3.2, U5.17 (B1), U6.17 (B1), U7.3 (A1)
/GPIO2: RM1.2.2, U5.16 (B2), U6.16 (B2), U7.4 (A2)
/GPIO3: RM1.1.2, U5.15 (B3), U6.15 (B3), U7.5 (A3)
/GPIO4: RM2.4.2, U5.14 (B4), U6.14 (B4), U7.6 (A4)
/GPIO5: RM2.3.2, U5.13 (B5), U6.13 (B5), U7.7 (A5)
/GPIO6: RM2.2.2, U5.12 (B6), U6.12 (B6), U7.8 (A6)
/GPIO7: RM2.1.2, U5.11 (B7), U6.11 (B7), U7.9 (A7)
/GPIO8\OE1#: R30.1, U2.11 (GPIO8/SPI1_RX/UART1_TX/I2C0_SDA/PWM4_A/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), U5.19 (~OE)
/GPIO9\OE2#: R31.1, U2.12 (GPIO9/SPI1_CSn/UART1_RX/I2C0_SCL/PWM4_B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), U6.19 (~OE)
/GPIO10\OE3#: R32.1, U2.13 (GPIO10/SPI1_SCK/UART1_CTS/I2C1_SDA/PWM5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), U7.19 (~OE)
/GPIO11\RW#: BUS1.39, U2.14 (GPIO11/SPI1_TX/UART1_RTS/I2C1_SCL/PWM5_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), U4.32 (R/~W), U7.1 (DIR)
/GPIO20\AUDIO: R11.2, U2.31 (GPIO20/SPI0_RX/UART1_TX/I2C0_SDA/PWM2_A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)
/GPIO21\PHI2(CLK): BUS1.37, U2.32 (GPIO21/SPI0_CSn/UART1_RX/I2C0_SCL/PWM2_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), U4.35 (PHI2)
/GPIO22\I2C1_SDA: R34.2, U2.34 (GPIO22/SPI0_SCK/UART1_CTS/I2C1_SDA/PWM3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), UEXT1.6
/GPIO23\I2C1_SCL: R33.2, U2.35 (GPIO23/SPI0_TX/UART1_RTS/I2C1_SCL/PWM3_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), UEXT1.5
/GPIO24\SPI1_RX(MISO): U2.36 (GPIO24/SPI1_RX/UART1_TX/I2C0_SDA/PWM4_A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), UEXT1.7
/GPIO25\SPI1_CSn(CS#): SWITCH1.5 (SW4_B), U2.37 (GPIO25/SPI1_CSn/UART1_RX/I2C0_SCL/PWM4_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), UEXT1.10
/GPIO26\SPI1_SCK(CLK): SWITCH1.6 (SW3_B), U2.38 (GPIO26/ADC0/SPI1_SCK/UART1_CTS/I2C1_SDA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), UEXT1.9
/GPIO27\SPI1_TX(MOSI): SWITCH1.7 (SW2_B), U2.39 (GPIO27/ADC1/SPI1_TX/UART1_RTS/I2C1_SCL/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), UEXT1.8
/GPIO28\UART0_TX: U2.40 (GPIO28/ADC2/SPI1_RX/UART0_TX/I2C0_SDA/P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), UEXT1.3
/GPIO29\UART0_RX: U2.41 (GPIO29/ADC3/SPI1_CSn/UART0_RX/I2C0_SCL/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), UEXT1.4
/HDMI_CK+: R28.1, U2.16 (GPIO13/SPI1_CSn/UART0_RX/I2C0_SCL/PWM6_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)
/HDMI_CK-: R29.1, U2.15 (GPIO12/SPI1_RX/UART0_TX/I2C0_SDA/PWM6_A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)
/HDMI_D0+: R26.1, U2.18 (GPIO15/SPI1_TX/UART0_RTS/I2C1_SCL/PWM7_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)
/HDMI_D0-: R27.1, U2.17 (GPIO14/SPI1_SCK/UART0_CTS/I2C1_SDA/PWM7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)
/HDMI_D1+: R24.1, U2.30 (GPIO19/SPI0_TX/UART0_RTS/I2C1_SCL/PWM1_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)
/HDMI_D1-: R25.1, U2.29 (GPIO18/SPI0_SCK/UART0_CTS/I2C1_SDA/PWM1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)
/HDMI_D2+: R22.1, U2.28 (GPIO17/SPI0_CSn/UART0_RX/I2C0_SCL/PWM0_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)
/HDMI_D2-: R23.1, U2.27 (GPIO16/SPI0_RX/UART0_TX/I2C0_SDA/PWM0_A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)
/IO0: U1.5 (DI(IO0)), U2.53 (QSPI_SD0(Soft_GPIO))
/IO1: U1.2 (DO(IO1)), U2.55 (QSPI_SD1(Soft_GPIO))
/IO2: U1.3 (#WP(IO2)), U2.54 (QSPI_SD2(Soft_GPIO))
/IO3: U1.7 (#HOLD(IO3)), U2.51 (QSPI_SD3(Soft_GPIO))
/IRQB: BUS1.24, R18.1, SWITCH1.4 (SW4_A), U4.43 (~IRQ)
/MLB: BUS1.36, U4.44 (~ML)
/NMIB: BUS1.26, R19.1, SWITCH1.2 (SW2_A), U4.1 (~NMI)
/RDY: BUS1.28, R17.1, U4.41 (RDY)
/RESB: BUS1.40, C21.1, R14.2, SWITCH1.3 (SW3_A), U4.38 (~RES)
/RUN: C2.1, R2.2, U2.26 (RUN(RESET#))
/SOB: BUS1.38, R21.1, U4.36 (~SO)
/SPK: Q2.1 (B), R8.1, SWITCH1.1 (SW1_A)
/SWCLK: BUS1.6, SWD1.1, U2.24 (SWCLK)
/SWDIO: BUS1.4, SWD1.3, U2.25 (SWDIO)
/SYNC: BUS1.32, U4.2 (SYNC)
/USB_D+: R5.1, USB-HOST1.3 (D+)
/USB_D-: R4.1, USB-HOST1.2 (D-)
/VPB: BUS1.34, U4.40 (~VP)
/~BOOTSEL: BOOT1.1, R6.2
GND: AUDIO1.2, BOOT1.2, BUS1.2, C1.1, C2.2, C3.2, C4.2, C5.2, C6.2, C7.2, C8.2, C9.2, C10.2, C11.2, C12.2, C13.2, C14.2, C15.2, C16.2, C18.2, C19.2, C20.2, C21.2, C22.1, C23.2, C24.2, C25.1, C26.1, C27.1, C28.1, C29.1, C30.1, DVI1.0 (20), DVI1.2, DVI1.5, DVI1.8, DVI1.11, DVI1.17, Q1.3 (case), Q2.2 (E), R9.2, R10.1, R12.1, R13.2, R16.2, SWD1.2, U1.4 (GND), U2.19 (TESTEN(GND)), U2.57 (GND(EPAD)), U3.2 (GND), U4.17 (VSS), U4.18 (VSS), U4.39 (VSS), U5.10 (GND), U6.10 (GND), U7.10 (GND), UEXT1.2, USB-HOST1.4 (GND), USB-HOST1.5 (SHIELD), USB-PWR1.0 (SHELL), USB-PWR1.A1 (GND), USB-PWR1.A12 (GND), USB-PWR1.B1 (GND), USB-PWR1.B12 (GND)
unnamed: AUDIO1.1, AUDIO1.3, C17.2
unnamed: C15.1, Q1.1, R3.1
unnamed: C16.1, Q1.2, U2.20 (XIN)
unnamed: C17.1, C18.1, R9.1, R11.1
unnamed: D1.1 (K), R7.2, SPK1.1 (PLUS)
unnamed: D1.2 (A), Q2.3 (C), R8.2, SPK1.2 (MINUS)
unnamed: DVI1.13, HCEC1.1
unnamed: DVI1.15, HSCL1.1
unnamed: DVI1.16, HSDA1.1
unnamed: DVI1.18, FUSE1.2
unnamed: DVI1.19, HHPD1.1
unnamed: L1.1, U3.3 (LX)
unnamed: PWR_LED1.1 (K), R13.1
unnamed: R3.2, U2.21 (XOUT)
unnamed: R10.2, USB-PWR1.B5 (CC2)
unnamed: R12.2, USB-PWR1.A5 (CC1)
unnamed: R15.1, R16.1, U3.5 (FB)
unnamed: RM1.1.1, U2.5 (GPIO3/SPI0_TX/UART0_RTS/I2C1_SCL/PWM1_B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)
unnamed: RM1.2.1, U2.4 (GPIO2/SPI0_SCK/UART0_CTS/I2C1_SDA/PWM1_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)
unnamed: RM1.3.1, U2.3 (GPIO1/SPI0_CSn/UART0_RX/I2C0_SCL/PWM0_B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)
unnamed: RM1.4.1, U2.2 (GPIO0/SPI0_RX/UART0_TX/I2C0_SDA/PWM0_A/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)
unnamed: RM2.1.1, U2.9 (GPIO7/SPI0_TX/UART1_RTS/I2C1_SCL/PWM3_B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)
unnamed: RM2.2.1, U2.8 (GPIO6/SPI0_SCK/UART1_CTS/I2C1_SDA/PWM3_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)
unnamed: RM2.3.1, U2.7 (GPIO5/SPI0_CSn/UART1_RX/I2C0_SCL/PWM2_B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)
unnamed: RM2.4.1, U2.6 (GPIO4/SPI0_RX/UART1_TX/I2C0_SDA/PWM2_A/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)

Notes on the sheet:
Fiducials
Mounting Holes
Audio
UEXT
6502 BUS
Power Supply
Vout=0.6*(1+Ra/Rb)
Flash Memory 16Mbit(2MB)
Close to RPi!
QSPI pins of RP2040 should be wired directly to the flash, using short connections
USB-PWR
RP2040
6502 MCU
USB-Host
(Keyboard)
DVI
RP2040 PGM/DBG
Coil Resistance = 16R Current(max) = 50mA

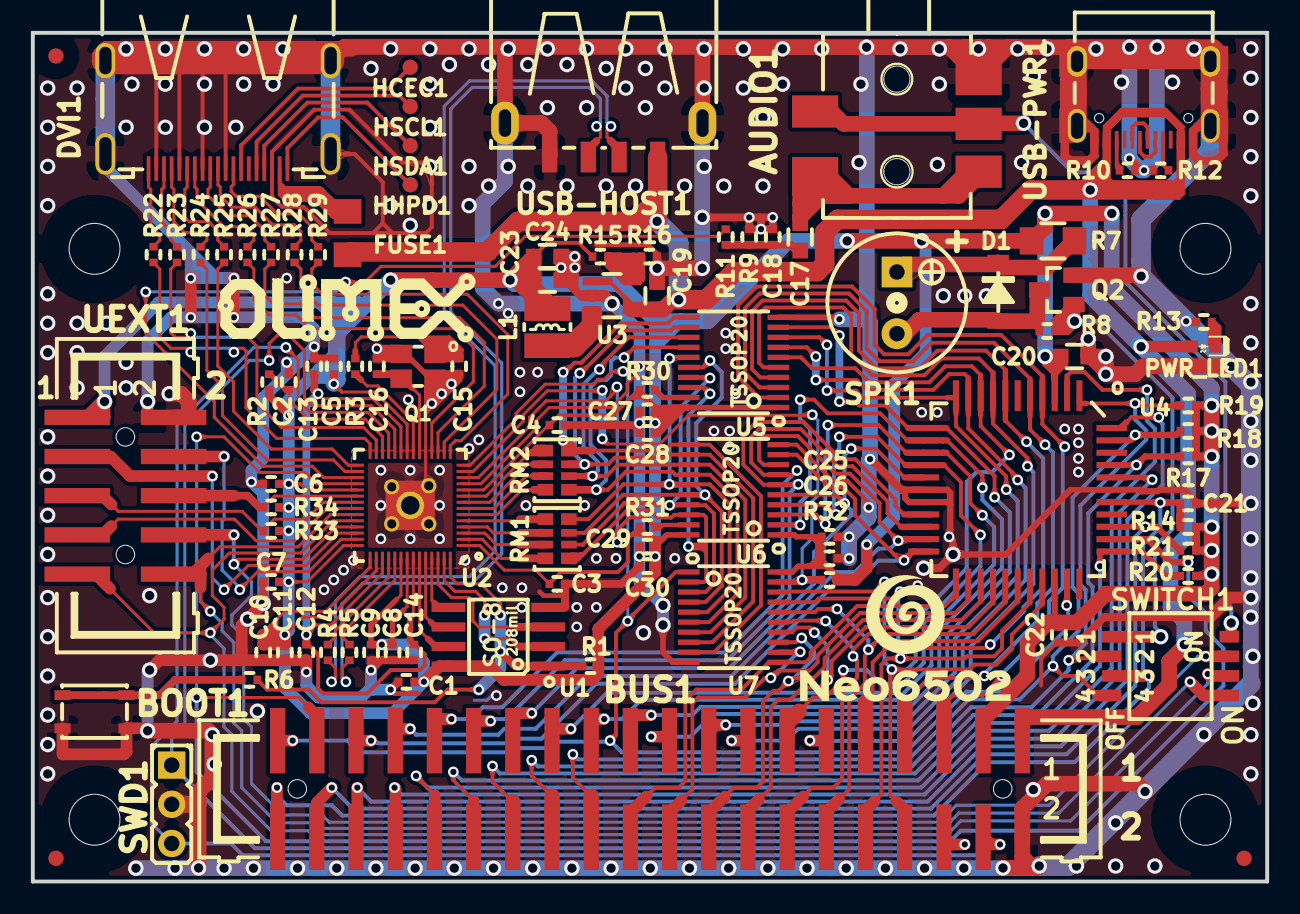
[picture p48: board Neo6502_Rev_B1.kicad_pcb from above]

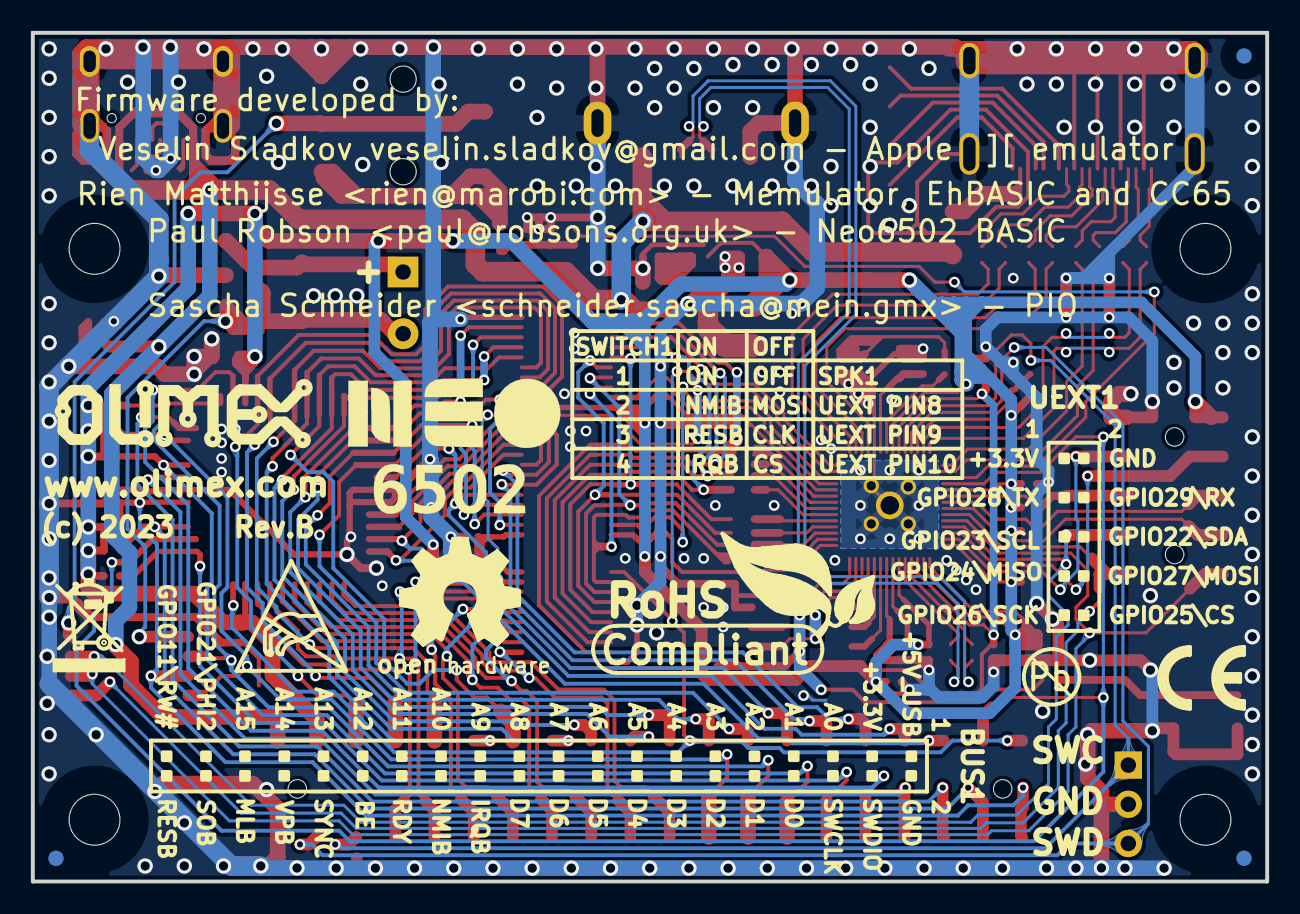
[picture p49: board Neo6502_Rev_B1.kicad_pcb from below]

Board: 2 copper layers, 80.0 x 55.0 mm, 113 parts (11 on the bottom side), 118 nets.

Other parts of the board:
Logo_OLIMEX_TB-Bottom: Logo_OLIMEX_TB
Logo_OLIMEX_TB-Top: Logo_OLIMEX_TB
NEO6502_NEW: LOGO; Neo6502_Sign_Small_NEW2
NEO_LOGO_SMALL*: LOGO; Neo6502_Sign_Small
Sign_Antistatic: Sign_Antistatic
Sign_CE: CE_Sign
Sign_OSHW_8x8: Sign_OSHW_8x8
Sign_PB-Free: Sign_PB-Free
Sign_RecycleBin: Sign_RecycleBin; Sign_RecycleBin_1
Sign_RoHS: Sign_RoHS; Sign_RoHS_1

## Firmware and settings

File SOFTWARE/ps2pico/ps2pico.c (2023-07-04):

/*
 * The MIT License (MIT)
 *
 * Copyright (c) 2022 No0ne (https://github.com/No0ne)
 *
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
 */

#include "ps2device.pio.h"
#include "hardware/gpio.h"
#include "bsp/board.h"
#include "tusb.h"
#include "pico/stdlib.h"

#define CLKIN  22
#define CLKOUT 23
#define DATIN  28
#define DATOUT 29

uint8_t const led2ps2[] = { 0, 4, 1, 5, 2, 6, 3, 7 };
uint8_t const mod2ps2[] = { 0x14, 0x12, 0x11, 0x1f, 0x14, 0x59, 0x11, 0x27 };
uint8_t const hid2ps2[] = {
  0x00, 0x00, 0xfc, 0x00, 0x1c, 0x32, 0x21, 0x23, 0x24, 0x2b, 0x34, 0x33, 0x43, 0x3b, 0x42, 0x4b,
  0x3a, 0x31, 0x44, 0x4d, 0x15, 0x2d, 0x1b, 0x2c, 0x3c, 0x2a, 0x1d, 0x22, 0x35, 0x1a, 0x16, 0x1e,
  0x26, 0x25, 0x2e, 0x36, 0x3d, 0x3e, 0x46, 0x45, 0x5a, 0x76, 0x66, 0x0d, 0x29, 0x4e, 0x55, 0x54,
  0x5b, 0x5d, 0x5d, 0x4c, 0x52, 0x0e, 0x41, 0x49, 0x4a, 0x58, 0x05, 0x06, 0x04, 0x0c, 0x03, 0x0b,
  0x83, 0x0a, 0x01, 0x09, 0x78, 0x07, 0x7c, 0x7e, 0x7e, 0x70, 0x6c, 0x7d, 0x71, 0x69, 0x7a, 0x74,
  0x6b, 0x72, 0x75, 0x77, 0x4a, 0x7c, 0x7b, 0x79, 0x5a, 0x69, 0x72, 0x7a, 0x6b, 0x73, 0x74, 0x6c,
  0x75, 0x7d, 0x70, 0x71, 0x61, 0x2f, 0x37, 0x0f, 0x08, 0x10, 0x18, 0x20, 0x28, 0x30, 0x38, 0x40,
  0x48, 0x50, 0x57, 0x5f
};
uint8_t const maparray = sizeof(hid2ps2) / sizeof(uint8_t);

PIO pio = pio0;
uint sm;
uint offset;

bool kbd_enabled = true;
uint8_t kbd_addr = 0;
uint8_t kbd_inst = 0;

bool blinking = false;
bool repeating = false;
uint32_t repeat_us = 35000;
uint16_t delay_ms = 250;
alarm_id_t repeater;

uint8_t prev_rpt[] = { 0, 0, 0, 0, 0, 0, 0, 0 };
uint8_t prev_ps2 = 0;
uint8_t resend = 0;
uint8_t repeat = 0;
uint8_t leds = 0;

int64_t repeat_callback(alarm_id_t id, void *user_data) {
  if(repeat) {
    repeating = true;
    return repeat_us;
  }
  
  repeater = 0;
  return 0;
}

uint16_t ps2_frame(uint8_t data) {
  uint8_t parity = 1;
  for(uint8_t i = 0; i < 8; i++) {
    parity = parity ^ (data >> i & 1);
  }
  
  return ((1 << 10) | (parity << 9) | (data << 1)) ^ 0x7ff;
}

void ps2_send(uint8_t data) {
  // uint8_t timeout = 10;
//  gpio_put(25, 1);
  resend = data;
  pio_sm_put(pio, sm, ps2_frame(data));
//  gpio_put(25, 0);
}

void maybe_send_e0(uint8_t data) {
  if(data == 0x46 ||
     data >= 0x48 && data <= 0x52 ||
     data == 0x54 || data == 0x58 ||
     data == 0x65 || data == 0x66 ||
     data >= 0x81) {
    ps2_send(0xe0);
  }
}

void kbd_set_leds(uint8_t data) {
  if(data > 7) data = 0;
  leds = led2ps2[data];
  tuh_hid_set_report(kbd_addr, kbd_inst, 0, HID_REPORT_TYPE_OUTPUT, &leds, sizeof(leds));
}

int64_t blink_callback(alarm_id_t id, void *user_data) {
  if(kbd_addr) {
    if(blinking) {
      kbd_set_leds(7);
      blinking = false;
      return 500000;
    } else {
      kbd_set_leds(0);
      ps2_send(0xaa);
    }
  }
  return 0;
}

void ps2_receive(uint32_t fifo) {
  fifo = fifo >> 23;
  
  uint8_t parity = 1;
  for(uint8_t i = 0; i < 8; i++) {
    parity = parity ^ (fifo >> i & 1);
  }
  
  if(parity != fifo & 0x100) {
    ps2_send(0xfe);
    return;
  }
  
  uint8_t data = fifo;
  
  switch(prev_ps2) {
    case 0xed: // CMD: Set LEDs
      prev_ps2 = 0;
      kbd_set_leds(data);
    break;
    
    case 0xf3: // CMD: Set typematic rate and delay
      prev_ps2 = 0;
      repeat_us = data & 0x1f;
      delay_ms = data & 0x60;
      
      repeat_us = 35000 + repeat_us * 15000;
      
      if(delay_ms == 0x00) delay_ms = 250;
      if(delay_ms == 0x20) delay_ms = 500;
      if(delay_ms == 0x40) delay_ms = 750;
      if(delay_ms == 0x60) delay_ms = 1000;
    break;
    
    default:
      switch(data) {
        case 0xff: // CMD: Reset
          kbd_enabled = true;
          blinking = true;
          add_alarm_in_ms(1, blink_callback, NULL, false);
          
          pio_sm_clear_fifos(pio, sm);
          pio_sm_drain_tx_fifo(pio, sm);
          ps2_send(0xfa);
        return;
        
        case 0xfe: // CMD: Resend
          ps2_send(resend);
        return;
        
        case 0xee: // CMD: Echo
          ps2_send(0xee);
        return;
        
        case 0xf2: // CMD: Identify keyboard
          ps2_send(0xfa);
          ps2_send(0xab);
          ps2_send(0x83);
        return;
        
        case 0xf3: // CMD: Set typematic rate and delay
        case 0xed: // CMD: Set LEDs
          prev_ps2 = data;
        break;
        
        case 0xf4: // CMD: Enable scanning
          kbd_enabled = true;
        break;
        
        case 0xf5: // CMD: Disable scanning, restore default parameters
        case 0xf6: // CMD: Set default parameters
          kbd_enabled = data == 0xf6;
          repeat_us = 35000;
          delay_ms = 250;
          kbd_set_leds(0);
        break;
      }
    break;
  }
  
  ps2_send(0xfa);
}

void tuh_hid_mount_cb(uint8_t dev_addr, uint8_t instance, uint8_t const* desc_report, uint16_t desc_len) {
  if(tuh_hid_interface_protocol(dev_addr, instance) == HID_ITF_PROTOCOL_KEYBOARD) {
    kbd_addr = dev_addr;
    kbd_inst = instance;
    
    blinking = true;
    add_alarm_in_ms(1, blink_callback, NULL, false);
    
    tuh_hid_receive_report(dev_addr, instance);
  }
}

void tuh_hid_umount_cb(uint8_t dev_addr, uint8_t instance) {
  if(dev_addr == kbd_addr && instance == kbd_inst) {
    kbd_addr = 0;
    kbd_inst = 0;
  }
}

void tuh_hid_report_received_cb(uint8_t dev_addr, uint8_t instance, uint8_t const* report, uint16_t len) {
  if(dev_addr == kbd_addr && instance == kbd_inst) {
    
    if(!kbd_enabled || report[1] != 0) {
      tuh_hid_receive_report(dev_addr, instance);
      return;
    }
    
    board_led_write(1);
    
    if(report[0] != prev_rpt[0]) {
      uint8_t rbits = report[0];
      uint8_t pbits = prev_rpt[0];
      
      for(uint8_t j = 0; j < 8; j++) {
        
        if((rbits & 0x01) != (pbits & 0x01)) {
          if(j > 2 && j != 5) ps2_send(0xe0);
          
          if(rbits & 0x01) {
            ps2_send(mod2ps2[j]);
          } else {
            ps2_send(0xf0);
            ps2_send(mod2ps2[j]);
          }
        }
        
        rbits = rbits >> 1;
        pbits = pbits >> 1;
        
      }
      
      prev_rpt[0] = report[0];
    }
    
    for(uint8_t i = 2; i < 8; i++) {
      if(prev_rpt[i]) {
        bool brk = true;
        
        for(uint8_t j = 2; j < 8; j++) {
          if(prev_rpt[i] == report[j]) {
            brk = false;
            break;
          }
        }
        
        if(brk && report[i] < maparray) {
          if(prev_rpt[i] == 0x48) continue;
          if(prev_rpt[i] == repeat) repeat = 0;
          
          maybe_send_e0(prev_rpt[i]);
          ps2_send(0xf0);
          ps2_send(hid2ps2[prev_rpt[i]]);
        }
      }
      
      if(report[i]) {
        bool make = true;
        
        for(uint8_t j = 2; j < 8; j++) {
          if(report[i] == prev_rpt[j]) {
            make = false;
            break;
          }
        }
        
        if(make && report[i] < maparray) {
          if(report[i] == 0x48) {
            
            if(report[0] & 0x1 || report[0] & 0x10) {
              ps2_send(0xe0); ps2_send(0x7e); ps2_send(0xe0); ps2_send(0xf0); ps2_send(0x7e);
            } else {
              ps2_send(0xe1); ps2_send(0x14); ps2_send(0x77); ps2_send(0xe1);
              ps2_send(0xf0); ps2_send(0x14); ps2_send(0xf0); ps2_send(0x77);
            }
            
            continue;
          }
          
          repeat = report[i];
          if(repeater) cancel_alarm(repeater);
          repeater = add_alarm_in_ms(delay_ms, repeat_callback, NULL, false);
          
          maybe_send_e0(report[i]);
          ps2_send(hid2ps2[report[i]]);
        }
      }
      
      prev_rpt[i] = report[i];
    }
    
    tuh_hid_receive_report(dev_addr, instance);
    board_led_write(0);
    
  }
}

void irq_callback(uint gpio, uint32_t events) {
  if(!gpio_get(DATIN) && !pio_interrupt_get(pio, 0)) {
    board_led_write(1);
    pio_sm_drain_tx_fifo(pio, sm);
    pio_sm_exec(pio, sm, pio_encode_jmp(offset + 2));
  }
}

void main() {

  //gpio_init(25);
  //gpio_set_dir(25, GPIO_OUT);
  //gpio_put(25, 1);

  board_init();
  
  sm = pio_claim_unused_sm(pio, true);
  offset = pio_add_program(pio, &ps2dev_program);
  ps2dev_program_init(pio, sm, offset, CLKIN, CLKOUT, DATIN, DATOUT);
  
  gpio_set_irq_enabled_with_callback(CLKIN, GPIO_IRQ_EDGE_RISE, true, &irq_callback);
  tusb_init();
  
  while(true) {
    tuh_task();
    
    if(!pio_sm_is_rx_fifo_empty(pio, sm)) {
      ps2_receive(pio_sm_get(pio, sm));
      board_led_write(0);
    }
    
    if(repeating) {
      repeating = false;
      
      if(repeat) {
        maybe_send_e0(repeat);
        ps2_send(hid2ps2[repeat]);
      }
    }
  }
}

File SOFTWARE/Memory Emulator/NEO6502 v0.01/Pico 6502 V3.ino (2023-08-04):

/*
 Name:		Pico_NEO6502
 Author:	Rien Matthijsse

 Inspired by work  http://www.8bitforce.com/blog/2019/03/12/retroshield-6502-operation/
*/

#include "pico/stdio.h"

#include "pico/stdlib.h"
#include "pico/time.h"

#ifdef OVERCLOCK
#include "hardware/clocks.h"
#include "hardware/vreg.h"
#endif

#include "mos65C02.h"
#include "memory.h"
#include "m6821.h"

// Delay startup by so many seconds
#define START_DELAY 0

// 1-bit (black, white) text mode for PicoDVI.
#include <PicoDVI.h>

// Here's how an 80x30 character display is declared.
DVItext1 display(DVI_RES_640x480p60, pico_neo6502_cfg);

//
uint32_t  clockCount = 0UL;
unsigned long  lastClockTS;
boolean  statusCursor = true;

/// <summary>
/// performa a action on the display
/// </summary>
/// <param name="vCmd"></param>
void setCommand(uint8_t vCmd) {
  switch (vCmd) {
  case 0x01: // clearscreen
//    Serial.println("CLS");
    display.fillScreen(0);
    display.setCursor(0, 0);
    break;
  }
}

/// <summary>
/// 
/// </summary>
/// <param name="vSet"></param>
void showCursor(boolean vSet) {
  statusCursor = vSet;
}

/// <summary>
/// get current x-pos of cursor
/// </summary>
/// <returns></returns>
uint8_t getCursorX() {
  return display.getCursorX();
}

/// <summary>
/// get current y-pos of cursor
/// </summary>
/// <returns></returns>
uint8_t getCursorY() {
  return display.getCursorY();
}

/// <summary>
/// set x-pos of cursor
/// </summary>
/// <param name="vX"></param>
void setCursorX(uint8_t vX) {
  display.setCursor(vX % 80, display.getCursorY());
}

/// <summary>
/// set y-pos of cursor
/// </summary>
/// <param name="vY"></param>
void setCursorY(uint8_t vY) {
  display.setCursor(display.getCursorX(), vY % 60);
}

/// <summary>
/// 
/// </summary>
inline __attribute__((always_inline))
void writeBS() {
  display.setCursor(display.getCursorX() - 1, display.getCursorY());
}

/// <summary>
///  write a char to output DVI output
/// </summary>
/// <param name="vChar"></param>
void writeChar(uint8_t vChar) {
  switch (vChar) {
  case 0x8D: // CR
  case 0x0D: // CR
    if (statusCursor)
      display.println(" ");
    else
      display.println("");
    break;
  case 0x88: // BS
  case 0x08: // BS
    display.write(' ');
    writeBS();
    if (statusCursor) {
      display.write('_');
      writeBS();
    }
    break;
  default:
    display.write(vChar);
    if (statusCursor) {
      display.write('_');
      writeBS();
    }
  }
}


////////////////////////////////////////////////////////////////////////////////////////////////////
/// <summary>
/// setup emulator
/// </summary>
void setup() {
  Serial.begin(115200);
  //  while (!Serial);

  sleep_ms(2500);
  Serial.println("NEO6502 memulator v0.01");

  if (!display.begin()) {
    Serial.println("ERROR: not enough RAM available");
    for (;;);
  }

  for (uint8_t i = START_DELAY; i > 0; i--) {
    Serial.printf("Starting in %d \n", i);
    sleep_ms(1000);
  }
  Serial.printf("Starting\n");

  initmemory();

  init6821();

  init6502();
  reset6502();

  // 4 stats
  clockCount = 0UL;
  lastClockTS = millis();

  // and we have lift off
  display.println("NEO6502 memulator v0.01");
}

////////////////////////////////////////////////////////////////////
// Serial Event
////////////////////////////////////////////////////////////////////

/*
  SerialEvent occurs whenever a new data comes in the
  hardware serial RX. Multiple bytes of data may be available.
 */
inline __attribute__((always_inline))
void serialEvent1()
{
  if (Serial.available()) {
    if (Serial.peek() == 0x12) { // ^R
      byte ch = Serial.read();
      Serial.println("RESET");
      showCursor(true);
      reset6502();
    }
    else {
      if ((regKBDCR & 0x80) == 0x00) {    // read serial byte only if we can set 6821 interrupt
        cli();                            // stop interrupts while changing 6821 guts.
        // 6821 portA is available      
        byte ch = toupper(Serial.read()); // apple1 expects upper case
        regKBD = ch | 0x80;               // apple1 expects bit 7 set for incoming characters.
        //     Serial.printf("Pressed %02x\n", regKBD);
        regKBDCR |= 0x80;                 // set 6821 interrupt
        sei();
      }
    }
  }
  return;
}


/// <summary>
/// 
/// </summary>
void loop() {
  static uint16_t i, j = 1;

  tick6502(0UL);
  clockCount++;

  // Flush USB from time to time.
  if (j-- == 0) {
    gpio_put(25, LOW);

    serialEvent1();
    display.flush();

    j = 5000;

    gpio_put(25, HIGH);
  }

  if (i-- == 0) {
    if ((millis() - lastClockTS) >= 5000UL) {
      Serial.printf("kHz = %0.1f\n", clockCount / 5000.0);

      clockCount = 0UL;
      lastClockTS = millis();
    }

    i = 10000;
  }
}

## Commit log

2023-06-26 initial upload
    [Neo6502_Rev_A.kicad_pcb, Neo6502_Rev_A.sch]
2023-07-06 memory emulator 1.0
    [osi.cfg]
2023-07-21 Update
    Revision A release files uploaded
    [Audio_Jack-3.5mm---CUI_SJ1-3515-SMT-TR.step, GBH254SMT-10(B-V-10-LF)(IDC-Header_2x05_P2.54mm_Vertical_SMD).step, GBH254SMT-40(B-V-40-LF)(IDC-Header_2x20_P2.54m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]
2023-10-11 adding 3d printed case with MMU option
    [Neo6502_Rev_B v6-bottom.3mf, Neo6502_Rev_B v6-bottom.stl, Neo6502_Rev_B v6-top-MMU.3mf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]
2023-10-23 uploaded latest model files
    [Neo6502_Rev_B v10-top-MMU.3mf, Neo6502_Rev_B v6-bottom.3mf, Neo6502_Rev_B v6-bottom.stl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]
2023-10-23 renamed bottom part
    [Neo6502_Rev_B v10-bottom.3mf, Neo6502_Rev_B v10-bottom.stl]
2024-06-11 Update
    Added revision B1 and added revision changes notes
    [Audio_Jack-3.5mm---CUI_SJ1-3515-SMT-TR.step, GBH254SMT-10(B-V-10-LF)(IDC-Header_2x05_P2.54mm_Vertical_SMD).step, GBH254SMT-40(B-V-40-LF)(IDC-Header_2x20_P2.54m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]

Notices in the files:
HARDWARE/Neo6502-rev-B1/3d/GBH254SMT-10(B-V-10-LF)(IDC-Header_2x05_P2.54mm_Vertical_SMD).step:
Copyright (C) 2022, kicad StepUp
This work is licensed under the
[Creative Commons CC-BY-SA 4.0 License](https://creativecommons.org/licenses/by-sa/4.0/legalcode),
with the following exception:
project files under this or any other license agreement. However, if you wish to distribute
